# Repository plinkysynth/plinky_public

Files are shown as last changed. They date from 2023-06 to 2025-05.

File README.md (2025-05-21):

# plinky

an 8 voice touch synth - https://plinkysynth.com

Plinky started life as a hobby project that spiralled out of control, was sold for a while on Thonk as a kit, went out of stock during the post-covid chip shortage, and was then rescued by various wonderful people in the Plinky community. Alogn the way, it got open sourced - both hardware and software. You are in the right place for that!

## OPENSOURCE SOFTWARE CREDITS

You can see that the software has largely been stagnant since original release; however in early 2025, a hero by the name of **RJ** stepped up and contributed some incredible improvements, rewriting large parts of the Sequencer and MIDI implementation. Plinky as of version 0.B0 (to be released shortly at the time of writing) is going to be by far the best version of plinky Ever, by far. HUGE thanks to RJ for really pushing plinky closer to its full potential.

Release Notes are available in the [Release Notes](release_notes.md) document for the newer firmware versions.

If you want to get in on the action, join the Plinky Discord (see details at [plinkysynth.com](https://plinkysynth.com) and check out the `#beta-firwmare` channel) or check out the [sw/](/sw/) folder here. Special shout out to **@whocano** in that channel who beta-tested the new fixes from RJ. See, plinky is a team effort? It is truly a special community. Thankyou from the bottom of my heart. 

## OPENSOURCE HARDWARE CREDITS
But plinky is not just software; It's a physical thing!

Many thanks to the people who worked so hard to make opensource plinky a reality, far better than the original version (V1) and (V2) that I stumbled through creating. V3 was a product of the Plinky Discord community, especially:

* **Stijn** from [This Is Not Rocket Science](https://www.thisisnotrocketscience.nl/) routed the original Version 3.
* **Steve / Okyreon** from [denki oto](https://www.okyeron.com/denki_oto/about.php) added the LPZW midi circuit to allow plinky to have on-board midi without the expander.
* **Kay** from [LPZW Modules](https://leipzigwest.org/)  then contributed a circuit to fix the input noise, and then polished everything into a 'Version 3.1', which is the current version linked here. Kay also was one of the original people who helped me with the hardware design of V1 and V2.

If you contributed to the open source hardware and I forgot you, please shout at me @mmalex on the Plinky Discord.
Thanks to all the Plinky Discord members for making Plinky ever better!

Although this repo is all about the OSS Plinky, it is, as ever, available from [Thonk](https://www.thonk.co.uk/shop/plinky-kit-001/) in both prebuilt and kit form, and from other retailers including [Schneidersladen](https://schneidersladen.de/en/plinky/). Thanks to [MakingSoundMachines](https://makingsoundmachines.com/) and [LPZW Modules](https://leipzigwest.org/) for manufacturing those for people who are not looking for the full OSS experience :)

## original release note

For posterity, here is what I wrote at Stijn's coffee table as I released plinky into the public, not knowing what would become of it....

I apologise, its been so long since I looked at this, I am releasing a snapshot of what I had on my harddrive after a couple of years of barely being touched. while I am not actively developing plinky, I hope that by open sourcing it I can stimulate the wonderful community who collaborate on the plinky discord. I also hope to help iterate on some of the more obvious bugs, both hardware and software. 

If you are interested in plinky, please feel free to join our discord community. More information at https://plinkysynth.com

License stuff
--
Please refer to the [license](LICENSE.md) for information including stuff about derived works.

Contributing stuff
--
please see [CONTRIBUTING.md](CONTRIBUTING.md) for information on contributing to this project.

Building and stuff
--
**UPDATE Jan 2025** it is now possible to build and debug plinky using the arm-cortex-debug extension in VSCode. notes continue below:

you need [STM32 cube ide](https://www.st.com/en/development-tools/stm32cubeide.html), its basically the default project so most of the code is in [/sw/Core/Src](/sw/Core/Src), most of the rest of the [/sw](/sw) folder is just the usual auto generated boilerplate mess.

It would be a useful project to update the firmware to build with a more minimal setup; the only significant middleware used relates to USB; while I lean on the STM default project a little, I imagine that the peripheral code could be modified fairly easily.

it should also compile as an emulator for mac and windows, using portaudio and dear imgui. it also compiles for wasm, somehow... I imagine that following the path of the WASM emulator, it would be relatively easy to port plinky to software plugin type platforms.

there is also a [bootloader](/bootloader/) project... I forget exactly how it relates to the final build process. Consider that a TODO to document :)

the hardware is mostly in the [hw/](/hw/) folder, but I was new to kicad so I am not sure if all the library stuff is in the right place.

if there is something missing or something in there that you think shouldn't be in there, let me know and I can sort it out

Thanks again!
--
Many thanks to the plinky community, who have helped plinky evolve and kept the dream alive over a few years. 

* Thanks to Steve from https://thonk.co.uk who encouraged plinky into existence and helped produce the kits; 
* to Kay from https://leipzigwest.org/ for tireless hardware help, encouragment and pre-made plinkys! 
* To Stijn from http://www2.thisisnotrocketscience.nl/ for support, hardware help, and the impetus to opensource this. 
* To MakingSoundMachines from https://makingsoundmachines.com/ for carrying the torch for the new Thonk kits and prebuilt versions, as well as representing Plinky at shows such as Superbooth. 
* to RJ for the incredible bugfixes and rewrites in the firmware that make plinky actually usable as a midi device and touch sequencer. <3
* to Okyeron for V3 hardware work
* to Miunau for the plinky website and continual encouragement, and the original wavetables
* to Meska, LPZW and Grain Blanc for preset packs
* to CrazyEmperor893, SwampFlux, ld, orangetronic, Zifor, tubbutec and many others on the plinky discord for keeping plinky alive and well while I was away.
* to all the people I have missed out, I have a terrible memory, please shout at me if you can see anyone missing from this list who deserves to be here.

Cheers all! 

-- [mmalex](https://twitter.com/mmalex)

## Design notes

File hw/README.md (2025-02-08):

kicad hardware files for plinky
==

## OPENSOURCE HARDWARE CREDITS
Many thanks to the people who worked so hard to make opensource plinky a reality, far better than the original version.

* **Stijn** from [This Is Not Rocket Science](https://www.thisisnotrocketscience.nl/) routed the original Version 3.
* **Steve / Okyreon** from [denki oto](https://www.okyeron.com/denki_oto/about.php) added the LPZW midi circuit to allow plinky to have on-board midi without the expander.
* **Kay** from [LPZW Modules](https://leipzigwest.org/)  then contributed a circuit to fix the input noise, and then polished everything into a 'Version 3.1', which is the current version linked here. Kay also was one of the original people who helped me with the hardware design of V1 and V2.

If you contributed to the open source hardware and I forgot you, please shout at me @mmalex on the Plinky Discord.
Thanks to all the Plinky Discord members for making Plinky ever better!

------
## The Main Folders:

[BOM.md](/hw/BOM.md) contains a list of parts you'll need to recreate the kit, apart from the actual PCBs.

[plinkyblack](/hw/plinkyblack/) contains the files for the main plinky pcb, OSS edition. this was originally called v3.1 LPZW, and represents the latest and greatest OSS hardware release, thanks to LPZWModules for the most recent revision. See the credits paragraph above for more information on all the great people who helped on the hardware side to make OSS plinky a reality (and much better than the original plinky!)

[plinkyblackfront](/hw/plinkyblackfront/) contains files for the front and back panels. The plinky production runs with LEDs premade used front panels mdae by pcbway, while the ones without LEDs were made by jlcpcb. The back panels were made by jlcpcb.

[plinkyblackfront_osh](/hw/plinkyblackfront_osh/) is a variation of the front panel with the OSH logo replacing the plinky logo's dot on the i.

## Additional Folders:

[testjig](/hw/testjig/) contains files for the testjig used to test plinky and flash it, calibrate CVs and so on, used during manufacturing of the kits.

[expander](/hw/expander/) contains a snapshot of the expander, which is also available on [github](https://github.com/plinkysynth/plinky-expander)

## Older stuff:

There is also a big folder of archived old designs. this is now in [archived](/hw/archived/).

[archived/v2](/hw/archived/v2/) is the hardware design used most recently for plinky kits. it was manufactured by both pcbway and jlcpcb. there are BOM and POS files in here for JLCPCB to do the SMT assembly, and this was recently (jan-2023) tested in a small run.

[archived/WIP_inputfix](/hw/archived/WIP_inputfix/) has been updated to kicad 7 and has yet to be manufactured (as of june-2023); we are revising it to reduce input noise and improve the physical dimensions of some ports and the expander port hole.

[archived/plinkyblack_hwmidi](/hw/archived/plinkyblack_hwmidi/) Kicad 7 version modified by @okyeron which adds hardware MIDI in/out on the front of the device. Includes modifications from WIP_inputfix

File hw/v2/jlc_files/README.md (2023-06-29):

these are the most recent BOM and POS files I used to manufacture plinky mainboards at JLC. note however that I cant guaruntee that they match the kicad files exactly, so please check carefully before spending real money!

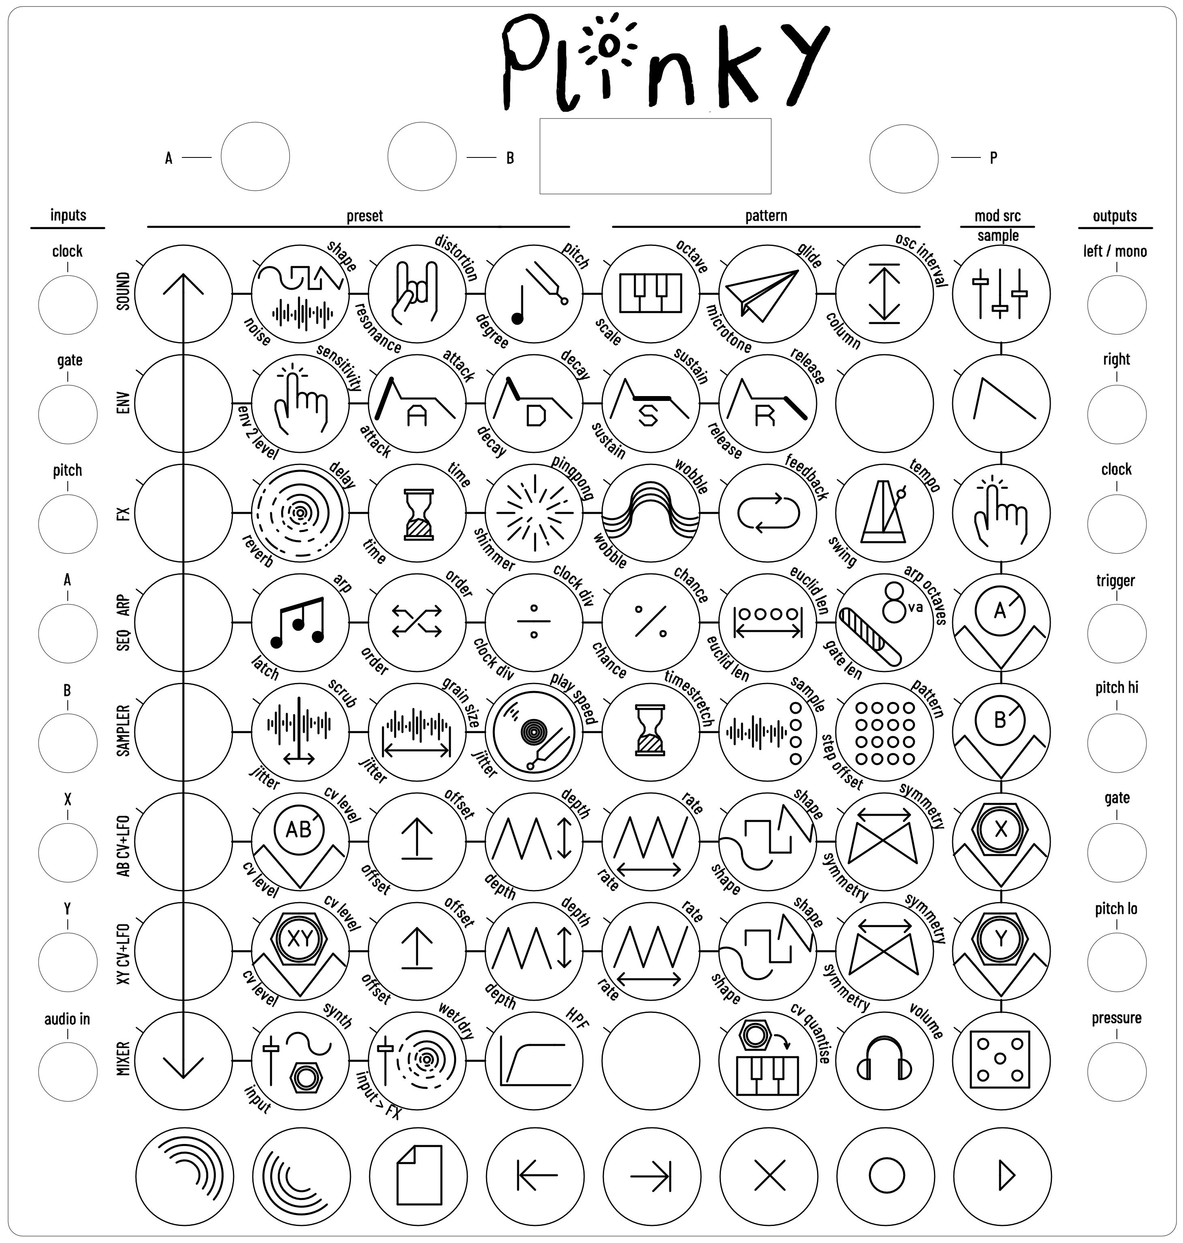
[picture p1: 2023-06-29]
docs/plinky_black.png

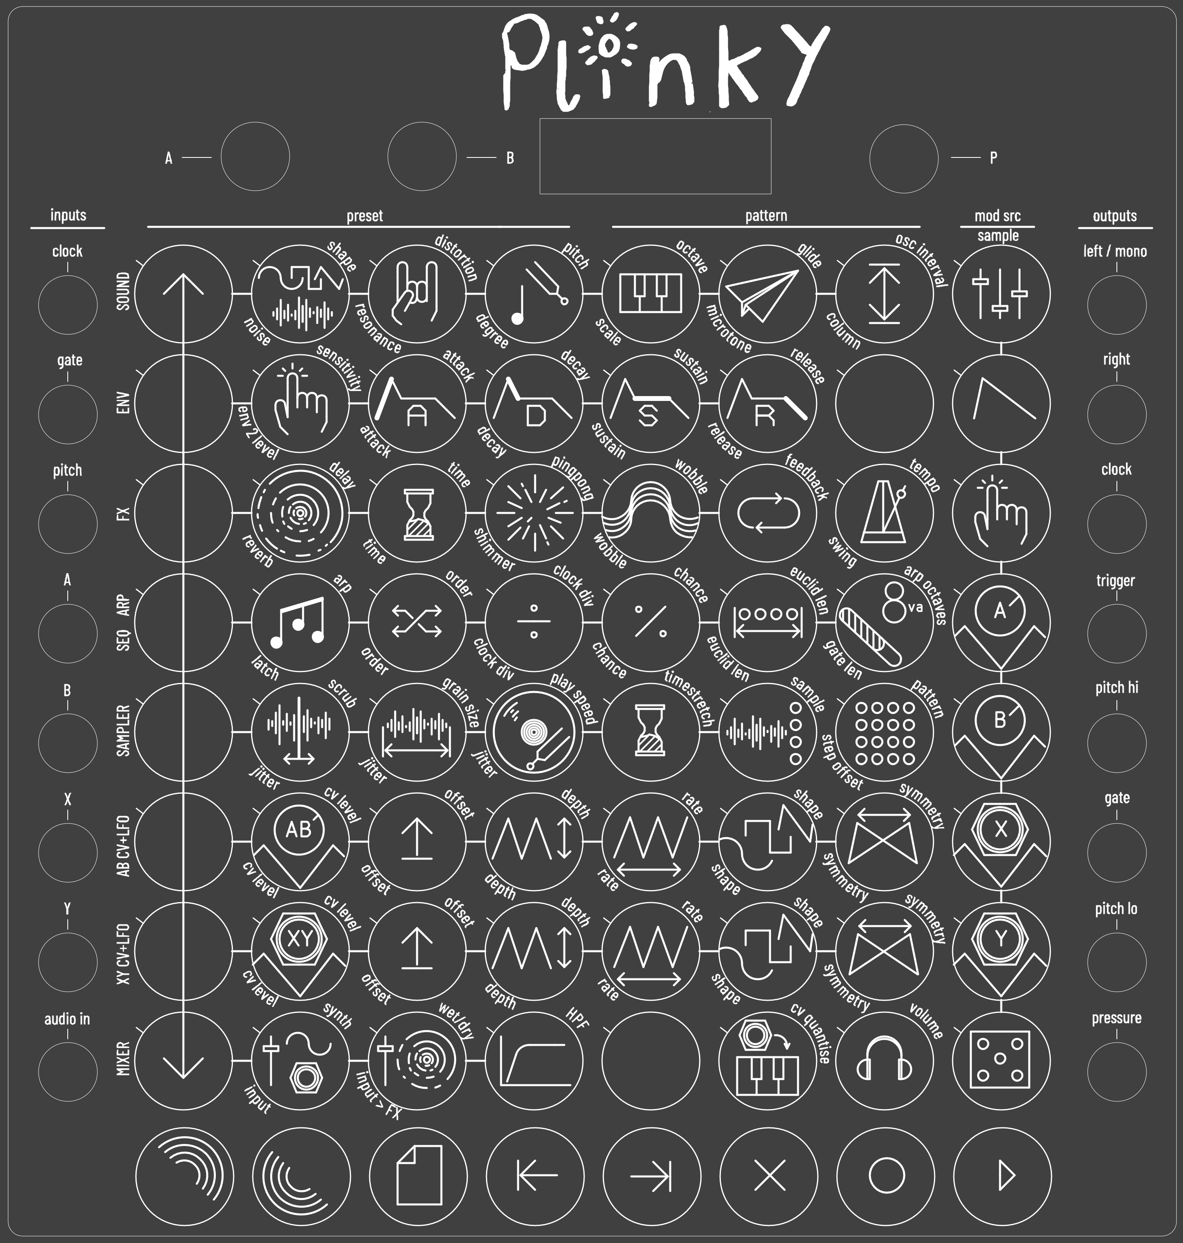
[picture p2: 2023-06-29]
docs/plinky_alpha.png

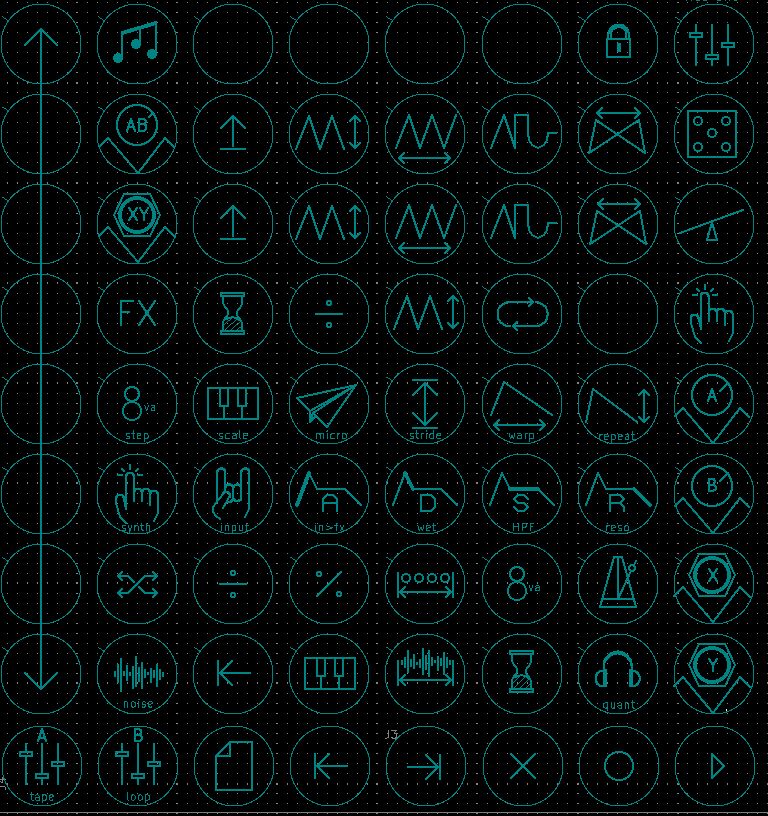
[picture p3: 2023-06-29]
sw/emu/buttons.jpg

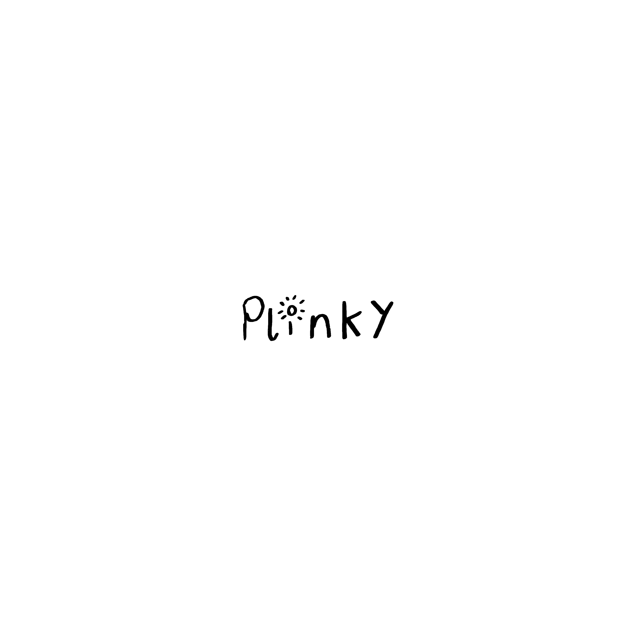
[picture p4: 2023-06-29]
sw/emu/plinkydots4k.png

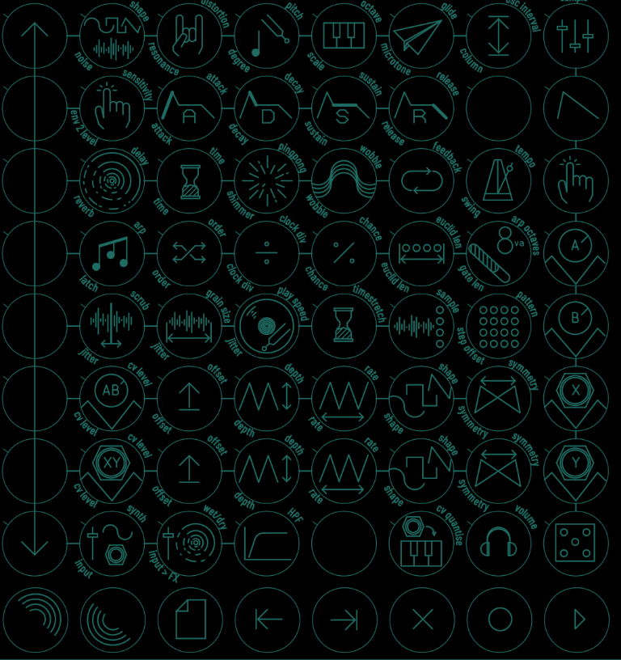
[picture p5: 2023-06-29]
sw/emu/buttons_v2.jpg

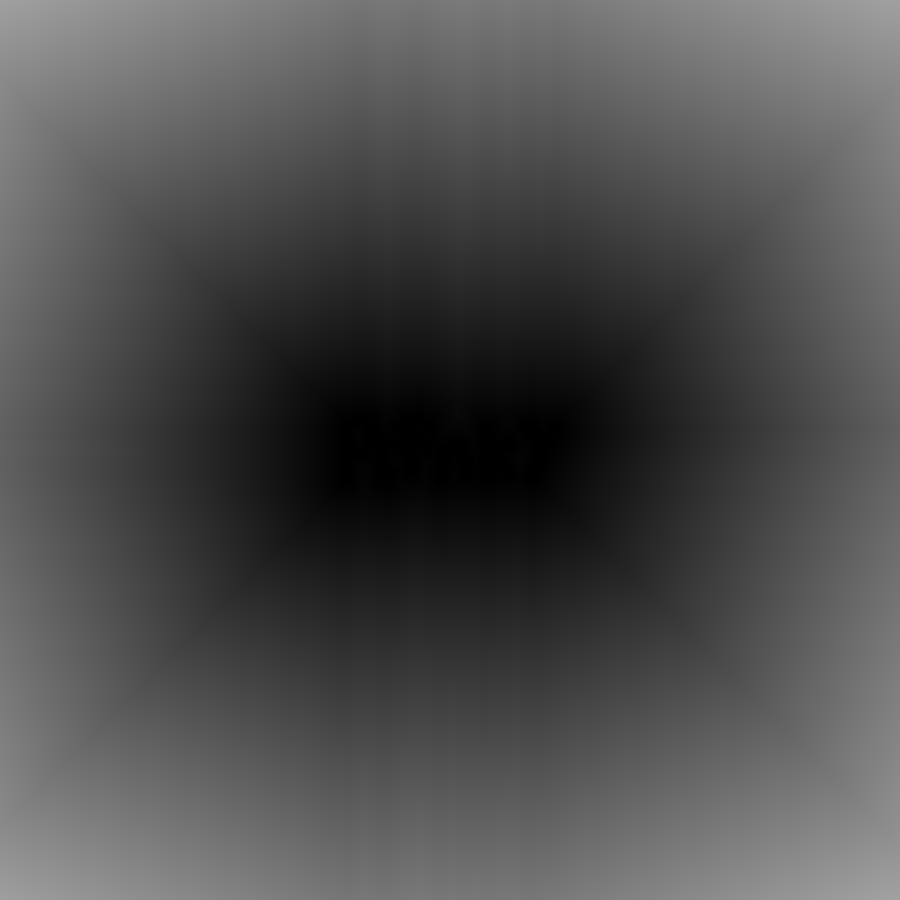
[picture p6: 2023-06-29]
sw/emu/plinkysdf.png

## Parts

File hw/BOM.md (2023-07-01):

|Plinky BOM |qty|part number with example supplier link |
|---|---|---|
|mainboard |1 |[jlcpcb](https://jlcpcb.com) |
|front panel |1 |[pcbway](https://pcbway.com) |
|back panel |1 |[jlcpcb](https://jlcpcb.com) |
|knobs |3 |[aliexpress](https://www.aliexpress.com/snapshot/0.html?productId=32947258241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)|
|encoder |1 |[digikey](https://www.digikey.co.uk/product-detail/en/bourns-inc/PEC11R-4115K-S0018/PEC11R-4115K-S0018-ND/4699207) |
|header pins |2 |[digikey](https://www.digikey.co.uk/product-detail/en/amphenol-icc-fci/95278-101A16LF/609-3486-2-ND/1486797) |
|headphone jack |4 |[digikey](https://www.digikey.co.uk/product-detail/en/cui-devices/SJ1-3523N/CP1-3523N-ND/738689) |
|screen |1 |[aliexpress](https://www.aliexpress.com/item/32961279307.html?spm=a2g0s.9042311.0.0.4b944c4dSUuwQK) |
|16 pin right angle pwr hdr |2 |[rapid](https://www.rapidonline.com/truconnect-16-way-idc-right-angled-boxed-header-2-54mm-pitch-19-0043) |
|15mm M3 black hex spacers |4 |[tme](https://www.tme.eu/gb/details/tff-m3x15_dr185/plastic-standoffs/dremec/185x15/) |
|**THONK STOCK:** | | |
|thonk jacks |13 |[thonk](https://www.thonk.co.uk/shop/3-5mm-jacks/) |
|thonk stereo green jacks |3 |[thonk](https://www.thonk.co.uk/shop/3-5mm-jacks/) |
|25k OR 50k alpha vertical pot linear T18|2 |[thonk](https://www.thonk.co.uk/shop/alpha-9mm-pots-vertical-t18/) |
|hex nuts |16 |[thonk](https://www.thonk.co.uk/shop/3-5mm-jacks/) |
|black m3 6mm screws |8 | |
|euro 16 pin power cable |1 |[thonk](https://www.thonk.co.uk/shop/eurorack-power-cables/) |
|sticky feet |4 |[rapid](https://www.rapidonline.com/affix-2125-pu-round-protective-feet-12-7mm-x-3-5mm-black-sheet-100-31-0668) |

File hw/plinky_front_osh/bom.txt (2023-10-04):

Front panel BOM
White LEDS - 64x - D1-D64 - IN-S124ARUW	 - https://www.digikey.co.uk/product-detail/en/inolux/IN-S124ARUW/1830-1119-1-ND/7604662
Blue LEDS - 8x - D65-D72 - IN-S124ARB - https://www.digikey.co.uk/product-detail/en/inolux/IN-S124ARB/1830-1117-1-ND/7604658
Connectors - 2x - J1, J2 - 89898-308ALF - https://www.digikey.com/en/products/detail/amphenol-icc-fci/89898-308ALF/1537934

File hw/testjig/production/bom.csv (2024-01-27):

Designator | Footprint | Quantity | Value | LCSC Part #
C1 | 603 | 1 | 100n | C14663
D1, D2, D3, D4, D5, D7 | 603 | 6 | LED | C72038
D8 | LED_RGB_1210_reverse | 1 | LED_RABG | C264508
J44 | USB_Micro-B_Molex-105017-0001 | 1 | USB_B_Micro | C136000
J45 | PinHeader_2x07_P1.27mm_Vertical_SMD | 1 | Conn_02x07_Odd_Even | C5160763
J53 | CUI_SJ1-3523N | 1 | SJ1-3523N-cap | C18594
R1, R11, R13, R2 | 603 | 4 | 10k | C25804
R10, R12, R7, R8, R9 | 603 | 5 | 100 | C22775
R14, R5, R6 | 603 | 3 | 1k | C21190
R3, R4 | 603 | 2 | 220 | C22962
U1 | SOIC-24W_7.5x15.4mm_P1.27mm | 1 | CD74HC4067M | C2992617

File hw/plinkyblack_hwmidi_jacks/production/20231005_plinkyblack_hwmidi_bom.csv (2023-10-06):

Designator | Footprint | Quantity | Value | LCSC Part #
C1, C11, C16, C17, C18, C19, C22, C23, C25, C28, C35, C36, C37, C40, C41, C50, C51, C52, C53, C56, C57, C58, C59, C64, C68, C69, C70, C73, C74, C77, C78, C81 | 0402 | 32 | 100n | C14663
C10, C2, C26, C30, C66, C67, C71, C72, C79, C9 | 0805 | 10 | 10u | C15850
C12, C14, C15, C65 | 0603 | 4 | 18p | C1647
C20, C21, C75, C76 | 0603 | 4 | 220p | C1603
C24, C27, C29, C3, C31, C32, C33 | 0603 | 7 | 4.7u | C19666
C34, C4, C54 | 0402 | 3 | 1u | C15849
C38, C39, C44, C45, C46, C47, C48, C49, C5, C6, C60, C61, C62, C63, C7, C8 | 0603 | 16 | 4.7n | C53987
C42, C43 | CP_Elec_6.3x5.9 | 2 | 220u | C250009
C55 | 0603 | 1 | 10n | C57112
D1, D10, D11, D2, D3, D4, D5, D6, D7, D8, D9 | D_SMA | 11 | D_Schottky | C8678
D12 | 0603 | 1 | RED | C2286
D14, D15, D16, D17, D18, D19, D20, D21 | D_SOD-323 | 8 | 1N4148WS | C2128
D23 | 0603 | 1 | BLUE | C72041
FB1 | 0805 | 1 | Ferrite_Bead_Small | C1017
J18, J24 | USB_Micro-B_Molex-105017-0001_with_3d | 2 | USB_B_Micro | C136000
J29, J30 | LUOYANG-DISHANG_PJ-320B | 2 | PJ-320B | C18594
L1 | L_Murata_LQH55DN_5.7x5.0mm | 1 | 10uH | C139506
Q1 | SOT-23 | 1 | MMBT3904 | C20526
R1, R103, R104, R22, R26, R27, R3, R32, R33, R36, R4, R5, R8 | 0402 | 13 | 100k | C25803
R10, R11, R12, R30, R31, R42, R46, R85, R86 | 0402 | 9 | 22k | C31850
R100, R29, R38, R39, R97 | 0603 | 5 | 2k2 | C4190
R101, R102 | 0402 | 2 | 12k | C22790
R106, R13, R23, R28, R37, R43, R44, R45, R47, R48, R49, R56, R6, R66, R67, R83, R84, R87, R88, R89, R90, R98, R99 | 0402 | 23 | 10k | C25744
R107 | 0603 | 1 | 470Ω | C23179
R108, R109 | 0603 | 2 | 220Ω | C22962
R110, R111, R112 | 0603 | 3 | 47Ω | C23182
R113 | 0603 | 1 | 15Ω | C22810
R14, R15, R18, R19, R50, R51, R9 | 0402 | 7 | 33k | C4216
R16, R17 | 0603 | 2 | 5.6k | C23189
R2, R94, R95, R96 | 0603 | 4 | 1M5 | C4172
R20, R21, R52, R53, R54, R55, R91, R92 | 0603 | 8 | 1k | C21190
R24 | 0603 | 1 | 8.2k | C25981
R25, R7 | 0603 | 2 | 200k | C25811
R34, R35, R40, R41, R57, R68, R69, R70, R71, R72, R73, R74, R75, R76, R77, R78, R79, R80, R81, R82, R93 | 0402 | 21 | 100R | C25076
R58, R59, R60, R61, R62, R63, R64, R65 | 0603 | 8 | 47R | C23182
U1, U8, U9 | SOIC-8_3.9x4.9mm_P1.27mm | 3 | MCP6002-xSN | C7377
U10, U11, U16, U18, U5, U7 | SOIC-8_3.9x4.9mm_P1.27mm | 6 | TL072 | C6961
U12, U14 | SOIC-8_5.23x5.23mm_P1.27mm | 2 | W25Q32JVSS | C97521
U13 | SOT-23-5 | 1 | TPS61040DBV | C7722
U15 | SOT-23-6 | 1 | USBLC6-2SC6 | C7519
U17 | LGA-12_2x2mm_P0.5mm | 1 | LIS2DH12 | C110926
U2, U3 | SOT-223-3_TabPin2 | 2 | LM1117-3.3 | C6186
U21 | SSOP-8_3.9x5.05mm_P1.27mm | 1 | HCPL-0631-500E | C43949
U4 | LQFP-100_14x14mm_P0.5mm | 1 | STM32L476VGTx | C165886
U6 | QFN-32-1EP_5x5mm_P0.5mm_EP3.45x3.45mm | 1 | WM8758B | C323840
Y1 | Crystal_SMD_Abracon_ABM8G-4Pin_3.2x2.5mm | 1 | Crystal_GND24 | C13738
J12, J13 | PinSocket_2x08_P2.54mm_Vertical | 2 | Conn_02x08_Odd_Even
J1, J10, J11, J14, J15, J16, J17, J2, J22, J23, J3, J4, J6, J7, J8, J9 | thonk_with_3d | 16 | AudioJack2_SwitchT
H1, H2, H4 | MountingHole_3.2mm_M3 | 3 | MountingHole
J20 | oled091 | 1 | oled0.91
J25 | IDC-Header_2x08_P2.54mm_Horizontal | 1 | Conn_01x16_Female
J19, J21, J26, J27 | CUI_SJ1-3523N_double | 4 | SJ1-3523N
J5 | PinHeader_2x07_P1.27mm_Vertical_SMD | 1 | SWD header
JP1 | IDC-Header_2x08_P2.54mm_Horizontal | 1 | Euro power
JP2, JP3, JP4 | SolderJumper-2_P1.3mm_Open_Pad1.0x1.5mm | 3 | SolderJumper_2_Open
RV1, RV2 | pot3d | 2 | 100k
TPDEBUG1, T_JTCK1, T_JTMS1, T_NRST1, T_VBUS1 | TestPoint_Pad_D1.0mm | 5 | TestPoint

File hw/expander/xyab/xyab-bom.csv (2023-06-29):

Comment | Designator | Footprint | LCSC
10n | C10,C11,C12,C13 | Capacitor_SMD:C_0603_1608Metric
100n | C1,C3,C4,C5,C6,C7,C8,C9 | Capacitor_SMD:C_0603_1608Metric
LED_Dual_2pin | D1,D2,D3,D4 | LED_THT:LED_D5.0mm
Conn_02x08_Odd_Even | J1 | Connector_PinHeader_2.54mm:PinHeader_2x08_P2.54mm_Vertical
AudioJack2_SwitchT | J2,J3 | Connector_Audio:Jack_3.5mm_QingPu_WQP-PJ398SM_Vertical_CircularHoles
Conn_02x05_Odd_Even | J4 | Connector_PinHeader_2.54mm:PinHeader_2x05_P2.54mm_Vertical
AudioJack3 | J5,J6,J7,J8 | Connector_Audio:Jack_3.5mm_QingPu_WQP-PJ398SM_Vertical_CircularHoles
USB_B | J9 | Connector_USB:USB_B_TE_5787834_Vertical
SolderJumper_2_Open | JP1,JP2,JP3 | Jumper:SolderJumper-2_P1.3mm_Open_Pad1.0x1.5mm
10R | R7,R8,R10,R11,R12 | Resistor_SMD:R_0603_1608Metric
10k | R4,R13,R14,R15,R16 | Resistor_SMD:R_0603_1608Metric
56k | R17,R18,R19,R20 | Resistor_SMD:R_0603_1608Metric
220R | R2,R3,R6,R9,R21,R22,R23,R24,R29 | Resistor_SMD:R_0603_1608Metric
3k | R1,R25,R26,R27,R28 | Resistor_SMD:R_0603_1608Metric
7.5k | R5 | Resistor_SMD:R_0603_1608Metric
LM4040DBZ-2.5 | U1 | Package_TO_SOT_SMD:SOT-23
SN74LVC1G17DBV | U2 | Package_TO_SOT_SMD:SOT-23-5
HCPL-0631 | U3 | Package_SO:SOIC-8_3.9x4.9mm_P1.27mm
DAC7554IDGS | U4 | Package_SO:MSOP-10_3x3mm_P0.5mm
TL072 | U5,U6,U7,U8 | Package_SO:SOIC-8_3.9x4.9mm_P1.27mm

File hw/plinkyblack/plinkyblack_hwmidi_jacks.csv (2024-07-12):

Comment | Designator | Footprint | LCSC Part #
100n | C1,C11,C16,C17,C18,C19,C22,C23,C25,C28,C35,C36,C37,C40,C41,C50,C51,C52,C53,C56,C57,C58,C59,C64,C68,C69,C70,C73,C74,C77,C78,C81 | C_0402_1005Metric | C307331
10u Unpolarized capacitor | C2,C9,C10,C26,C30,C66,C67,C71,C72,C79 | C_0805_2012Metric | C15850
4.7u Unpolarized capacitor | C3,C24,C27,C29,C31,C32,C33 | C_0603_1608Metric | C19666
1u Unpolarized capacitor, small symbol | C4,C34,C54 | C_0402_1005Metric | C52923
4.7n Unpolarized capacitor | C5,C6,C7,C8,C38,C39,C44,C45,C46,C47,C48,C49,C60,C61,C62,C63 | C_0603_1608Metric | C53987
18p Unpolarized capacitor | C12,C14,C65 | C_0603_1608Metric | C1647
220p Unpolarized capacitor | C20,C21,C75,C76 | C_0603_1608Metric | C1603
220u | C42,C43 | CP_Elec_6.3x5.9 | C134877
10n Unpolarized capacitor, small symbol | C55 | C_0603_1608Metric | C57112
D_Schottky Schottky diode | D1,D2,D3,D5,D6,D7,D8,D9,D10,D11 | D_SMA | C8678
1N5819WS Schottky diode | D4,D13,D22 | D_SOD-323_HandSoldering | C191023
RED Light emitting diode | D12 | LED_0603_1608Metric | C2286
1N4148WS 75V 0.15A Fast switching Diode, SOD-323 | D14,D15,D16,D17,D18,D19,D20,D21 | D_SOD-323 | C2128
BLUE Light emitting diode | D23 | LED_0603_1608Metric | C72041
Ferrite_Bead_Small | FB1 | L_0805_2012Metric | C1017
SWD header Generic connector, double row, 02x07, odd/even pin numbering scheme (row 1 odd numbers, row 2 even numbers), script generated (kicad-library-utils/schlib/autogen/connector/) | J5 | PinHeader_2x07_P1.27mm_Vertical_SMD | C3975190
PJ313 Audio Jack, 3 Poles (Stereo / TRS) | J28,J29,J30,J31,J32,J33 | AUDIO-TH_PJ-313_5JCJ | C668607
10uH Inductor | L1 | L_Murata_LQH55DN_5.7x5.0mm | C181721
MMBT3904 0.2A Ic, 40V Vce, Small Signal NPN Transistor, SOT-23 | Q1 | SOT-23 | C20526
100k Resistor | R1,R3,R4,R5,R8,R22,R26,R27,R32,R33,R36,R103,R104,R119 | R_0402_1005Metric | C25741
1.5M Resistor | R2,R94,R95,R96 | R_0603_1608Metric | C4172
10k Resistor | R6,R13,R23,R28,R37,R43,R44,R45,R47,R48,R49,R56,R66,R67,R83,R84,R87,R88,R89,R90,R98,R99,R118 | R_0402_1005Metric | C25744
200k Resistor | R7,R25 | R_0603_1608Metric | C25811
33k Resistor | R9,R14,R15,R18,R19,R50,R51 | R_0402_1005Metric | C25779
22k Resistor | R10,R11,R12,R30,R31,R42,R46,R85,R86 | R_0402_1005Metric | C25768
5.6k Resistor | R16,R17 | R_0603_1608Metric | C23189
1k | R20,R21,R52,R53,R54,R55,R91,R92,R110 | R_0603_1608Metric | C21190
8.2k Resistor | R24 | R_0603_1608Metric | C25981
2.2k Resistor | R29,R38,R39,R97,R100 | R_0603_1608Metric | C4190
100R Resistor | R34,R35,R40,R41,R57,R68,R69,R70,R71,R72,R73,R74,R75,R76,R77,R78,R79,R80,R81,R82,R93,R120,R121,R122,R123,R124,R125,R126,R127 | R_0402_1005Metric | C25076
47R | R58,R59,R60,R61,R62,R63,R64,R65,R111,R112 | R_0603_1608Metric | C23182
12k Resistor | R101,R102 | R_0402_1005Metric | C25752
5.1K Resistor | R105,R114,R115,R116,R117 | R_0402_1005Metric | C25905
470R | R107 | R_0603_1608Metric | C23179
220R | R108,R109,R113 | R_0603_1608Metric | C22962
MCP6002-xSN 1MHz, Low-Power Op Amp, SOIC-8 | U1,U8,U9 | SOIC-8_3.9x4.9mm_P1.27mm | C7377
LM1117-3.3 | U2,U3 | SOT-223-3_TabPin2 | C6186
STM32L476VGT6 | U4 | LQFP-100_14x14mm_P0.5mm | C83181
TL072 Dual Low-Noise JFET-Input Operational Amplifiers, DIP-8/SOIC-8 | U5,U7,U10,U11,U16,U18 | SOIC-8_3.9x4.9mm_P1.27mm | C6961
WM8758B | U6 | QFN-32-1EP_5x5mm_P0.5mm_EP3.45x3.45mm | C323840
W25Q32JVSS | U12,U14 | SOIC-8_5.23x5.23mm_P1.27mm | C97521
TPS61040DBV Synchronous Boost Regulator, Adjustable Output up to 28V, 400 mA Switch Current Limit, SOT-23-5 | U13 | SOT-23-5 | C7722
WE-TVS-824001 Low Capacitance TVS Diode Array, 2 Channels, SOT-23-6 | U15,U23 | SOT-23-6 | C111212
LIS2DH12 | U17 | LGA-12_2x2mm_P0.5mm | C110926
TYPE-C-31-M-14 | U19,U20 | HRO_TYPE-C-31-M-12 | C165948
HCPL-0631-500E | U21 | SSOP-8_3.9x5.05mm_P1.27mm | C43949
PI3USB102EZLE | U22 | DIODES_X_QFN10 | C2151020
Crystal_GND24 Four pin crystal, GND on pins 2 and 4 | Y1 | Crystal_SMD_Abracon_ABM8G-4Pin_3.2x2.5mm | C13738

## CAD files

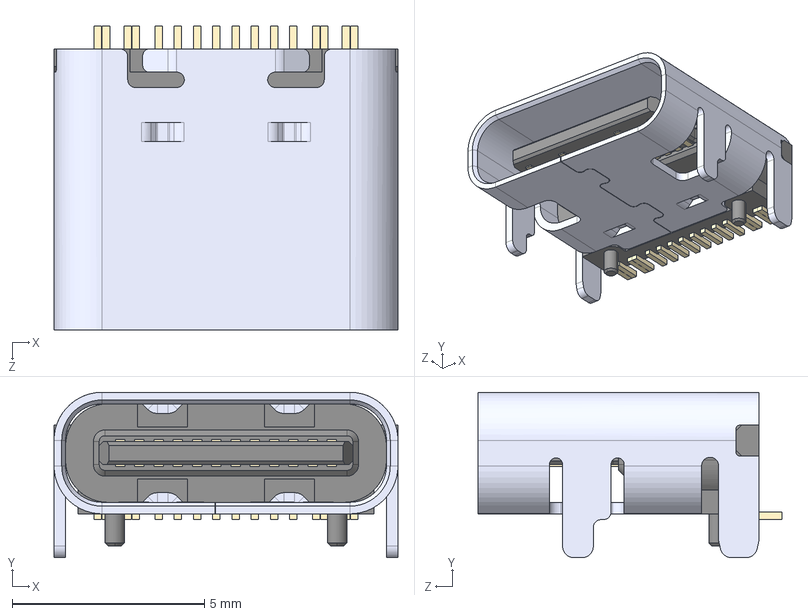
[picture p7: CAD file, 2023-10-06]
hw/plinkyblack/models/TYPE-C-31-M-12--3DModel-STEP-56544.STEP
8.94 x 4.30 x 7.90 mm

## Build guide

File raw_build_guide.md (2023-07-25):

# rough notes on building a plinky from scratch

## hardware

order from JLC :)
TODO more info

## software

### flashing a blank plinky
It's possible to flash a freshly manufactured plinky without building the software. you can get the latest firmware as a .bin file, for example from https://github.com/plinkysynth/plinky_public/raw/main/plink09z.bin
You can also build it from source, more information further down this document.

The bin file is typically named `plink09z.bin` or similar, where the last 3 digits represent the version number. Note that the .uf2 version of this file is just the main firmware, and can be installed via plinky's bootloader (as detailed in the manual). However, that only works once the bootloader is put onto plinky in the first place! a freshly manufactured plinky has no such bootloader, and that's why you need the .bin file. 

The bin file can be placed onto the plinky using STM32CubeProgrammer, which is available for free from [ST here](https://www.st.com/en/development-tools/stm32cubeprog.html). 

At the time of writing, stm32cubeprog seems to have problems running on a mac. The first time you run it, you will see:

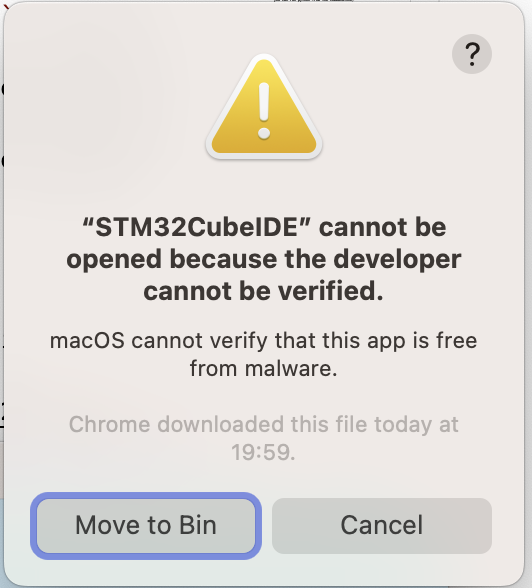
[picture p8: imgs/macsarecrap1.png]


Even after allowing it to run in the Settings & Security part of the OSX control panel by clicking 'open anyway':

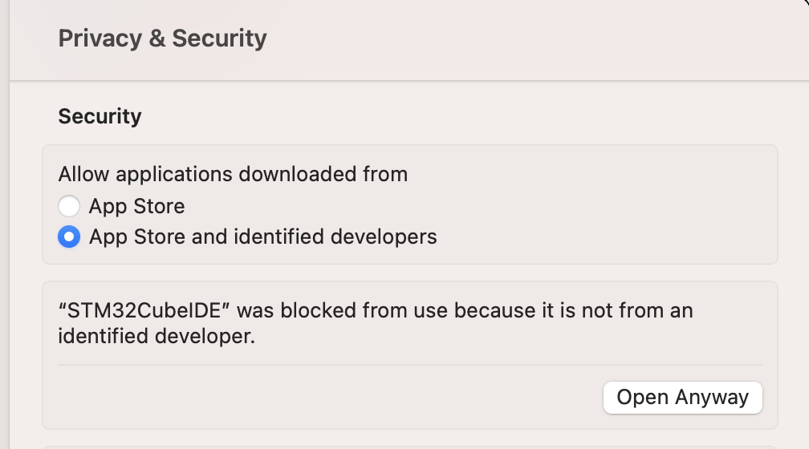
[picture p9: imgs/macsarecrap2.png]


it often hangs or fails to open entirely. I do not know why.. you may need to use a PC, linux, wait for ST to fix it, or fight through various forum posts online, possibly installing outdated JREs and so forth. The page I found most helpful, that got it running for me, was https://community.st.com/t5/stm32cubeprogrammer-mcu/how-to-download-stm32cubeprogrammer-on-macos-monterey-12-6/m-p/143983 - but follow at your own risk!

Assuming you have got it to run... when you run the programmer, you see this screen

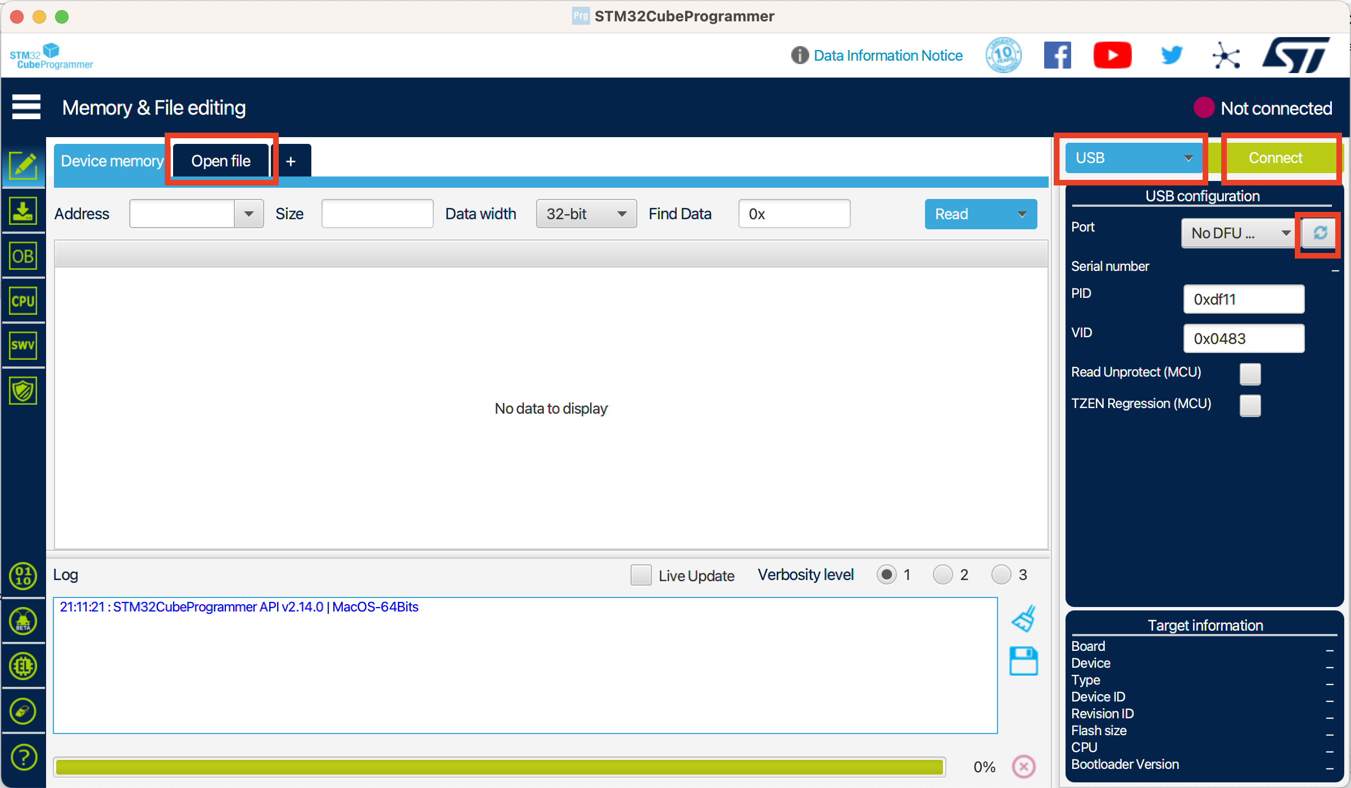
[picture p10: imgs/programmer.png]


Now, connect the plinky - the boot0 way!

What's that you ask?

First, find the 'boot0' and nearby '3v3' pad on the back of plinky. you need to short these together using a piece of metal or pliers or similar, BEFORE and then as you plug plinky in to the computer via USB for the first time. Once power is applied over USB, you can remove your piece of metal. 

Now inside STM32CubeProg, you should be able to load your bin file (click Open file, see red box in screenshot), then on the right side select 'USB' (red box around USB) as the connection type and hit the 'refresh' (small icon button on the far right) button to show the USB device. If it says 'No DFU' like in the screenshot, it means you didn't succesfully short the BOOT0 and 3V3 pins. Unplug plinky, short those pads, and plug it in again. Hit refresh and keep trying until it works. you can then click 'Connect' green button, and then there should be a 'DOWNLOAD' button (not shown in the screenshot) to flash the plinky. It's not a great UI, but hey, complain to ST! :) Anyway, your plinky is now flashed! Unplug it and replug it and it should go into calibration. See the bottom of this document for more information about that process.

### building the firmware from source

* check out the github repo https://github.com/plinkysynth/plinky_public 
* install a fresh install of STM32CubeIDE, available for free from [ST here](https://www.st.com/en/development-tools/stm32cubeide.html) for mac, windows and linux
    * at the time of writing, the latest version is 1.13
    * like STM32CubeProgrammer above, on a mac this will refuse to open the first time. see the discourse above for some tips. the good news is that once you click 'run anyway', it seems more stable than the programmer. 
* you need python 3.x to be installed and working (check if you can run python from the commandline)

On first boot, STM32CubeIDE, after choosing a workspace folder, should present you with a welcome screen that allows you to 'import a project'. Do so, giving this confusing dialog:

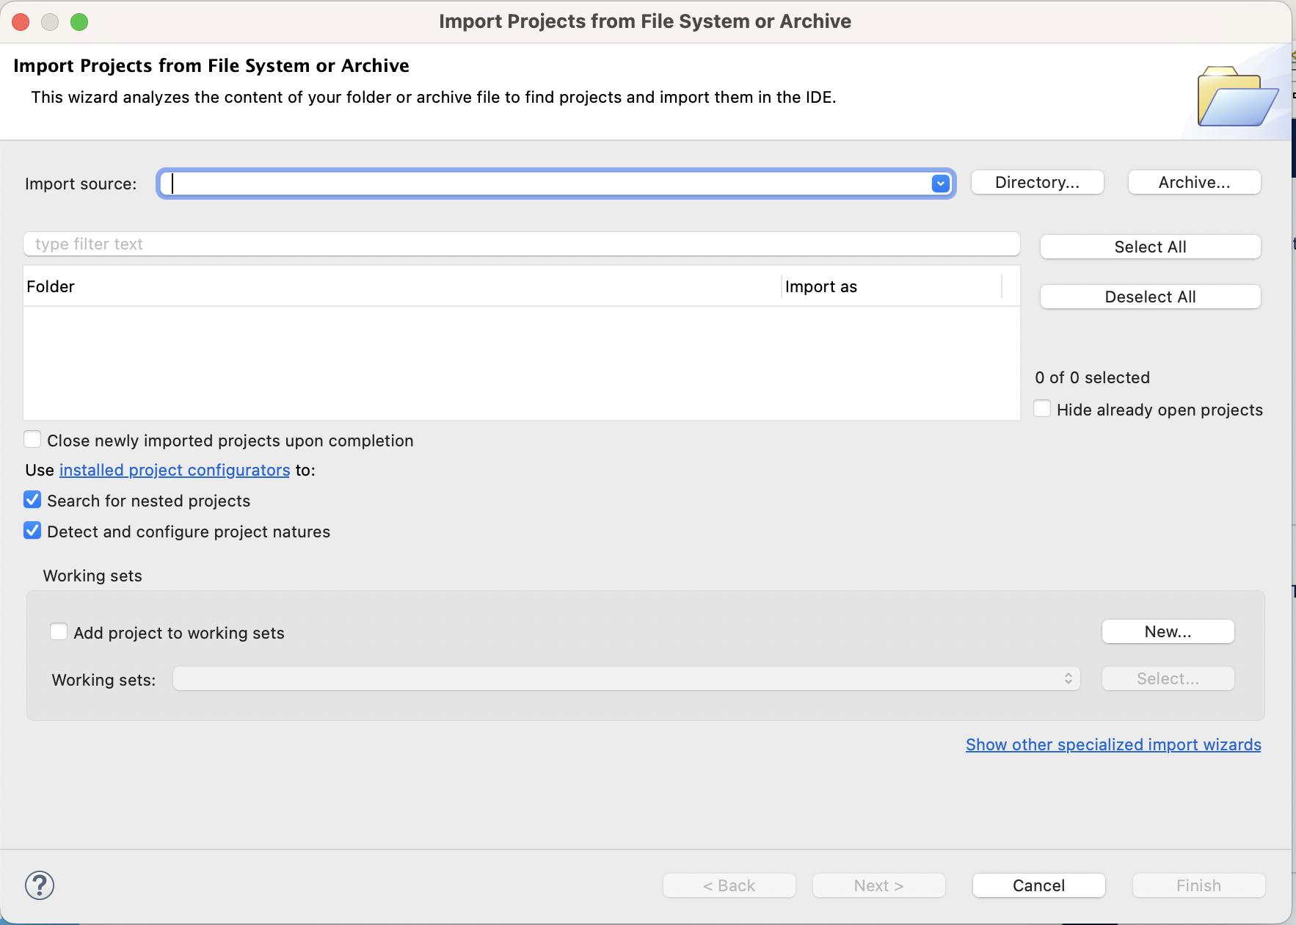
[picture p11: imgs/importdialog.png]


Click 'directory...' and select the directory that is the root of your git checkout. This should then show you 3 projects with checks - the first being the folder as a whole, the second being the 'sw' project (main plinky firmware), and the third being the 'bootloader' project. Make sure the latter two are checked; uncheck the root folder. click ok.

You should see something like this:

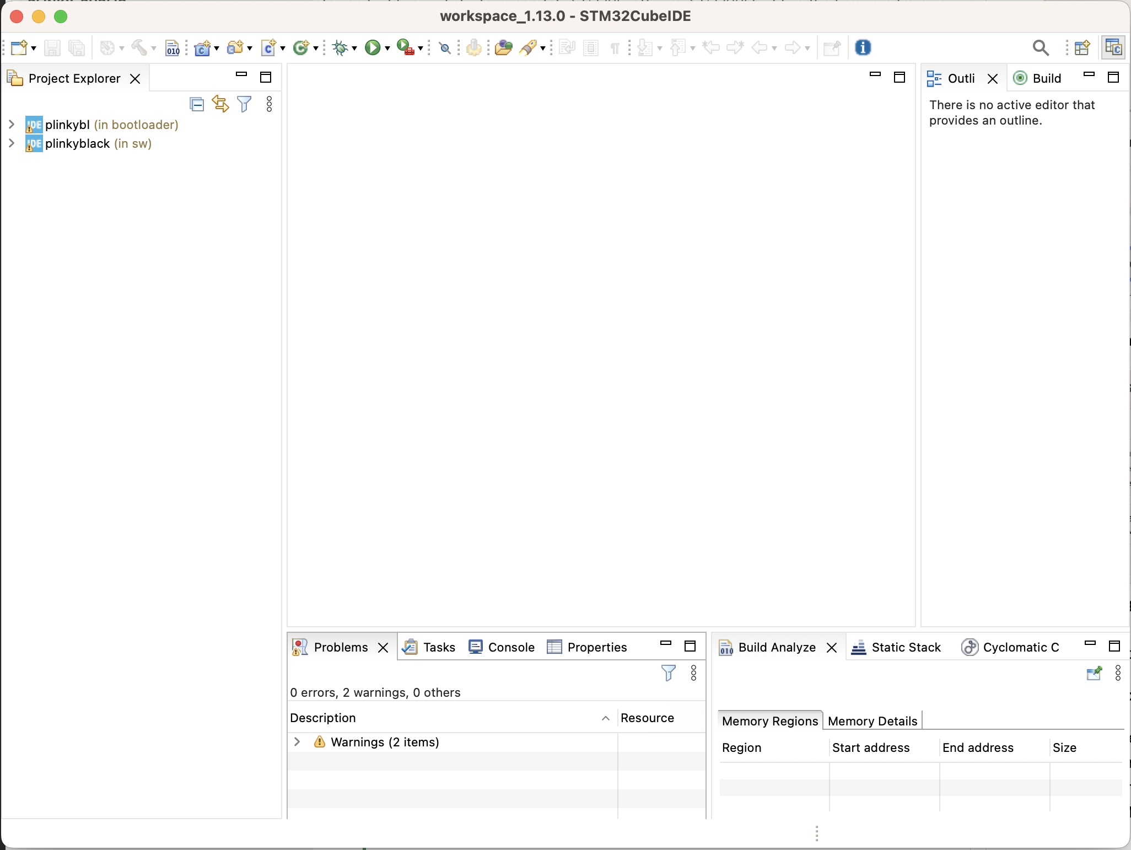
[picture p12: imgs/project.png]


Right click on each of the projects on the left panel, and in the context menu select 'Build Configurations' / 'Set Active' / 'Release'.

Now go to the app's 'Project' menu and select 'Build All'.

If all goes well, that should succeed and write files into the `bootloader/Release` and `sw/Release` folders.

the last step is to run the `binmaker.py` script.
open a terminal window (cmd on windows), in the root of the github repo. run `python binmaker.py` which should output something like:

```
# python binmaker.py
456950 app, 30968 bootloader
bootloader size 65536, app size 456950, version 09z
outputting plink09z.bin...
outputting plink09z.uf2...
Converting to uf2, output size: 873472, start address: 0x8010000
Wrote 873472 bytes to plink09z.uf2
```

CONGRATULATIONS! this generates two files - `plink09z.bin` and `plink09z.uf2` (or whatever version).
the .bin file can be flashed onto a raw plinky using the BOOT0 method outlined at the top of this document.
once a plinky has the bootloader flashed onto it, the uf2 file can be used to update just the app portion, using the method in the public docs.

## troubleshooting

TODO

## booting a raw plinky for the first time

analog voltage calibration process docs todo

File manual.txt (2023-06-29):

this is plinky, an 8 voice polyphonic touch synthesiser that specialises in fragile, melancholic sounds.
it supports 4 external CV modulation sources, called A B X Y, each with its own additional LFO on top.
A & B also have dedicated offset knobs.
think of plinky as 8 vertical monophonic strings, played by touching the 64 main pads.
By default each string quantizes to steps of a C major scale, and the strings are a 5th apart.

Each string has:
- EITHER 4 sawtooth oscillators, detuned by the tiny movements of your finger
- OR 4 sample grains drawn from 1 of 8 samples that you can record into plinky. 
- A white noise oscillator
- an ADSR envelope controlling...
- a resonant 2-pole low-pass gate
- a secondary Attack-Decay envelope with repeat.

Plinky also has global delay, reverb, high pass filter and saturation units along with a simple mixer, arpeggiator and sequencer.

You can play plinky straight away by touching the 64 main pads. The parameters and presets can be accessed using the row of 8 'shift' keys (with blue LEDs) along the bottom, which are then used in conjunction with the main pads to select parameters, presets, sequencer steps, and samples.

Working from the bottom of the panel with the row of shift keys:

Parameters 1/2 (prototype labels this A/B which is confusing. should be 1/2)
The most important buttons!
Tap to enter parameter mode (LED on), then tap one of the main pads to choose a parameter to edit.
You can edit the parameter either with the left most column, which acts as a slider, or by sliding your finger up/down from the icon pad itself. TIP: you can hold the shift key with one hand, and edit the parameter with the other.
Tap 1/2 again to enter slider mode (LED flashing); the left most column remains a single large slider for your chosen parameter, but the rest of the main pads revert to being playable notes. 
Tap 1/2 again to return to play mode (LED off)

Preset Mode (LED on). The left 32 main pads become preset selectors. The middle 24 pads are pattern selectors. The Right most column of 8 pads select/de-select a sample. 
If the sequencer is playing, the change will happen on next loop. 
If you press and hold a preset/pattern pad, the current preset/pattern will be copied over the one you hold.
If you press and hold a sample pad, you go into sample edit/record mode.
Press and hold the X shift button to initialize a preset or clear a pattern.

Previous button - Tap to move back a step (not playing) or reset the sequence (playing). If held down, the current loop is shown on the main pads. Tap a pad inside the current loop to jump to that step, or tap a pad outside the current loop to set a new loop start, that takes effect on next loop.

Next button - Tap to move forward a step. If held down, the current loop is shown on the main pads. Tap a pad to set the end of the current loop.

Clear button - Clears stuff! eg press to cancel a latched chord, to supress notes 'live' from a playing sequence, to wipe a preset or pattern (in preset mode), or to clear note data (in record mode), or enter a rest (in step record mode)

Record button - Toggle record mde on or off. This combines with the play button. When time is running, recording is in realtime. When time is paused, this enables step sequencing.

Play button - toggle time playing.

PARAMETERS
parameters are grouped in rows, from bottom to top. There are two parameters per pad, depending on whether you pressed the Parameter '1' or '2' shift button. Like a primary and secondary function.

SAMPLER ROW
Sample Choice - selects which sample is active, or 0 for none. Allows automation of the current sample
Noise Level - the amount of white noise mixed with the main synth oscillator/sample player.

Scrub - Adds an offset to the position within the sample whence the grains are plucked
Scrub jitter - Randomises the scrub position per grain

Rate - changes the playback rate of the sample, slowing and pitching it like a record. Try negative for reverse
Rate jitter - Randomises the rate per grain

Grain Size - changes the size of each grain, from metallic tiny grains to smooth long grains.
Grain Size Jitter - randomises the grian size per grain

Timestretch - changes the playback rate of the sample, without changing the pitch. Try negative for reverse.
- UNUSED

Headphone Volume - changes the master volume of the headphone jack on the underside of plinky.
Quantise mode - selects how much quantisation is applied to the pitch CV input works, from none, to chromatic, to rotations of the selected scale.

ARP/SEQUENCER ROW
Order - changes the order of notes in the arpeggio
Order - same for Sequencer

Divide - clock divider for the arpeggio
Divide - same for Sequencer

Probability - sets the chance of a note triggering in the arp. Negative values skip, positive values pause. Note that the rhythm is either euclidean or random depending on the next parameter.
Probability - same for Sequencer

Euclid - How many steps in the euclidean rhythm set by the probability. 1 or 0 steps mean 'random'.
Euclid - same for sequencer

Arp Octave - how many octaves to spread the Arp over
Seq Pattern - current pattern. allows CV / LFO control over sequencer pattern choice.

Tempo - tap repeatedly to set a tap tempo, or use as a slider to set BPM. if a 1/16th note clock pulses are received on the clock CV input, this is updated automatically.
Seq Step - current step. allows CV / LFO control over sequencer step playback

VCA/MIXER ROW
Sensitivity - how much pressure is needed to fully open the low pass gate. low values give softer sine sounds.
Input Level - level of the audio input jack, that is sent to output

Drive - output drive level of the synth, before fx. High levels cause extreme guitar-like screams with polyphonic chords, due to intermodulation distortion. 
Synth Level - level of the dry synth audio in the output. can be used to compensate for high drive levels being loud.

Attack - attack time of the envelope that drives the low pass gate.
In->FX level - wet level for the input audio

Decay - decay time of the envelope that drives the low pass gate
Wet - wet/dry level for the fx. bipolar

Sustain - sustain level of the envelope that drives the low pass gate
High Pass Cutoff - cutoff frequency for the global high pass filter, good for taming any boominess

Release - release time of the envelope that drives the low pass gate
Resonance - unruly resonance control for the low pass gates. 

PITCH ROW
Octave - base octave for the synth
Rotate - shifts all notes, but keeping them within the current scale

Pitch - base pitch for the synth. Unquantized.
Scale - selects which scale is used by the pads & rotate feature

Glide - glide time. Each string glides independently
Microtone - amount of quantizing to apply. 0=fully quantized, 100=completely 'analog' pitches
 
Interval - adds a fixed interval between the oscillators on each string. Try +-7 (a fifth) or +-12 (octave)
Stride - sets the interval between successive strings from left to right.

Gate length - turn down from 100% to get more staccato notes from the Arpeggiator and Sequencer.
PWM - at 0%, plinky produces 4 sawtooths per string. Above 0%, it flips & adjusts the phase of 2 of them, giving a pulse/square waveform whose width this controls.

Env2 Rate - controls the speed of the 2nd envelope
Env2 Warp - controls whether the Envelope is a ramp down (-100), a triangle (0), or a ramp up (100)

FX ROW
Delay Send - amount of dry signal to send to delay unit
Reverb Send - same for reverb

Delay Time - length of the delay time. Negative values are beat synced, positive values are free.
Reverb Time - length of the reverb

Second Tap - values less than 100% cause the left and right stereo channels to have different delay lengths, giving a ping-poong effect. Try musical ratios like 50% or 75%.
Shimmer - level of reverb shimmer effect

Delay Wobble - adds a wow/flutter LFO to the delay time, causing pitch shifts.
Reverb Wobble - same for reverb

Feedback - amount of feedback in the delay
Reverb - unused

Env2 Level - amount (depth) of the second envelope
Env2 Repeat - repeat amount. at 100%, the envelope repeats forever; <100%, it decays. 0% - it doesnt repeat.

CV / LFO ROWS - each of the 4 CV modulation inputs is scaled and offset, then added to a dedicated LFO. 
Scale A - attenuverter for the CV input A
Scale B - same for B

Offset A - shift for the CV input A. Dedicated Knob A is always added to this.
Offset B - same for B

Depth A - LFO depth for A. 
Depth B - same for B

Rate A - LFO frequency for A
Rate B - same for B

Shape A - LFO shape for A
Shape B - same for B

Warp A - changes the symmetry of the shape, eg ramp down -> triangle -> ramp up
Warp B - same for B

TOGGLE / PREVIEW ROW
Arp - arp mode on/off

The center 4 pads are always available to preview your patch

Latch - 'latch' previously held notes down

MODULATION SOURCES - Right column
Every parameter for every string has its own sample & hold unit, and can also be modulated from a matrix of 7 sources.
When selecting a parameter to edit (Shift button 1 or 2 held / LED lit), you can also select a modulation source from this rightmost column.
From top to bottom: (NB I should have changed the order to put the 4 modulation sources A B X Y at the top, doh)
Base Value - the value of the parameter before modulation. 
Random - amount of variation to add on each new trigger. Positive values are unipolar, negative values add a bipolar random value 
Pressure - finger pressure -> parameter
Env2 - envelope 2 -> parameter. TIP: try turing this up for the 'Noise' parameter (bottom left pad, Param page 2)
A - input CV A + Knob A + LFO A -> parameter
B - input CV B + Knob B + LFO B -> parameter
X - input CV X + LFO X -> parameter
Y - input CV Y + LFO Y -> parameter

TIP! The modulation source you are editing is remembered. don't forget to 'go back' to the 'base value' (top button) after editing modulations for the other channels.

SAMPLE EDIT / RECORDING MODE
Plinky lets you record and use 8 samples, selected by the 8 sample pads.
if you go into preset mode and long-press one of the 8 sample pads (rightmost column), you enter sample edit mode.
Each sample is split into 8 'slices', corresponding to the 8 columns (strings) of plinky.

To record a sample, press and hold the record  button. Plinky enters a 'set recording level' screen, you can use Knob A to adjust the peak level to neatly fill the screen. There is an additional +6dB headroom beyond this, but very loud inputs may still show 'CLIP!' warning.
Once you are happy, press the Play or Record button to 'arm'. As soon as a sound is heard, or on a second tap of play/record, plinky will start recording. To stop, press play/record again. 
To slice into up to 8 pieces while recording, tap any of the main pad buttons. if you do not tap, plinky will cut the sample into 8 equal length slices, and you can edit the splits later.

Once you have recorded, to audition the slices, press and hold the main pad buttons. if you slide your finger up and down, it adjusts the start point of each slice.

There are two options associated with samples: Tape/Pithc mode and Loop mode. Press the 'Param 1' Button (bottom left) to toggle between Tape and Pitch; Press 'Param 2' Button to cycle loop mode between 'play slice', 'loop slice', 'play all', 'loop all'.
Tape mode lays out the sample slices across all 64 pads, allowing you to quickly play from any point within the sample. The pitch of playback is only affected by the 'sample rate' parameter.

In Pitched mode, each slice is assigned a base pitch, visible like 'C#3' in the display. you can set this reference pitch for each slice, by sliding your finger in the lower half of the main pad area. Now when you perform notes in plinky, it will set up a multisample key-split and choose the closest pitched sample to the desired note. Be careful of octaves to be sure to use all your slices. If multiple slices have the same pitch, they will be round-robined.

CV INPUTS, top to bottom
A B X Y - modulation inputs, each combined with its own LFO. A & B are also combined with the knobs
Pitch - offsets the pitch of the entire synth via 1 V/Oct input. approx -1v to 5v
Gate - modulates the low pass gates of the entire synth. 0-5v
Clock In - 1/16th note clock input, that drives the sequencer and arpeggiator.
Audio In - A signal sent through to the output mixer via FX, also used in sampling mode.

CV OUTPUTS, top to bottom - 
Clock - 1/16th note clock out
Trigger - +6v pulse on every new note
Pitch Hi - 1v/oct pitch of the rightmost string currently playing (respects Arp)
Gate - Analog envelope follower of the loudest string currently playing
Pitch Lo - 1v/oct pitch of the leftmost string held down (ignores Arp)
Pressure - Analog level of heaviest finger press
Right - Right stereo audio out
Left - Left stereo audio out (normalled to mono if no right jack plugged in)

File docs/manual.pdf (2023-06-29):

Plinky is an 8 voice polyphonic touch

synthesiser that specialises in fragile, melancholic sounds.

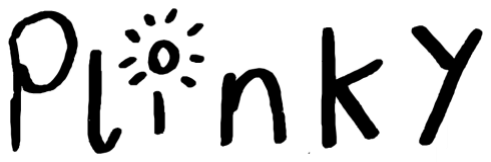
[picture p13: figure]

Think of it as an 8 vertical stringed instrument, played by touching the 64 main pads, which are arranged

in 8 vertical monophonic strips.

You can play Plinky straight away with those 64 main pads. The row of 8 'shift' keys (blue LEDs) along the bottom are used in conjunction with the main pads to select parameters, presets, sequencer patterns, and samples.

Plinky supports 4 external CV modulation sources, called A B X Y, each with its own LFO. A & B also have dedicated physical offset knobs, located either side of the screen.

Each of the 8 strings has:
- 4 sawtooth oscillators or sampler grains, detuned by the tiny movements of your

finger.

- A white noise generator
- an ADSR envelope controlling...
- a resonant 2-pole low-pass gate
- a secondary Attack-Decay envelope with

repeat.

Plinky also has global delay, reverb, high pass filter and saturation units along with a simple mixer, arpeggiator, sequencer and sampler.

I plan to add a compressor in a future update.

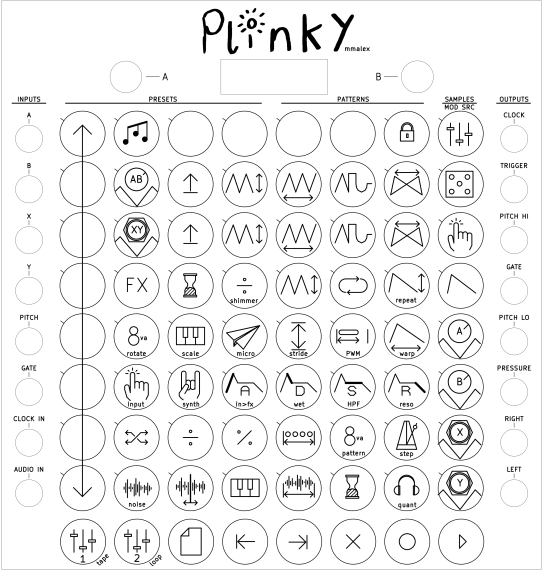
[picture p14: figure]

# Changing the Sound

When you first switch it on, try pressing a few of the main pads. You should hear a supersaw type sound. Enjoy! Now let’s add some delay. The bottom row of buttons, with blue LEDs, work as shift/mode buttons. Tap the bottom left button, the ‘primary’ parameter editing button, referred to as 1w from here

on. Its LED lights, and you are invited to select a parameter – one of the icon pads. Tap the N pad, in

the second column, in the middle. This is the send level to the delay unit. Slide your finger upwards on the leftmost column of pads to increase the amount of delay. To hear this, play notes using the 4 pads at the top which have no icon B. 4 pads note can be a bit restrictive! So tap the bottom left shift key –

1w. Its LED should start flashing. That means you can still use the slider at left to adjust the send level more, but the remaining 56 pads are available to play notes. Play & tweak, then press 1w a last time

when you are ready to return to full ‘play mode’. That’s the basic workflow for creating patches in Plinky!

# Adding Modulation

Let’s use the physical knob at the top of Plinky to adjust overdrive. Tap 1w again, then tap c ⁽leftish

below middle) to select overdrive. Instead of just turning it up with the leftmost slider, this time, first tap a in the right column to select ‘modulation source A’. NOW turn it all the way up with the left slider, then tap top right D to return to ‘base value’, and 1w twice to return to play mode. Now, the physical

knob at the top left of Plinky will control overdrive. That’s as complex as it gets! You now know everything you need to know to play, edit patches and modulate. Enjoy! Details follow.

# Shift Keys

Working from the bottom of the panel with the row of shift keys: NB in the prototype, the first 2 shift keys are printed as ‘A’ and ‘B’ instead of ‘1’ and ‘2’, which is confusing because they have nothing to do with

the A and B modulation sources/knobs. Oops. They should have been labelled 1and 2, and I’ll refer to

them that way in this doc.

Edit Mode The first two shift buttons are the most important: they allow you to modify the sound. Why two? They map to two complete sets of parameters – primary on 1w and secondary on 2x. Tap or hold either, then tap an icon pads to choose a parameter to edit. Once in edit mode, adjust the chosen parameter using the left most column of pads as a slider, or slide the finger on the icon up/down. Tap again (LED flashing) to make most of the main pads playable, leaving the left column as a slider. Tap again to return to play mode (LED off).

Preset Mode Tap or hold, then tap a main pad to select a preset (left 32 pads), pattern (middle 24), or sample (right 8). A long press on a sample pad will edit it; on other pads, it will copy the current preset / pattern to it. Press and hold 1 to clear the last touched preset or pattern.

Previous Button Tap to jump to the previous step (sequencer paused) or first step (sequencer playing). Or, hold it then tap a main pad to jump to a step within the current loop, or to set a new loop start outside the current loop.

Next Button Tap to jump to the next step.
Or, hold it then tap a main pad to set the end of the current loop.

Clear Button Tap or hold to clear stuff. Useful to mute recorded notes, live, while the sequencer is playing. If recording, this will permanently clear steps.
In y mode, hold this after tapping a main pad to clear whole patterns or re-initialize presets.

Play / Record Buttons Tap to toggle playback & recording.
Recording can be step based (when sequencer is paused) or realtime (when sequencer is
playing).

w
x
y
z
0
1
32

# Parameters

Plinky’s parameters are arranged in somewhat logical horizontal rows. Remember to touch/hold 1w or 2x to enter parameter edit mode, then touch a pad with an icon to select that parameter. The left most column then becomes a dedicated slider, or you can slide the finger that’s over the icon up and down. Pressing 1w or 2x again leaves the left slider active, allowing you to continue to tweak a single parameter while playing with the majority of the pads. Pressing 1w or 2x a third time returns to play

mode, with all 64 pads available to play. This is the main workflow when making patches with Plinky.

The leftmost column of pads is a slider. The rightmost column of pads are modulation sources. We’ll cover those later. The middle 6 columns are the parameters themselves. From top to bottom, they are:

Top Row Toggles The top row has a button A to toggle the arpeggiator, and another C to toggle latching of held notes. Press 1 to clear the latch. The 4 buttons B with no icon play notes – they are

available to audition the current sound, even when choosing or editing parameters with the other pads.

A/B Inputs E The next row controls the A & B CV inputs. Shift key 1w gives you parameters for input A and shift key 2x gives you parameters for input B. E is a scale – aka attenuverter, scaling the input voltage. F lets you add on a constant voltage offset. There are also physical knobs at the top of Plinky

that provide an additional offset to inputs A & B. Lastly, each input has a dedicated built in LFO that is added on top – so that these modulation sources can be useful even without any jacks plugged in. G controls the depth of LFO, H the frequency, I its shape, and J its symmetry – for example turning a

triangle wave into a sharp ramp up (symmetry +100) or down (symmetry -100).

X/Y Inputs L These work just like the A/B inputs, except that they do not have dedicated offset knobs at

the top of Plinky.

FX Controls N Shift key 1w controls the delay unit; 2x controls the reverb. O sets the time of the effect; for delay, positive values are not tempo synced, negative values are locked to the clock. P controls a second stereo tap for the delay, giving a ping pong effect. Try musical ratios like 75% and 50%. For reverb, P dials in a shimmer tap. Q controls a tape wobble effect. R sets the delay’s feedback level (unused for reverb). S and the pad below it, Z, are not really FX related. They control a secondary envelope I’ll cover next.

Secondary Envelope As well as the main ADSR envelope, a secondary attack/decay looping envelope is available as a modulation source. For example, try it on pitch or noise level parameters to add a click or glissando at the start of each note. Just two pads, one above the other, control it. S sets the overall level, and for shift key 2x the looping decay (0=no repeat, 100=repeat forever, 50=decay to half each time it loops) Z sets the speed of this envelope, with shift key 2x controlling its symmetry – from sharp

attack / long to decay, thru symmetrical triangle, to long attack and sharp decay.

Pitch Controls For shift key 1w: U sets octave, V sets global pitch (unquantized), W sets glide time between notes. X tunes each voice’s oscillators a fixed interval apart. Try fifths (7 semitones), octaves (+

or -12) and so on.
Y isn’t strictly pitch related – it sets the gate length. Reduce it below 100% to get staccato effects. Z is part of the secondary envelope, above.
For shift key 2x, U allows you to transpose all the notes while staying in-scale (ie quantized transpose). V selects a scale. W controls the amount of microtonality vs quantization when your fingers move

vertically between pads – a small amount is recommended to ensure that the 4 sawtooths are detuned relative to each other. X sets the interval between adjacent strings – typically a fifth. As before, Y isn’t

really pitch – it controls PWM! At 0%, plinky plays 4 sawtooths. Above 0, it flips the phase of two of them, causing interference that gives rise to square/pulse waves, whose duty cycle is controlled by this parameter.

Volume / Envelope / Mix Controls The envelope controls under shift key 1w are fun to fine tune to get the most expression out of Plinky. b sets the sensitivity to pressure; low values mean that the low pass gate won’t open completely, giving softer, sinewave tones instead of sawtooths. You can turn up c drive to compensate for any loss of volume; cranking c further gives strong, guitar-like intermodulation distortion especially when multiple strings are sounding. defg control a classic ADSR envelope,

which opens and closes the low pass gate.

For shift key 2x, you get mixer controls: b sets the input audio level; c sets the dry synth level (can be used to gain stage if, for example, an overdriven preset gets too loud). d controls how much of the input audio is sent to the FX units - +100 is all wet, -100 is all dry, 0 is a mix; e controls an overall wet/dry mix for the effect returns. f is the cutoff of a global highpass filter, which can be useful to ‘thin out’ the sound. g controls resonance of the lowpass gates, which makes Plinky sound more ‘vocal’ or ‘acid’, but can get really unruly and unstable since the cutoff is so tightly connected to variations of pressure in your fingers via the lowpass gate’s ADSR envelope.

Arp / Seq Controls After enabling the arpeggiator A via the top row, this row controls the arpeggiator (shift key 1w⁾ or sequencer (shift key 2x⁾. i controls the order of notes; j is a clock divider. k sets

the probability of a note playing – positive values pause, negative values skip. The rhythm it plays in is Euclidean by default; l sets the length of the Euclidean pattern. If it’s 1 or 0, it switches to random probabilities. m sets the number of octaves for the arpeggiator, or the pattern index for the sequencer (allowing external control of which pattern is loaded into memory). n sets the tempo in BPM – tap

repeatedly to set via tap-tempo; if an external 1/16th note clock is fed to the clock input jack, this will automatically update to reflect it. There is also a clock output jack to control other modules via Plinky’s clock.

Sampler / Granular Controls Select a sample with p ⁽you can also press y to enter preset mode

and then tap one of the rightmost column pads, to change this parameter) scrub through the sample with q, change the playback rate (speed & piotch, including reverse) with r. Grain length is controlled with s, while t creates time stretch effects, including reverse. 1w controls these parameters, while 2x adds jitter to them per grain. u is a system parameter – headphone volume on 1w, pitch input quantization on 2x.

# Modulation

The right-most column of pads can be tapped in edit mode to control a 100+ x 7 modulation matrix. Every parameter can be modulated by any amount of 7 different sources, which are from bottom to top:

The main jack/LFO/knob modulation sources. (I should have put these at the top to line up with the input jacks – I’ll do that on the next prototype). Let’s try connecting mod source B – which includes the right knob at the top of plinky – to pitch. Press shift key 1w to go into parameter edit mode, select V in the 5th row to select unquantized pitch, h in the right column to select mod source B, turn up the amount using the big

slider (left column of pads), then twiddle the physical knob at the top of Plinky as you play on the 4 audition pads in the top row (the ones with no icon). Voila, you have connected modulation source B (which includes that knob) to pitch. Now press the top right pad D to return to ‘base value’ mode (otherwise you’ll forget and go on editing ‘modulation source B amount’ next time you edit a paremeter), and tap 1w twice more (so its LED goes out) if you haven’t already, to return to normal ‘play’ mode.

Secondary envelope, Pressure and Random (sample & hold) respectively. Try routing secondary envelope to the noise amount p in the bottom row (under shift key 2x⁾ to get a ‘snap’ at the start of notes. K is fun because any/every parameter can be individually ‘humanised’ with a small amount of randomness on each trigger. Positive amounts of K modulation give uniform positive offsets; negative amounts give bipolar variations.

Press this top right pad to return to editing the ‘base value’, rather than modulation sources. It’s easy to forget to press this after setting up some fancy modulation; next time you edit a parameter, you’ll wonder why you can’t hear the change. It’s because you’re dialling in some fancy modulation source, instead of setting the parameter directly. D is your friend!

# Jack Inputs and Outputs

The 8 jack inputs, at left, from top to bottom provide:

- modulation (A, B, X, Y) with -5v to 5v range
- a pitch input for transposition via a V/oct input in -2v to 5v range (with quantization controlled by the u secondary parameter)
- an analogue gate that scales the openness of all low pass gates (0-5v)
- a 1/16th note clock input
- an audio input that is mixed with the synth output as well as being sent to the FX units.

The 8 jack outputs, on the right, from top to bottom provide:
- 1/16th note clock out (>5v), (so that plinky can clock other devices)
- Trigger (>5v pulse on every new note)
- pitch hi (1v/oct) of the rightmost note that is playing, respecting the arpeggiator, -1v to 5v
- analogue gate, being the maximum level of all 8 ADSR envelopes
- pitch lo (1v/oct) of the leftmost note that is playing, ignoring the arpeggiator. -1v to 5v - useful as it is usually the bass note
- analogue pressure, being the maximum of all finger pressures detected, ignoring any envelope
- stereo audio out. The lower (left) output can be used as a mono output when nothing is plugged

into the right output.

# Sampling

Plinky lets you record 8 samples, each split into 8 'slices', corresponding to the 8 columns (strings).
Once recorded, the bottom row of parameters control the granular playback of your samples.

To record or edit a sample, press y to go into preset mode, then press and hold one of the 8 rightmost

pads. Now press and hold 2 to record a new sample. Use knob A to adjust the recording level.

Press 2 or 3 to 'arm'. Plinky will start recording when it hears audio, or tap 2/3 again to start

recording silence.

If you want to set the 8 slice points while recording, tap any of the main pad buttons at the start of each slice. If not, Plinky will cut the sample into 8 equal length slices. You can edit the split points later. Press

2/3 any time to stop recording.

When recording is finished, to audition the slices, press and hold the main pad buttons along the top row. If you slide your finger up and down, it adjusts the start point of each slice.

There are two options associated with samples, controlled by the usual 2 parameter shift keys wx:

Tape/Pitch mode and Loop mode.
Press 2x to cycle loop mode between 'play slice', 'loop slice', 'play all', 'loop all'.
Press 1w to toggle between Tape mode and Pitch mode.

Tape mode lays out the sample slices across all 64 pads, top to bottom then left to right, allowing you to

quickly play from any point within the sample by pressing the appropriate pad. The pitch of playback is only affected by the 'sample rate' parameter.

In Pitch mode, each slice is assigned a base pitch, visible like 'C#3' in the OLED display. You can set this

reference pitch for each slice, by sliding your finger in the lower half of the main pad area. Now when you perform notes in plinky, it has set up a multisample key-split and chooses the closest pitched slice to the desired note. Be careful of octaves to be sure to use all your slices. If multiple slices have the same pitch, they will be round-robined.

Press 1 to leave sample edit mode.

# Calibration

When first booted up, Plinky goes into calibration mode. On subsequent boots, to enter calibration

mode, twist either or both of the knobs during power up. Knob A triggers touch calibration, which may be necessary if you move Plinky to a different case, especially one with metal objects near by. Knob B triggers CV 1v/octave pitch calibration, for which you need a multimeter or calibrated oscillator.

Calibration instructions are shown on the screen.

# Thanks

To everyone in the world. Enjoy Plinky!

# voha

# TMK

D

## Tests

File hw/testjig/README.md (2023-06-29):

the plinky testjig is a pcb that I made where I create two, and bolt them together with 5mm hex spacers, then solder pogopins (I forget the size! I got them on amazon lol) that poke thru to a plinky mainboard.
https://www.youtube.com/watch?v=vNIF9_tz35w
in THEORY someone could make one of these 
the advantage is that the jig can be used to flash plinky, and plinky detects that its mounted on a jig, and self calibrates all the AD/DA for cv control, and tests it, and you'll notice in the video a small 3d printed mount that allows you to place an OLED screen and so it tests all that. it also has a jack output and so on...
FANCY!

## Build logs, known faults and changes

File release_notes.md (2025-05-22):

# Plinky Firmware Release Notes

this file serves as a log of changes to the firmware. with many thanks to RJ, who has been providing most of the recent fixes to the firmware, and provided the inaugural B0 notes. 

From newest to oldest:

# v0.B2 - Add Plinky+ detection, general improvements

## Plinky+ detection
- Plinky firmware can now detect whether it's running on a Plinky or a Plinky+

## General fixes/improvements
- There was a bug where if a note was sequenced on the current step and step-recording was active, the sequencer would automatically take a step forward at the release of a midi note, or at the end of previewing the sequenced note. This bug is fixed
- Latched notes are no longer muted when a shift-button is pressed
- Midi notes now also play correctly when they come in almost simultaneously (specifically when sent on the same step by an external sequencer)
- The pressure calculation from CV gate is simplified: 0 - 5V now maps linearly to 0 - 100% pressure
- When Plinky reverts from external clock (euro or midi) to internal because the external clock is no longer present, the sequencer now stops playing
- When Plinky is following its internal clock, the first incoming euro clock will now reset and play the sequencer
- The lfo scope on the right of the display now always shows contiguous lines:
  - When an lfo value is too high/low to fit on the scope, it is clamped to the top/bottom pixel instead
  - Vertical jumps are now also drawn
- Small bugfix for edge cases where the substep timing was not calculated accurately

# v0.B0 - Sequencer, Latch and Midi rewrite
## Deletions
- Latching and sequencing midi notes was never fully implemented, it is now fully removed. This fixes instances where incoming midi notes would clear out the sequencer
- Sequencing movement on the A/B knobs was partly implemented but undocumented. It is now removed but could be added again in a later update
## General improvements
- During the release phase of envelopes, pitches would jump to either the top of the string or the last pressed pitch. This was especially audible with longer release times and on sequenced and midi notes. It sounded like new, unwanted notes were being triggered, but in reality it was the pitch suddenly jumping to a different value. Pitch is now played correctly during the release phase
- In many situations, pressing any of the shift-pads (bottom row) would lead to unexpected results, such as latched or sequenced notes being muted or cut off. This is no longer the case
- The display now shows whether each of the strings is pressed (full bar), ringing out (horizontal line indicates volume level) or silent (horizontal line lies at bottom of screen.)
## Voice allocation
The voice allocation was rewritten and now works as follows:
1. Touches (including latching touches)
2. Sequencer
3. Midi

Touches and sequenced notes are always linked to a string/column. A touched string takes preference over a sequenced note on that string. Midi notes do not have a string by default, they are mapped in the following way:
1. To a quiet string as close as possible to a string that could play the midi pitch
2. When no quiet strings are available, to the most quiet string which is in its release phase
3. When no strings are quiet or in their release phase, all strings are actively being played. The midi note is ignored
## CV Gate
- CV gate is processed after touches, sequencer and midi are handled. Whatever pressure is the result of those gets multiplied by the CV gate voltage
- A low CV gate can no longer un-latch latched notes
## Latching
- Latching now only resets when all fingers are lifted off the pads. This allows for a whole new level of creativity while playing drones or arps, and is by far my favorite new feature
- Latching could complicate step-recording, as both respond to pads being pressed and released. For this reason, you can't start a new latch while in step-recording mode. An existing latch will keep sounding as step-record mode is activated, and can even be modified as long as at least one finger is touching the Plinky. But new latches will not be initiated.
- In live-record mode, latched notes will be recorded as played
- In step-record mode, latches that were started before step-record mode was activated will be recorded into the active step
## Sequencing
- Overdubbing is now fully implemented in both step and live recording modes. If a sequencer step has sequenced notes on some strings, all other strings can be sequenced without clearing existing notes.
- Substeps are now fully implemented in both step and live recording modes. For each step, the sequencer has four substeps for touch position (pitches) and eight substeps for pressure - evenly divided over the step
  - Live recording captures your playing in the described resolution
  - Step recording records your touch for as many substeps as you hold it and leaves the rest of the step empty
  - Pitch-changes will be recorded into substeps in both live and step-record mode
  - In step-record mode, lifting your finger after holding a pad for longer than the step-length will remember the last(!) step-length of touches before you lifted your finger
- Sequencer gate-length no longer affects notes played by hand
## Midi
- Midi was quite unreliable and was rewritten to fully adhere to the midi standard. Responding to incoming midi notes and pressure now works as expected
- Midi notes now try to map to a string its pitch can be played on:
  - When a midi note comes in, the pitch of the midi note is compared to the pitches that the pads can play. The string whose center pitch is closest to the midi pitch becomes the preferred string
  - If the preferred string is not available, the closest available string is selected. Most of the time, at least the two adjacent strings can also play this midi pitch
  - see [voice allocation](#voice-allocation) for full details on voice allocation
- Midi notes light up the Plinky LEDs at the correct location
  - If the midi note can be played on its assigned string, the pad with the same pitch as the midi note lights up
  - If the midi note is an accidental of Plinky's scale, the pad of the closest lower scale pitch lights up
  - If the midi note is fully higher or lower than the pitches on its assigned string, the string's top or bottom pad respectively lights up
  
  # Earlier revisions

  These notes are taken from `config.h`

  | Version | Changes |
  |---------|---------|
  | 0.B2 | Pin detection for Plinky+ - boot the alternate display code for SSD1305 display driver |
  | 0.B1 | More RJ - lfo drawing is nicer; adc is not so smoothed? |
  | 0.B0 | MORE RJ MAGIC - https://github.com/plinkysynth/plinky_public/pull/40 - what a beast he is |
  | 0.A9 | Sequencer fixes, or more of a rewrite, from RJ-Eckie. absolutely incredible work. thankyou |
  | 0.A8 | Midi fixes from RJ-Eckie. Many thanks! |
  | 0.A7 | Bootloader work to make it work on MacOSX |
  | 0.A6 | Set Channels for MIDI in and out (unused pad) |
  | 0.A5 | Encoder fix |
  | 0.A4 | Disabled MERGE_PLAYBACK in touch.h. DISABLE_AUTOSAVE flag enables Demo Mode - changes are not written to flash. Disables ProgramPage() in params.h |
  | 0.A3 | Fixes a USB bug in which some hosts wouldn't recognize Plinky. New startup sequence is plinky_init(), then midiinit() |
  | 0.A2 | Allows for playing notes from the touch surface over a recorded sequence. Still buggy. In touch.h #define MERGE_PLAYBACK 1 |
  | 0.A1 | HW SERIAL MIDI SYNC & More CCs |
  | 0.A | USB MIDI Sync |
  | 0.9z | fix shimmer click? thanks hippo! |
  | 0.9y | fix wavetable off-by-2 - thanks Jan Matthis! |
  | 0.9x | added diminished scale |
  | 0.9w | finally fix the 'last slice gets trashed' bug, and add a saw shape :) |
  | 0.9v | flip the lights for root note, doh. SERIAL MIDI IN IS OFF |
  | 0.9u | fix note sample mode, make latch more reliable |
  | 0.9t | hilite root note |
  | 0.9s | make it so that the stupid notename doesnt overrun memory, doh |
  | 0.9r | make it so encoder click doesnt reset until release, so that long-press doesnt reset. also increase octave by 1 |
  | 0.9q | move the wavetable to the end of flash |
  | 0.9p | rescale cv in and expander cv out to 6v peak |
  | 0.9o | fix gain on expander outputs EXPANDER_GAIN |
  | 0.9n | change expander to output full mod src not just lfo |
  | 0.9m | stereo width, patch names & categories |
  | 0.9l | add accel test |
  | 0.9k | refine midi out a bit |
  | 0.9j | first version of midi out, also expander outputs lfo vals |
  | 0.9i | possible fix for midi24ppqncounter |
  | 0.9h | new wavetable header |
  | 0.9g | ?? |
  | 0.9f | midi refinements |
  | 0.9e | midi note allocation change |
  | 0.9d | bunch of small fixes! encoder click toggles arp & latch; pressure display on right of screen; note display; arp & latch show correct values, not 0.0; encoder clicks toggles between default and 0; long encoder click clears all modulation; negative strides no longer allowed; add accelerometer sensitivity parameter; LATCH IS NOW PER PRESET! not global; audio in now causes cute ripples in the LEDs from the bottom left corner; fixes for LEDs including mod A src not lighting; when choosing a parameter, all mod src's that are active light up; when choosing a mod src, all params affected by that mod src light up |
  | 0.9c | add accel sensitivity, increase ripples |
  | 0.9b | meska a/b overflow fix |
  | 0.9a | accelerometer proto special edition |
  | 0.92 | add a bit of diagnostics to calibration to try to detect shorts/ncs |
  | 0.91 | change drive to distort; add hysteresis to shift key; make touch less errory |
  | 0.9 | click encoder to zero value |
  | 0.8 | fix stereo pan when changing waveshape, and the broken wipe pattern |
  | 0.7 | flashed onto first units |

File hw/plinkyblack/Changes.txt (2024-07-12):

Change List V3.1 LPZW

- J12 & J13 are SMT now, had to unround the board corners for that
- all line audio & TRS MIDI jacks are PJ-313 THT now 
- R110 & R113 values changed 47R -> 1k, 15R -> 220R to remedy led switching noise
- USB-C jacks VBUS is now decoupled viad 1N5819WS schottky diodes 
- USB-C jacks data lines now go to a MUX IC PI3USB102EZLE, lower jack dominates that line
- USB TVS array ommited cos ESD protection build into that MUX
- serial resistors 100R and TVS arrays for clamping added to the expander port for protection 
- D4 is also 1N5819WS now
- removed pulldown & capacitor at U16B (did nothing anyway)
- added Potentiometer and Encoder tap contacts to GND
- removed all traces from In1.Cu layer (only GND there)
- increased the expader window even more
- changed "Thanks to" text
- general schematic cleanup

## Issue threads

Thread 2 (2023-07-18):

spec of the front LEDs?

KeLaiFu, 2023-07-18:
I'm working through getting the boards made and just noticed there's no spec for the LEDs on the front panel. I'm going to try and get PCBway to do the hard work soldering them, so the model number would be very useful!

also, just to confirm, the front panel to use is the one with LPZW in the file name?

Thanks

ijnekenamay, 2023-07-18:
Hi,KeLaiFU.
I don't know if this will help, but I stared at footprint and decided to buy generic 0603 blue and white chip LEDs from Aliexpress.
It probably won't be a problem, but I will let you know here if any discrepancies arise!
https://ja.aliexpress.com/item/1005003836509392.html

KeLaiFu, 2023-07-19:
I just found out these are the ones used in the original module:
https://www.digikey.co.uk/en/products/detail/inolux/IN-S124ARB/7604658

mmalex, 2023-07-19:
people have used all sorts of leds and it pretty much always works! the
leds are the same ones as in the expander which has a bom listing the
parts. its 1105 or 1106 size but you can get about anything to work, ive
seen purples reds oranges… rainbows…

sorry i need to add a bom to this repo too for the thruhole parts

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

Closed 2025-05-05.

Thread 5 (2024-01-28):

FW 09z - Plinky does not switch back to internal clock

makingsoundmachines, 2024-01-28:
When booting plinky with a patch that arpeggiates, it will run on internal clock.

If you patch a clock at 4PPQN (we should correct this in the manual where it says 2PPQN), the patch adapts to the new tempo.

Removing the clock, I think the original idea was that it should time out and switch back to internal clock, but it doesn't - so on subsequent touches to the face plate, Plinky remains silent.

[Test patch](https://plinkysynth.github.io/editor/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)

Loading patches without arp still works, but the arp patch only plays when it sees a new external clock tick until you power cycle plinky.

RJ-Eckie, 2025-02-10:
This was fixed by #27
@mmalex

Closed 2025-02-10.

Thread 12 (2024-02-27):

Mainboard and panels links

Digilogue, 2024-02-27:
I was on the last after the very first 200 you made.
Can you please update the links in the hw/bom readme page for the Mainboard,  Front, and Rear panels?
I've been trying to figure it out, but I couldn't sort it out with pcbway, and Iim not getting anywhere with jlpcb either.
If I could just click a couple times to buy...
Don't I want the v3?
Does that update the Mainboard?
Please help, it's been soo long and I'm already 53, lol.
Thank you.

StijnKuipers, 2024-02-27:
for all the latest status updates & progress (& help!) please join the Plinky discord. Things are a bit in flux at the moment - v3 is under active testing.

Join here -> https://discord.gg/ySHP2paN

Digilogue, 2024-02-27:
How about the front panel at pcbway. They don't have any knowledge of it. I buy from them, but I don't know the steps or even which file or files to upload. If the panel won't be changing, could you setup a page there where price is already known, and I can simply select how many and add to cart?

Sent with [Proton Mail](https://proton.me/) secure email.

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

miunau, 2024-02-28:
Hi @Digilogue, as said v3 is under testing so if you'll wait a little while longer, the kits should be available at Thonk and others. The contributors sadly don't have the time or resources to support individual requests like yours.

Digilogue, 2024-02-28:
I totally understand. But the readme clearly links to pcbway and jlpcb for those last three parts.
Just adding those links for the v2 files will benefit many people.
I personally have the other parts, so I don't want to buy a kit.
Thank you for understanding, and please reconsider.
Meanwhile, I will try to learn how to do it. Does jlpcb to pcbway have access to the processor now? Was it only possible this way when Alex arranged it? I'm confused because of the whole open source thing and the bom in the hw readme has led me here after all?

Sent with [Proton Mail](https://proton.me/) secure email.

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

Digilogue, 2024-03-03:
Now I'm understanding even more.
Can you please consider adding a mainboard- only option for v3 at thonk?
I could really appreciate a link for the front and back panels v2 from pcbway in one purchase, with specs already setup to avoid mistakes.

Sent with [Proton Mail](https://proton.me/) secure email.

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

Digilogue, 2024-03-04:
Me again, one more time.
I see it looks like changes with come to the front panel after all, reverse LEDs etc.
So no all I ask is when, but you might not know.
And will you please suggest to the devs that some folks are going to want just the two panels and Mainboard.
Thank you again, I'll get out of your hair now.

Sent with [Proton Mail](https://proton.me/) secure email.

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

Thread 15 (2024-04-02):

Plinky Expander USB does not power plinky +12/-12 rails

cctvfm, 2024-04-02:
Using the plinky expander without a eurorack case does not work properly. The expander is connected to +5V, however schottky D4 prevents this +5V rail from powering the TPS61040 which in turn generates the +12V and -12V.

This issue only affects the use of the Expander *without* being in a eurorack system, but lots of folks are using the Plinky + Expander in a 3d printed case.

I understand D4 is to prevent USB power from colliding with euro power. Perhaps a jumper to select between VBUS and +5V for the expander power? Or perhaps provide both VBUS and +5V to the expander port (remove one of the GND or 3v3 pins) and have the expander select which one is used.

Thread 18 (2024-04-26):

MIDI in tape-sample mode should not rotate voices

yrn1, 2024-04-26:
With a preset that plays a sample in ‘tape’ mode, MIDI triggers the sample at a different place with each played note. It seems it is rotating through its voices, which does not make sense for ‘tape’ mode, where the same ‘note’ on the different voices is a different place in the sample.

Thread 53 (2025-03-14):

Bottom octave range is too low

RJ-Eckie, 2025-03-14:
When setting the octave offset to the lowest setting (-4) the bottom-left pad is one octave lower than the lowest playable pad. This should be restrained to -3, but that is currently not possible without also changing the upper limit to +3

Closed 2025-03-15.

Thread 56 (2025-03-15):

Midi velocity / midi pressure ratio need a dedicated parameter

RJ-Eckie, 2025-03-15:
Currently, pressure is calculated from midi notes as follows:
- the note velocity (0-127) scales the initial pressure from 0 - 50%
- the highest of the pressure values (mono- or polyphonic, 0-127) adds another 0 - 50% on top of that

This solution is great for synths for synths with capacitive keyboards as they send a pressure value immediately when a note is triggered. Therefor they respond quite similar to the plinky itself

This solution is good for keyboards with aftertouch, as they have a significant of range to control with aftertouch

This solution is bad for sequencers and keyboards without aftertouch, as they can never trigger any note with a pressure value over 50%

### Proposed solution
The weight ratio of velocity and pressure can be set with a single parameter:
- at 100%, note velocity defines 100% of plinky pressure, pressure does nothing
- at 0%, note velocity does nothing, pressure defines 100% of plinky pressure
- at 50%, note velocity and pressure both define 50% of plinky pressure (current behavior)
(same for all values inbetween)

The calculation is always: `(x% * note velocity / 127) + ((100% - x%) * pressure / 127)`
With this parameter defaulted to 50%, the behavior for all patches is identical. And the pressure-sensitivity can be set to user preference

**Needs a global parameter menu**

makingsoundmachines, 2025-05-05:
Why not keep this simple: Velocity and Pressure do the same thing, so Velocity 1-127 maps the full range of pressure. You can determine which one to use with a comparison which of the two is larger.

The argument for this is mainly to avoid this behaviour:
- at 100%, note velocity defines 100% of plinky pressure, pressure does nothing

I think in almost all instances, Plinky should make a sound when you touch the surface.

RJ-Eckie, 2025-05-05:
> I think in almost all instances, Plinky should make a sound when you touch the surface

This is talking exclusively about midi pressure, not physical touch pressure. This parameter would not alter the physical touch behavior at all

> Also, you avoid introducing another parameter

We have to weigh the up/downsides of adding a parameter versus globally changing how midi responds for everyone, including on existing patches. For people who have their current patches set up to work well with their midi controller, changing the global midi velocity and pressure calculation would alter all their patches. That feels like a dealbreaker to me. Creating a new parameter that by default mirrors the current behavior avoids this.

I generally agree that less complexity is better, but there are lots of types of midi controllers out there that fundamentally work differently. I feel adding one parameter to have all kinds of midi controllers respond well is worth it

makingsoundmachines, 2025-05-06:
Oh sorry I misunderstood this was only about MIDI pressure.

In this case, let me try one more suggestion:

Velocity 1-127 sets the voices internal pressure param to the velocity value.

If MIDI pressure is received, this is updated with every MIDI pressure message received for that voice.
If no MIDI pressure is received, the velocity level stays set. The voices' pressure remains constant for the duration of the note.

RJ-Eckie, 2025-05-10:
If I'm understanding correctly what you're saying, that describes both the current situation and my proposed solution!

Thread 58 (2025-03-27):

Device hangs after canceling erasing new sample

RJ-Eckie, 2025-03-27:
Workflow:
- in the load screen, long-press an empty sample slot to edit it (device prompts to hold record to record a new sample)
- long-press record, the device starts erasing the sample
- press any of the following buttons during erasing: preset, prev, next, clear
- device shows sample edit ui with empty sample and hangs

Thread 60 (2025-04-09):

Pressure bar is not drawn correctly in v0.B0

RJ-Eckie, 2025-04-09:
From v0.B0, the pressure bar in the far right of the oled is not aligned correctly. Pressure 0 is raised from the bottom, just above the center value of the lowest LFO. It also displays negative pressures sometimes, drawing the bar from the zero-point downwards

The zero point should be at the bottom of the display, so it can only draw upwards

RJ-Eckie, 2025-04-20:
@makingsoundmachines found that this starts at v0.A9. A9 implements a bunch of pressure handling code that removes the existence of negative pressures. I'm suspecting this may be related

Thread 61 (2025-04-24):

Inconsistent sampler behavior

RJ-Eckie, 2025-04-24:
When in the sampler editor with a sample loaded:
- after long-pressing either **record** or **play** will start erasing the buffer to record a new sample
- while holding **record** the display will largely show "record?" and a filling bar (that's fine)
- while holding **play**, the display does not show the filling bar, which makes the following "erasing" screen a bit of a shock (inconsistent and unintuitive)
- after exiting out of the "erasing" prodedure by pressing **clear**, Plinky moves to the "monitor level" screen and hangs - can only be reset with a reboot

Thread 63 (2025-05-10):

CV Gate sends pressure - not gate

RJ-Eckie, 2025-05-10:
Here is roughly how the current cv gate output is calculated:
1. Take "volume" as a fraction of the pressure of a touch
https://github.com/plinkysynth/plinky_public/blob/a90cf756a18766a20c12d4ee3637dca90d935930/sw/Core/Src/plinky.c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
2. Save the highest of the current touch pressures
https://github.com/plinkysynth/plinky_public/blob/a90cf756a18766a20c12d4ee3637dca90d935930/sw/Core/Src/plinky.c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
3. Send that as CV Gate voltage
https://github.com/plinkysynth/plinky_public/blob/a90cf756a18766a20c12d4ee3637dca90d935930/sw/Core/Src/plinky.c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

Issues:
- By convention, a CV Gate is a high/low voltage, not a scaled value
- Having a scaled value can have merit in certain situations, but the plinky already has a dedicated CV output with *also* outputs the maximum pressure: the CV Pressure out

It seems more logical and useful to have CV Gate output a binary 5V/0V signal

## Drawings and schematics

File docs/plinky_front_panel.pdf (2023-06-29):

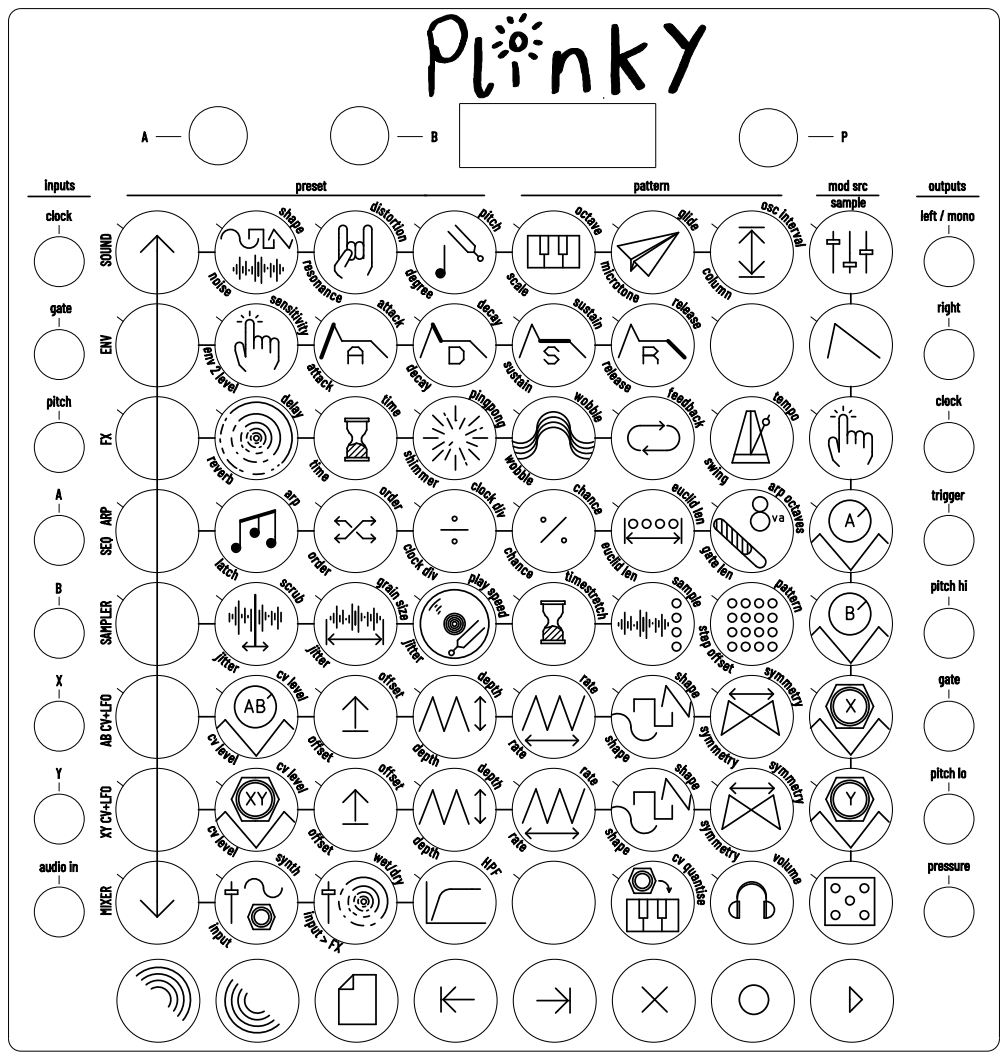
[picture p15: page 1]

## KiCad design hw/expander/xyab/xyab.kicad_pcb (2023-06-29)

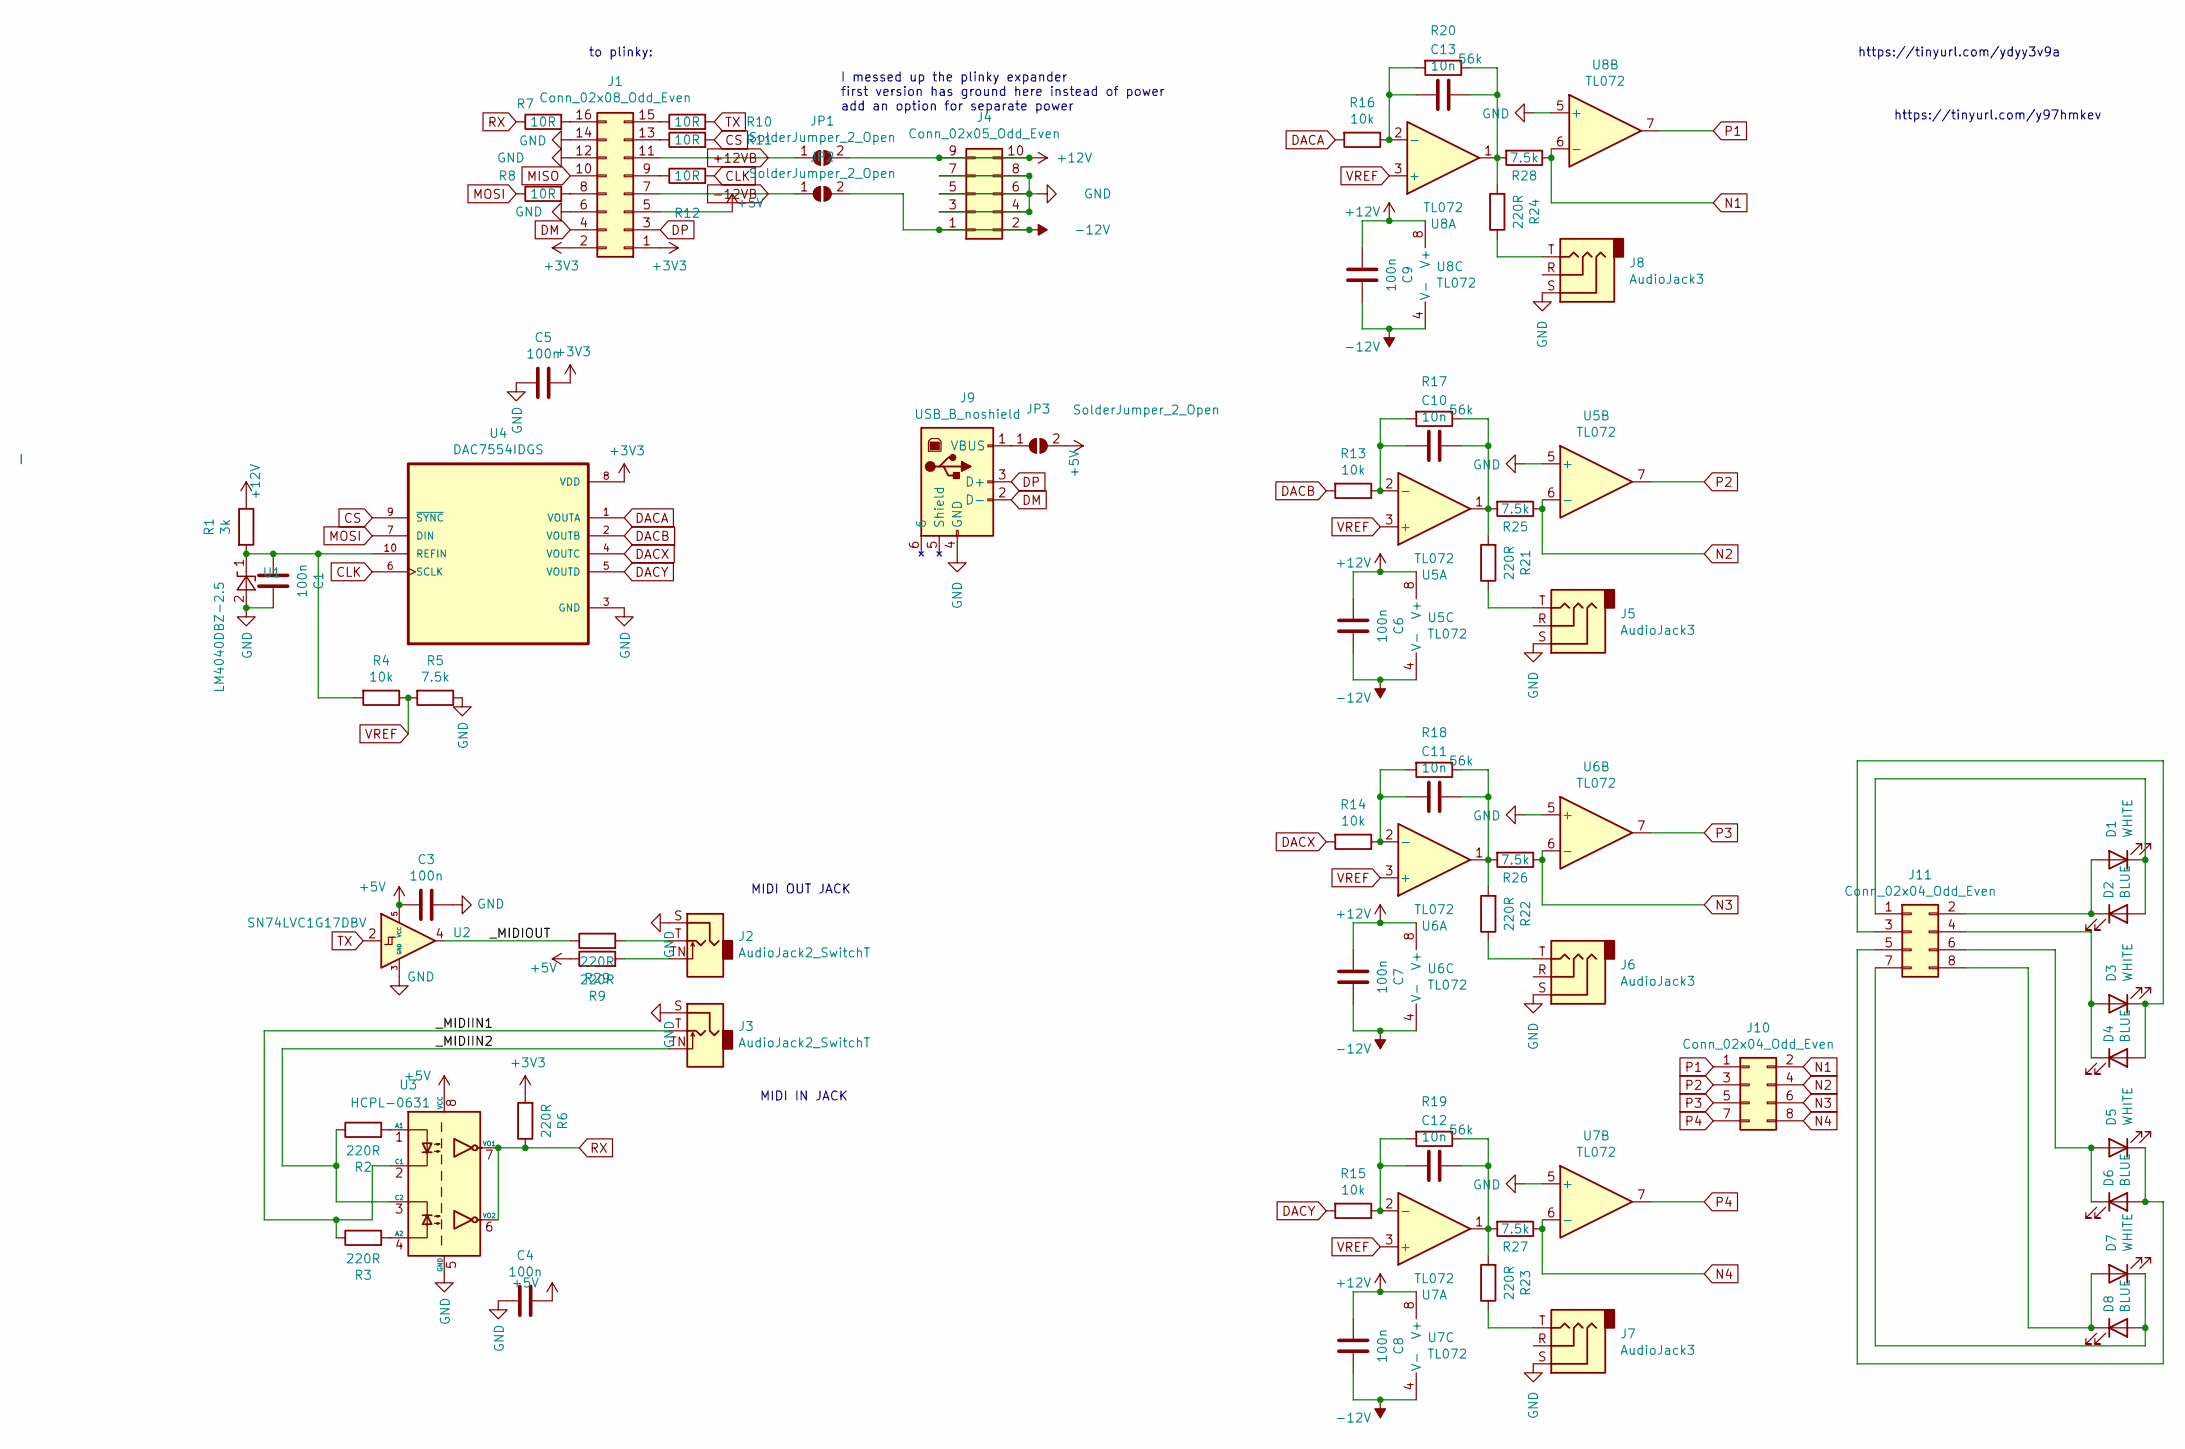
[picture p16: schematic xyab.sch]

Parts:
C1, C3, C4, C5, C6, C7, C8, C9: 100n; C_0603_1608Metric
C10, C11, C12, C13: 10n; C_0603_1608Metric
D1, D3, D5, D7: WHITE; led_reverse_2
D2, D4, D6, D8: BLUE; led_reverse_2
J1: Conn_02x08_Odd_Even; PinHeader_2x08_P2.54mm_Vertical
J2, J3: AudioJack2_SwitchT; Jack_3.5mm_QingPu_WQP-PJ398SM_Vertical_CircularHoles
J4: Conn_02x05_Odd_Even; PinHeader_2x05_P2.54mm_Vertical
J5, J6, J7, J8: AudioJack3; Jack_3.5mm_QingPu_WQP-PJ398SM_Vertical_CircularHoles
J9: USB_B_noshield; USB_B_TE_5787834_Vertical_two_shield
J10: Conn_02x04_Odd_Even; PinHeader_2x04_P2.54mm_Vertical
J11: Conn_02x04_Odd_Even; PinSocket_2x04_P2.54mm_Vertical_SMD
JP1, JP2, JP3: SolderJumper_2_Open; SolderJumper-2_P1.3mm_Open_Pad1.0x1.5mm
R1: 3k; R_0603_1608Metric
R2, R3, R6, R9, R21, R22, R23, R24, R29: 220R; R_0603_1608Metric
R4, R13, R14, R15, R16: 10k; R_0603_1608Metric
R5, R25, R26, R27, R28: 7.5k; R_0603_1608Metric
R7, R8, R10, R11, R12: 10R; R_0603_1608Metric
R17, R18, R19, R20: 56k; R_0603_1608Metric
U1: LM4040DBZ-2.5; SOT-23
U2: SN74LVC1G17DBV; SOT-353_SC-70-5
U3: HCPL-0631; SOIC-8_3.9x4.9mm_P1.27mm
U4: DAC7554IDGS; MSOP-10_3x3mm_P0.5mm
U5, U6, U7, U8: TL072; SOIC-8_3.9x4.9mm_P1.27mm

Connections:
+3V3: C5.1, J1.1, J1.2, R6.2, U4.8 (VDD)
+5V: C3.1, C4.1, J1.5, JP3.2 (B), R9.1, U2.5 (VCC), U3.8 (VCC)
+12V: C6.1, C7.1, C8.1, C9.1, J4.9, J4.10, JP1.2 (B), R1.1, U5.8 (V+), U6.8 (V+), U7.8 (V+), U8.8 (V+)
+12VB: J1.11, JP1.1 (A)
-12V: C6.2, C7.2, C8.2, C9.2, J4.1, J4.2, JP2.2 (B), U5.4 (V-), U6.4 (V-), U7.4 (V-), U8.4 (V-)
-12VB: J1.7, JP2.1 (A)
/_MIDIIN1: J3.T, R3.1, U3.2 (C1)
/_MIDIIN2: J3.TN, R2.1, U3.3 (C2)
/_MIDIOUT: R29.1, U2.4
CLK: R12.2, U4.6 (SCLK)
CS: R11.2, U4.9 (~SYNC)
DACA: R16.2, U4.1 (VOUTA)
DACB: R13.2, U4.2 (VOUTB)
DACX: R14.2, U4.4 (VOUTC)
DACY: R15.2, U4.5 (VOUTD)
DM: J1.4, J9.2 (D-)
DP: J1.3, J9.3 (D+)
GND: C1.1, C3.2, C4.2, C5.2, J1.6, J1.12, J1.14, J2.S, J3.S, J4.3, J4.4, J4.5, J4.6, J4.7, J4.8, J5.S, J6.S, J7.S, J8.S, J9.4 (GND), R5.1, U1.2 (A), U2.3 (GND), U3.5 (GND), U4.3 (GND), U5.5 (+), U6.5 (+), U7.5 (+), U8.5 (+)
MISO: J1.10
MOSI: R8.1, U4.7 (DIN)
N1: J10.2, R28.1, U8.6 (-)
N2: J10.4, R25.1, U5.6 (-)
N3: J10.6, R26.1, U6.6 (-)
N4: J10.8, R27.1, U7.6 (-)
unnamed: C1.2, R1.2, R4.2, U1.1 (K), U4.10 (REFIN)
unnamed: C10.1, R17.1, R21.2, R25.2, U5.1
unnamed: C10.2, R13.1, R17.2, U5.2 (-)
unnamed: C11.1, R18.1, R22.2, R26.2, U6.1
unnamed: C11.2, R14.1, R18.2, U6.2 (-)
unnamed: C12.1, R19.1, R23.2, R27.2, U7.1
unnamed: C12.2, R15.1, R19.2, U7.2 (-)
unnamed: C13.1, R20.1, R24.2, R28.2, U8.1
unnamed: C13.2, R16.1, R20.2, U8.2 (-)
unnamed: D1.1 (K), D2.2 (A), J11.1
unnamed: D1.2 (A), D2.1 (K), J11.2
unnamed: D3.1 (K), D4.2 (A), J11.3
unnamed: D3.2 (A), D4.1 (K), J11.4
unnamed: D5.1 (K), D6.2 (A), J11.5
unnamed: D5.2 (A), D6.1 (K), J11.6
unnamed: D7.1 (K), D8.2 (A), J11.7
unnamed: D7.2 (A), D8.1 (K), J11.8
unnamed: J1.8, R8.2
unnamed: J1.9, R12.1
unnamed: J1.13, R11.1
unnamed: J1.15, R10.1
unnamed: J1.16, R7.2
unnamed: J2.T, R29.2
unnamed: J2.TN, R9.2
unnamed: J5.T, R21.1
unnamed: J6.T, R22.1
unnamed: J7.T, R23.1
unnamed: J8.T, R24.1
unnamed: J9.1 (VBUS), JP3.1 (A)
unnamed: R2.2, U3.1 (A1)
unnamed: R3.2, U3.4 (A2)
P1: J10.1, U8.7
P2: J10.3, U5.7
P3: J10.5, U6.7
P4: J10.7, U7.7
RX: R6.1, R7.1, U3.6 (VO2), U3.7 (VO1)
TX: R10.2, U2.2
VREF: R4.1, R5.2, U5.3 (+), U6.3 (+), U7.3 (+), U8.3 (+)

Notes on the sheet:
MIDI OUT JACK
MIDI IN JACK
to plinky:
https://tinyurl.com/y97hmkev
I messed up the plinky expander first version has ground here instead of power add an option for separate power
https://tinyurl.com/ydyy3v9a

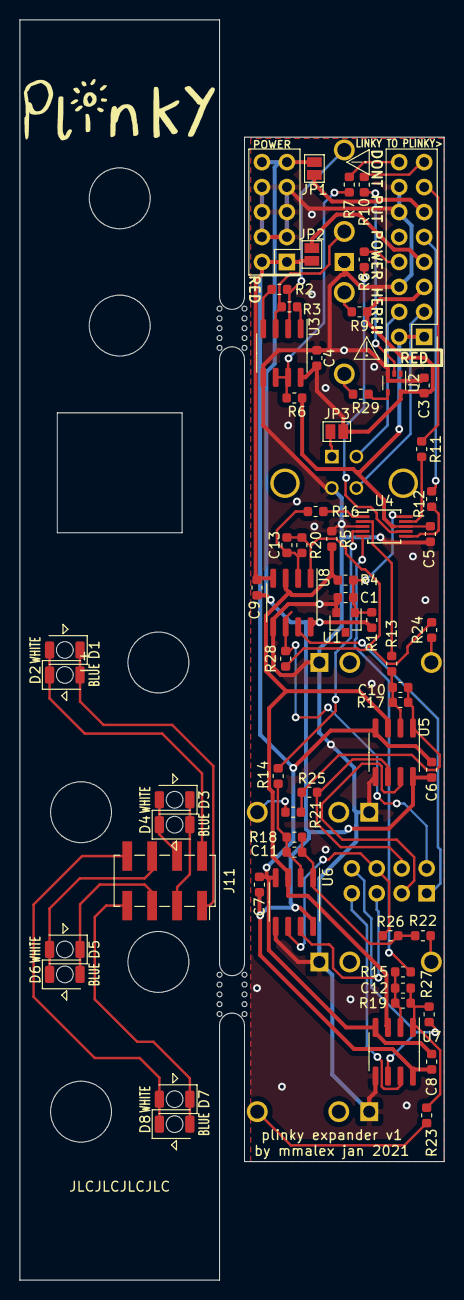
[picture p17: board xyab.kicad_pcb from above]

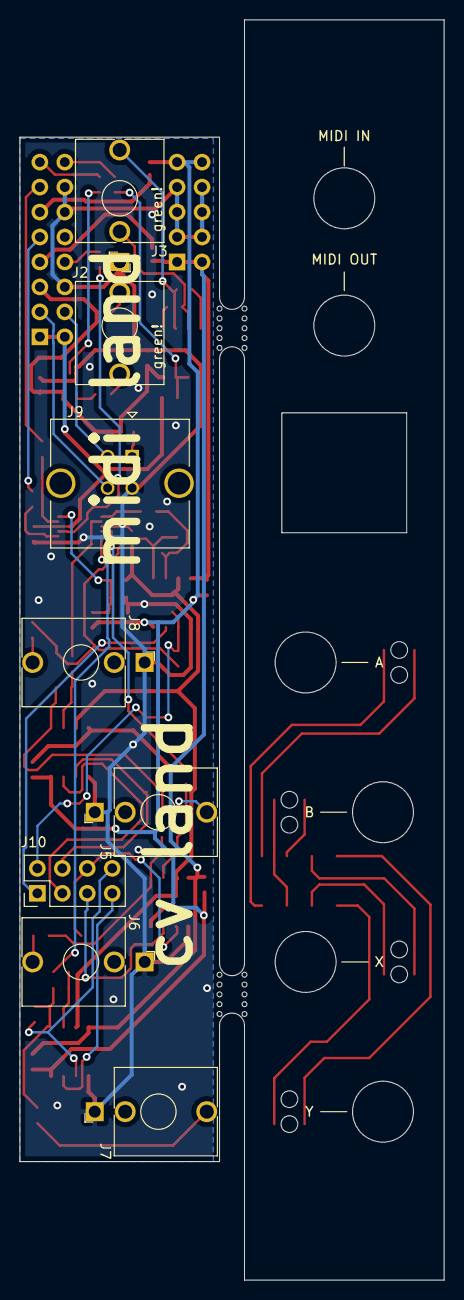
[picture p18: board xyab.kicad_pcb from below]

Board: 2 copper layers, 43.2 x 128.3 mm, 71 parts (8 on the bottom side), 61 nets.

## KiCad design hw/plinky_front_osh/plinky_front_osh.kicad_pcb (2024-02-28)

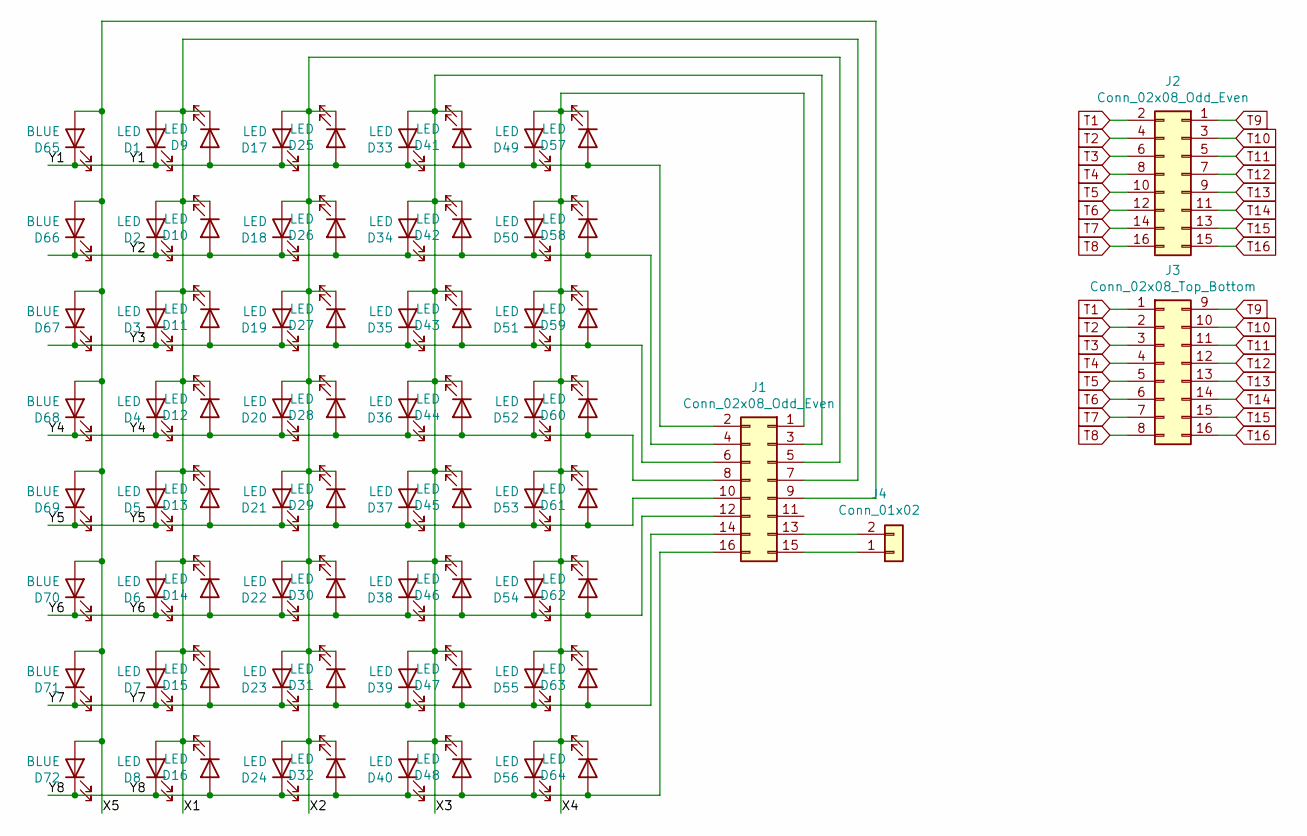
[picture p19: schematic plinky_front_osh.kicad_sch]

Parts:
D1, D2, D3, D4, D5, D6, D7, D8, D9, D10, D11, D12, D13, D14, D15, D16, D17, D18, D19, D20, D21, D22, D23, D24, D25, D26, D27, D28, D29, D30, D31, D32, D33, D34, D35, D36, D37, D38, D39, D40, D41, D42, D43, D44, D45, D46, D47, D48, D49, D50, D51, D52, D53, D54, D55, D56, D57, D58, D59, D60, D61, D62, D63, D64: LED; led_reverse_2mm_hole; LCSC C5201648
D65, D66, D67, D68, D69, D70, D71, D72: BLUE; led_reverse_2mm_hole; LCSC C131225
J1, J2: Conn_02x08_Odd_Even; PinHeader_2x08_P2.54mm_Vertical_SMD
J3: Conn_02x08_Top_Bottom; touchy7
J4: Conn_01x02; touchy7horiz

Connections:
/X1: D1.2 (A), D2.2 (A), D3.2 (A), D4.2 (A), D5.2 (A), D6.2 (A), D7.2 (A), D8.2 (A), D9.1 (K), D10.1 (K), D11.1 (K), D12.1 (K), D13.1 (K), D14.1 (K), D15.1 (K), D16.1 (K), J1.7
/X2: D17.2 (A), D18.2 (A), D19.2 (A), D20.2 (A), D21.2 (A), D22.2 (A), D23.2 (A), D24.2 (A), D25.1 (K), D26.1 (K), D27.1 (K), D28.1 (K), D29.1 (K), D30.1 (K), D31.1 (K), D32.1 (K), J1.5
/X3: D33.2 (A), D34.2 (A), D35.2 (A), D36.2 (A), D37.2 (A), D38.2 (A), D39.2 (A), D40.2 (A), D41.1 (K), D42.1 (K), D43.1 (K), D44.1 (K), D45.1 (K), D46.1 (K), D47.1 (K), D48.1 (K), J1.3
/X4: D49.2 (A), D50.2 (A), D51.2 (A), D52.2 (A), D53.2 (A), D54.2 (A), D55.2 (A), D56.2 (A), D57.1 (K), D58.1 (K), D59.1 (K), D60.1 (K), D61.1 (K), D62.1 (K), D63.1 (K), D64.1 (K), J1.1
/X5: D65.2 (A), D66.2 (A), D67.2 (A), D68.2 (A), D69.2 (A), D70.2 (A), D71.2 (A), D72.2 (A), J1.9
/Y1: D1.1 (K), D9.2 (A), D17.1 (K), D25.2 (A), D33.1 (K), D41.2 (A), D49.1 (K), D57.2 (A), D65.1 (K), J1.2
/Y2: D2.1 (K), D10.2 (A), D18.1 (K), D26.2 (A), D34.1 (K), D42.2 (A), D50.1 (K), D58.2 (A), D66.1 (K), J1.4
/Y3: D3.1 (K), D11.2 (A), D19.1 (K), D27.2 (A), D35.1 (K), D43.2 (A), D51.1 (K), D59.2 (A), D67.1 (K), J1.6
/Y4: D4.1 (K), D12.2 (A), D20.1 (K), D28.2 (A), D36.1 (K), D44.2 (A), D52.1 (K), D60.2 (A), D68.1 (K), J1.8
/Y5: D5.1 (K), D13.2 (A), D21.1 (K), D29.2 (A), D37.1 (K), D45.2 (A), D53.1 (K), D61.2 (A), D69.1 (K), J1.10
/Y6: D6.1 (K), D14.2 (A), D22.1 (K), D30.2 (A), D38.1 (K), D46.2 (A), D54.1 (K), D62.2 (A), D70.1 (K), J1.12
/Y7: D7.1 (K), D15.2 (A), D23.1 (K), D31.2 (A), D39.1 (K), D47.2 (A), D55.1 (K), D63.2 (A), D71.1 (K), J1.14
/Y8: D8.1 (K), D16.2 (A), D24.1 (K), D32.2 (A), D40.1 (K), D48.2 (A), D56.1 (K), D64.2 (A), D72.1 (K), J1.16
unnamed: J1.13, J4.2
unnamed: J1.15, J4.1
T1: J2.2, J3.1
T2: J2.4, J3.2
T3: J2.6, J3.3
T4: J2.8, J3.4
T5: J2.10, J3.5
T6: J2.12, J3.6
T7: J2.14, J3.7
T8: J2.16, J3.8
T9: J2.1, J3.9
T10: J2.3, J3.10
T11: J2.5, J3.11
T12: J2.7, J3.12
T13: J2.9, J3.13
T14: J2.11, J3.14
T15: J2.13, J3.15
T16: J2.15, J3.16

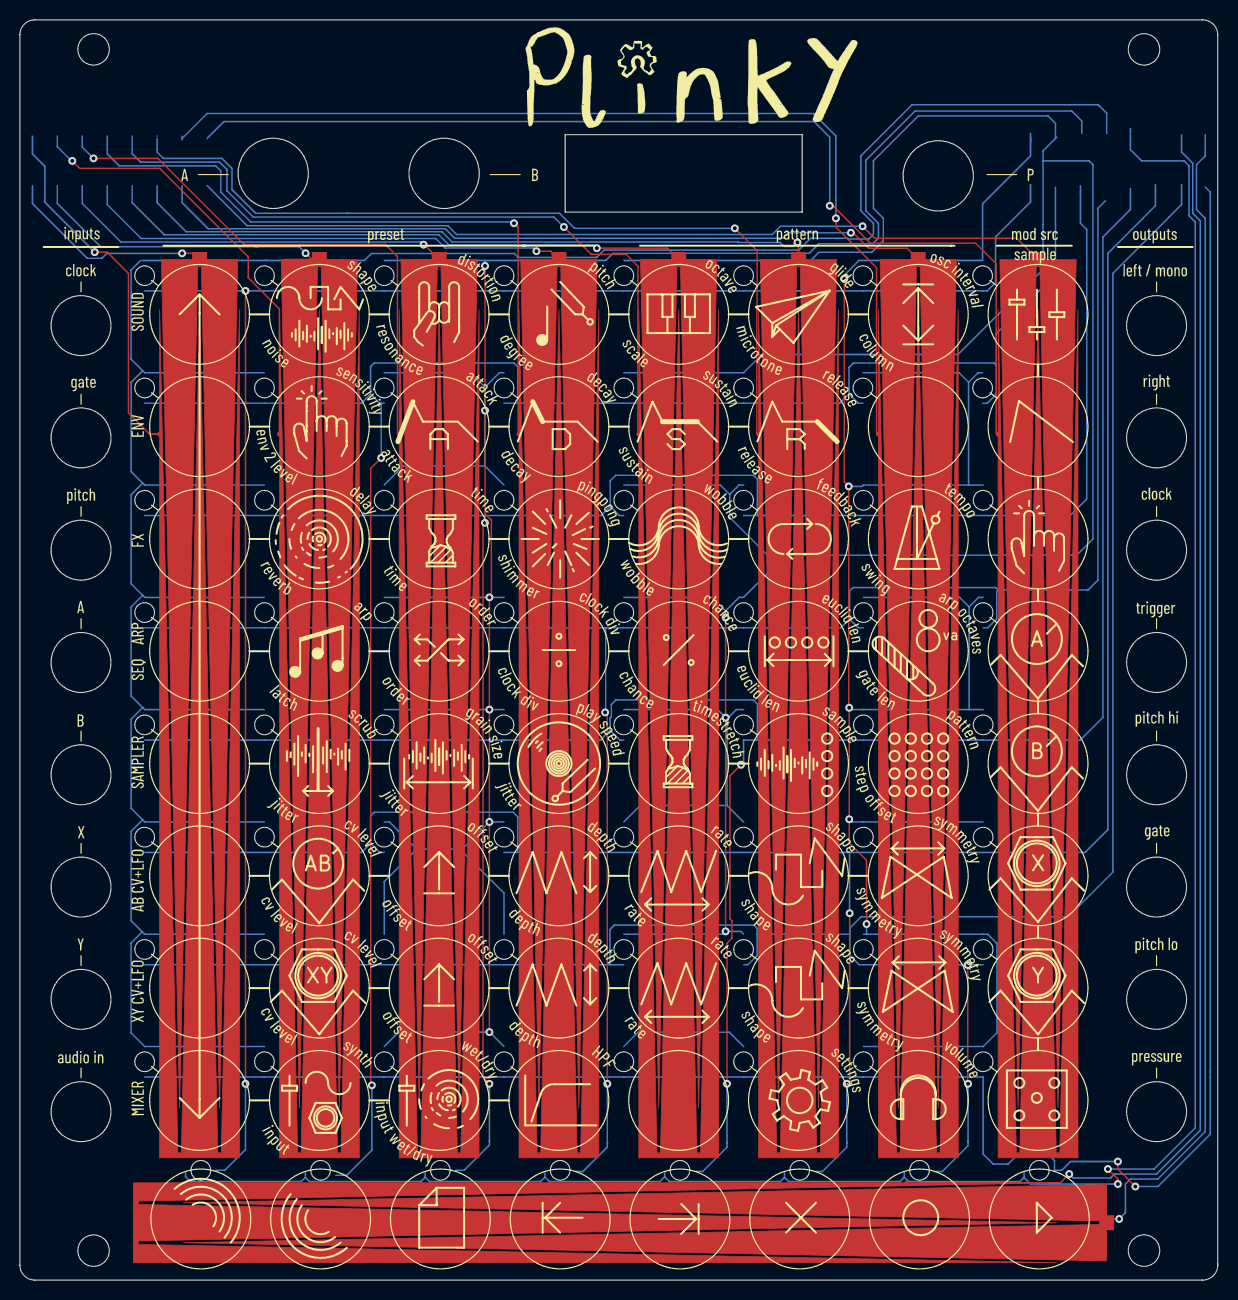
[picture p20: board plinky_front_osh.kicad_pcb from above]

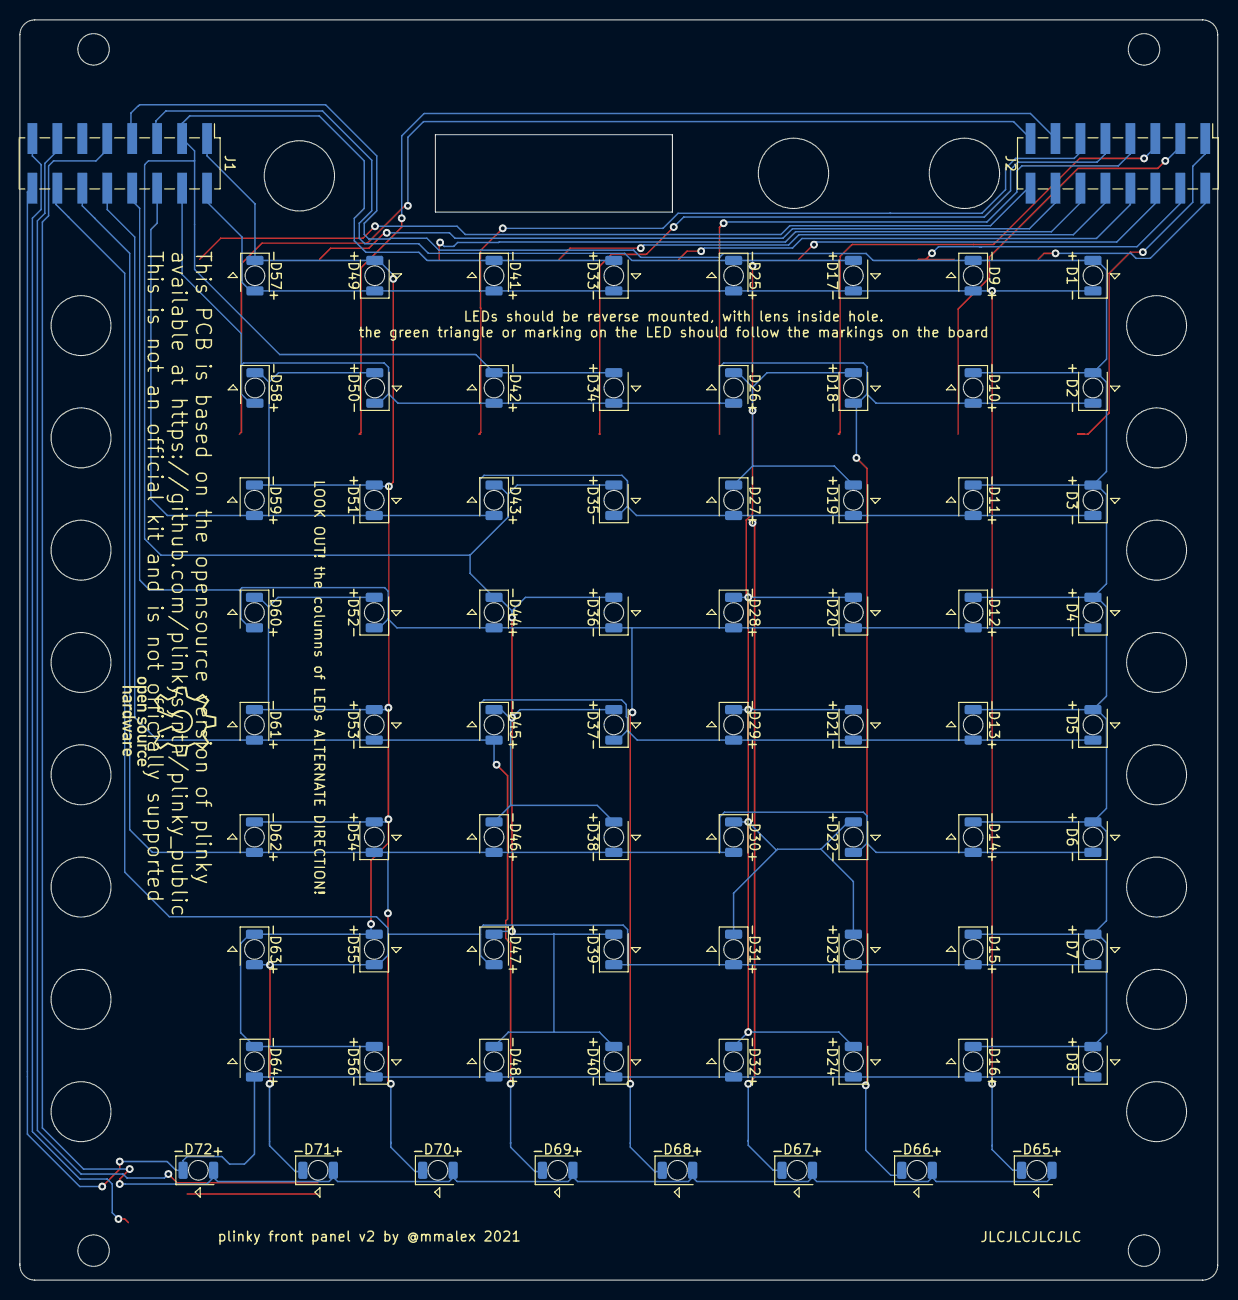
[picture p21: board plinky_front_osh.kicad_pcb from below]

Board: 2 copper layers, 121.9 x 128.3 mm, 81 parts (74 on the bottom side), 31 nets.

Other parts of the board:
LOGO: LOGO; plinky_osh_gear_rough
M1, M2, M3, M4: MountingHole_3.2mm_M3

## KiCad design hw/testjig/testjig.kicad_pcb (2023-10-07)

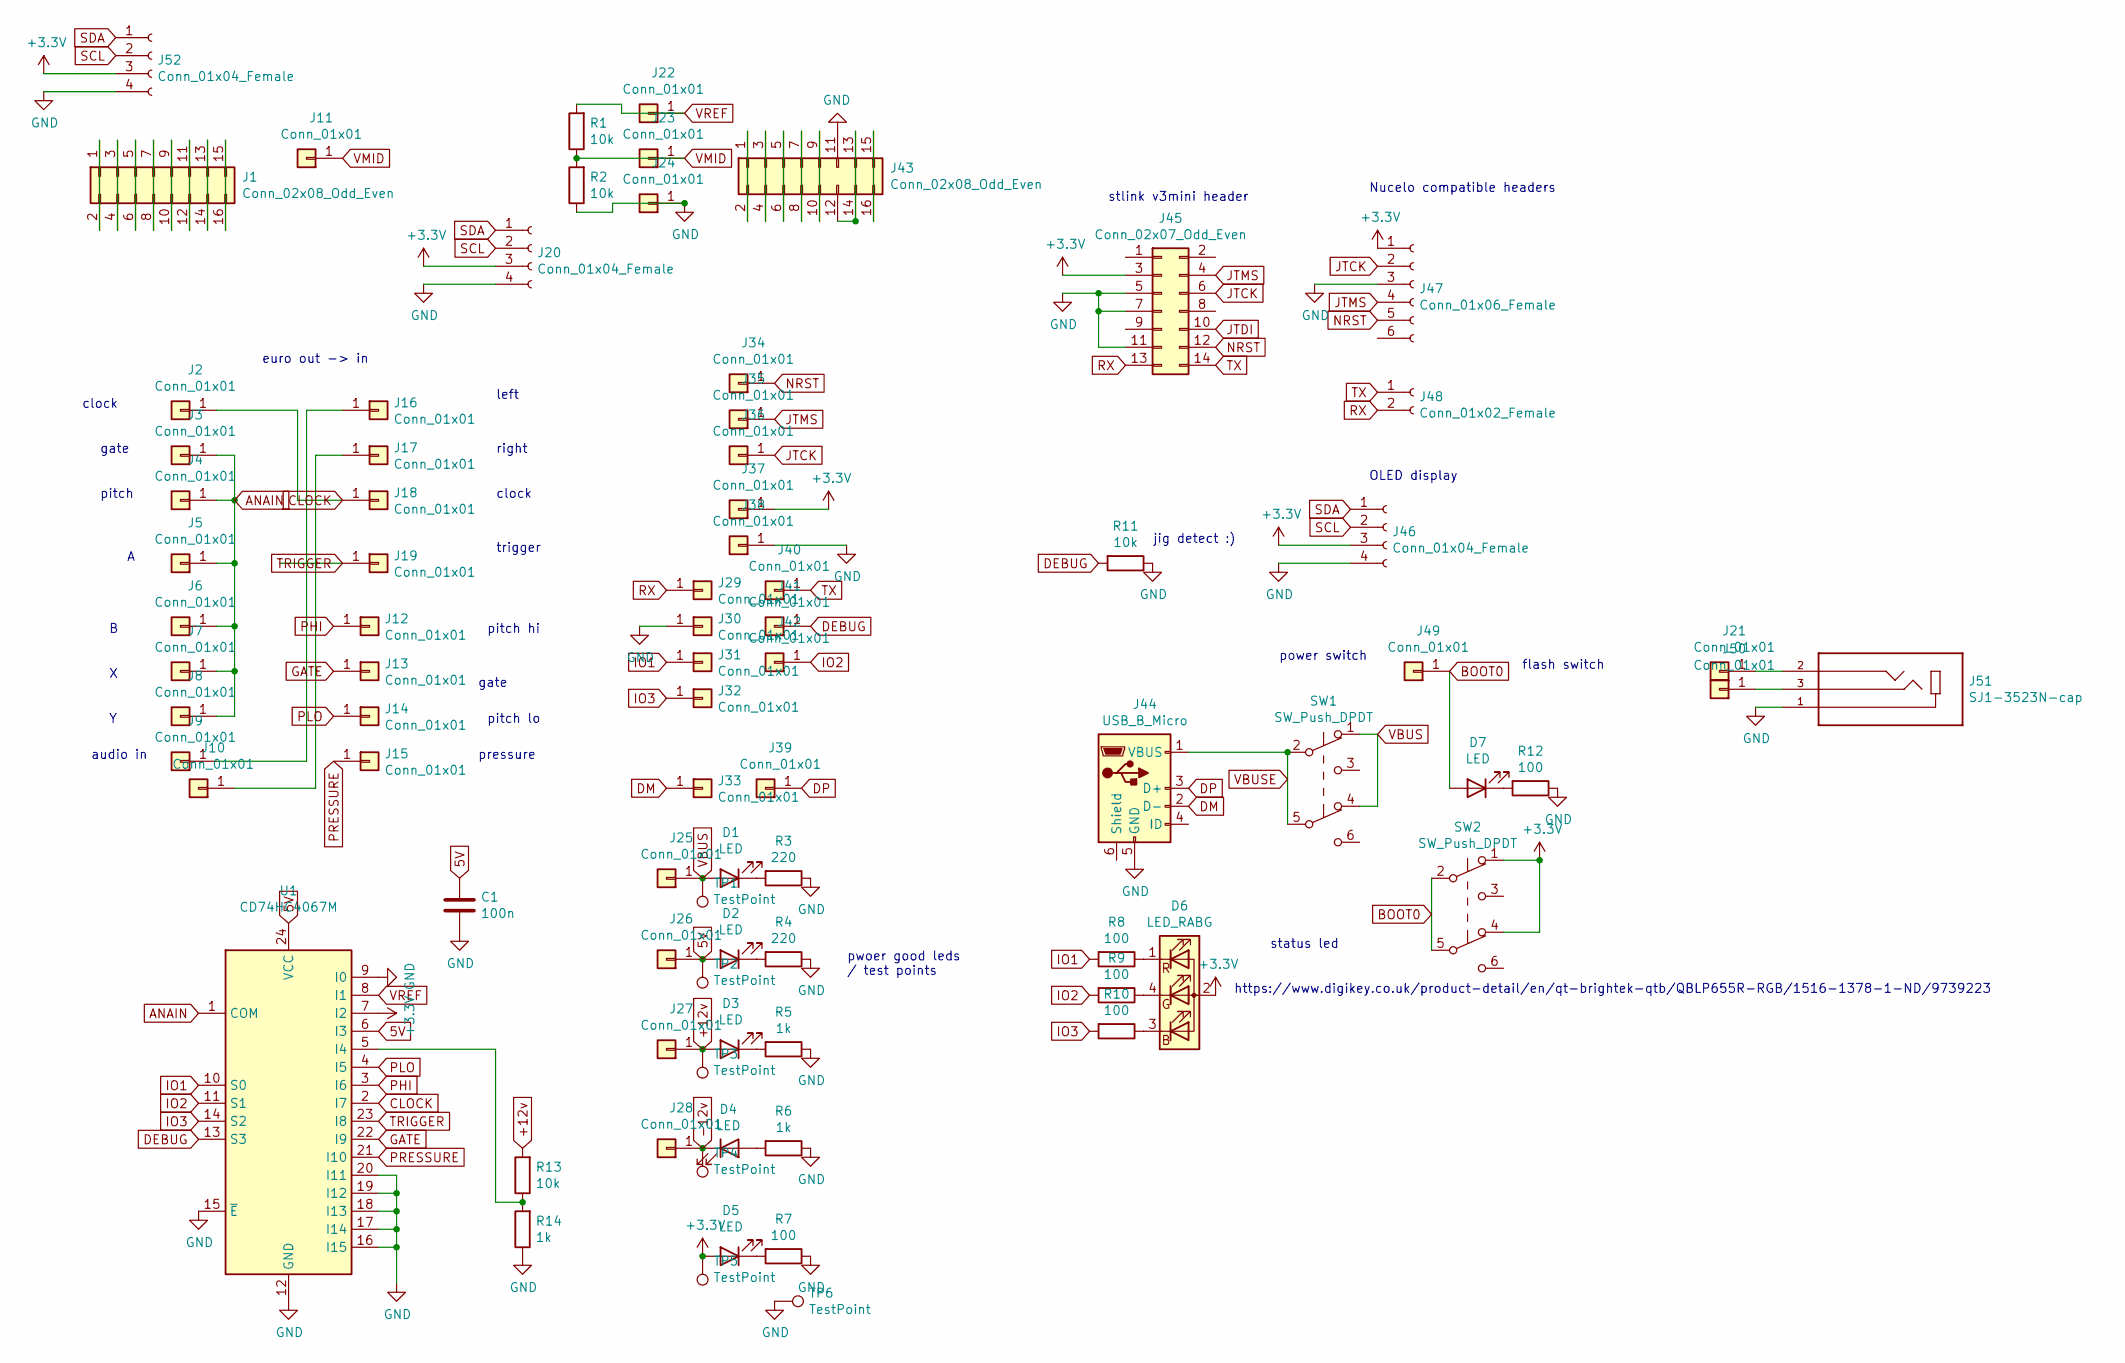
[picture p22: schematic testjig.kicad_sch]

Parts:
C1: 100n; C_0603_1608Metric_Pad1.05x0.95mm_HandSolder
D1, D2, D3, D4, D5, D7: LED; LED_0603_1608Metric
D6: LED_RABG; LED_RGB_1210_reverse
J1, J43: Conn_02x08_Odd_Even; PinSocket_2x08_P2.54mm_Vertical
J2, J3, J4, J5, J6, J7, J8, J9, J10, J11, J12, J13, J14, J15, J16, J17, J18, J19, J21, J22, J23, J24, J25, J26, J27, J28, J29, J30, J31, J32, J33, J34, J35, J36, J37, J38, J39, J40, J41, J42, J49, J50: Conn_01x01; PinHeader_1x01_P2.54mm_Vertical
J20, J46, J52: Conn_01x04_Female; PinSocket_1x04_P2.54mm_Vertical
J44: USB_B_Micro; USB_Micro-B_Molex-105017-0001
J45: Conn_02x07_Odd_Even; PinHeader_2x07_P1.27mm_Vertical_SMD
J47: Conn_01x06_Female; PinSocket_1x06_P2.54mm_Vertical
J48: Conn_01x02_Female; PinSocket_1x02_P2.54mm_Vertical
J51: SJ1-3523N-cap; CUI_SJ1-3523N
R1, R2, R11, R13: 10k; R_0603_1608Metric_Pad1.05x0.95mm_HandSolder
R3, R4: 220; R_0603_1608Metric_Pad1.05x0.95mm_HandSolder
R5, R6, R14: 1k; R_0603_1608Metric_Pad1.05x0.95mm_HandSolder
R7, R8, R9, R10, R12: 100; R_0603_1608Metric_Pad1.05x0.95mm_HandSolder
SW1, SW2: SW_Push_DPDT; dpdt 7mm
TP1, TP2, TP3, TP4, TP5, TP6: TestPoint; TestPoint_Pad_2.5x2.5mm
U1: CD74HC4067M; SOIC-24W_7.5x15.4mm_P1.27mm

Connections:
5V: C1.1, D2.2 (A), J26.1, TP2.1, U1.6 (I3), U1.24 (VCC)
+3V3: D5.2 (A), D6.2 (A), J20.3, J37.1, J45.3, J46.3, J47.1, J52.3, SW2.1 (A), SW2.4 (A), TP5.1, U1.7 (I2)
+12v: D3.2 (A), J27.1, R13.2, TP3.1
-12v: D4.1 (K), J28.1, TP4.1
ANAIN: J3.1, J4.1, J5.1, J6.1, J7.1, J8.1, U1.1 (COM)
BOOT0: D7.2 (A), J49.1, SW2.2 (B), SW2.5 (B)
CLOCK: J2.1, J18.1, U1.2 (I7)
DEBUG: J41.1, R11.2, U1.13 (S3)
DM: J33.1, J44.2 (D-)
DP: J39.1, J44.3 (D+)
GATE: J13.1, U1.22 (I9)
GND: C1.2, J20.4, J24.1, J30.1, J38.1, J43.11, J44.5 (GND), J45.5, J45.7, J45.11, J46.4, J47.3, J51.1, J52.4, R2.1, R3.1, R4.1, R5.1, R6.1, R7.1, R11.1, R12.1, R14.1, TP6.1, U1.9 (I0), U1.12 (GND), U1.15 (~E), U1.16 (I15), U1.17 (I14), U1.18 (I13), U1.19 (I12), U1.20 (I11)
IO1: J31.1, R8.2, U1.10 (S0)
IO2: J42.1, R9.2, U1.11 (S1)
IO3: J32.1, R10.2, U1.14 (S2)
JTCK: J36.1, J45.6, J47.2
JTDI: J45.10
JTMS: J35.1, J45.4, J47.4
NRST: J34.1, J45.12, J47.5
unnamed: D1.1 (K), R3.2
unnamed: D2.1 (K), R4.2
unnamed: D3.1 (K), R5.2
unnamed: D4.2 (A), R6.2
unnamed: D5.1 (K), R7.2
unnamed: D6.3 (BK), R10.1
unnamed: D6.4 (GK), R9.1
unnamed: D6.1 (RK), R8.1
unnamed: D7.1 (K), R12.2
unnamed: J1.1, J1.2
unnamed: J1.3, J1.4
unnamed: J1.5, J1.6
unnamed: J1.7, J1.8
unnamed: J1.9, J1.10
unnamed: J1.11, J1.12
unnamed: J1.13, J1.14
unnamed: J1.15, J1.16
unnamed: J10.1, J17.1
unnamed: J9.1, J16.1
unnamed: J21.1, J51.2
unnamed: J43.1, J43.2
unnamed: J43.3, J43.4
unnamed: J43.5, J43.6
unnamed: J43.7, J43.8
unnamed: J43.9, J43.10
unnamed: J43.12, J43.13, J43.14
unnamed: J43.15, J43.16
unnamed: J50.1, J51.3
unnamed: R13.1, R14.2, U1.5 (I4)
PHI: J12.1, U1.3 (I6)
PLO: J14.1, U1.4 (I5)
PRESSURE: J15.1, U1.21 (I10)
RX: J29.1, J45.13, J48.2
SCL: J20.2, J46.2, J52.2
SDA: J20.1, J46.1, J52.1
TRIGGER: J19.1, U1.23 (I8)
TX: J40.1, J45.14, J48.1
VBUS: D1.2 (A), J25.1, SW1.1 (A), SW1.4 (A), TP1.1
VBUSE: J44.1 (VBUS), SW1.2 (B), SW1.5 (B)
VMID: J11.1, J23.1, R1.1, R2.2
VREF: J22.1, R1.2, U1.8 (I1)

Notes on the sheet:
status led
clock
euro out -> in
pressure
left
gate
jig detect :)
right
https://www.digikey.co.uk/product-detail/en/qt-brightek-qtb/QBLP655R-RGB/1516-1378-1-ND/9739223
power switch
pitch lo
pitch hi
audio in
trigger
Nucelo compatible headers
OLED display
flash switch
stlink v3mini header
pitch
pwoer good leds / test points

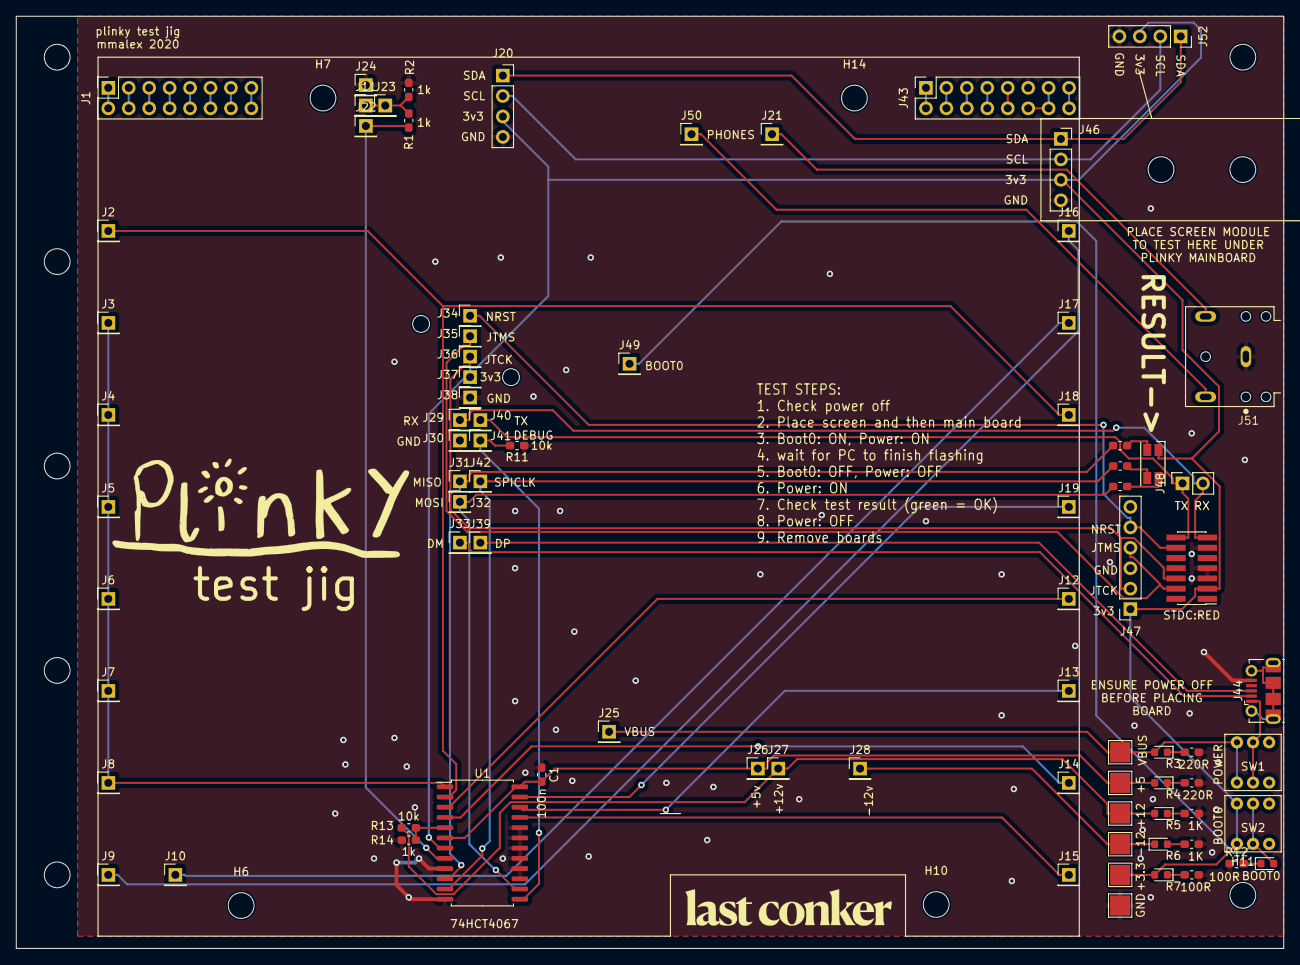
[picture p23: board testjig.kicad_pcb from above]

Board: 2 copper layers, 157.5 x 115.8 mm, 99 parts (0 on the bottom side), 59 nets.

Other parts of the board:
H1, H2, H3, H4, H5, H6, H7, H10, H11, H12, H12#2, H13, H14: MountingHole; MountingHole_3.2mm_M3
H8, H9: MountingHole_2.1mm
LOGO: LOGO; plinkylogo

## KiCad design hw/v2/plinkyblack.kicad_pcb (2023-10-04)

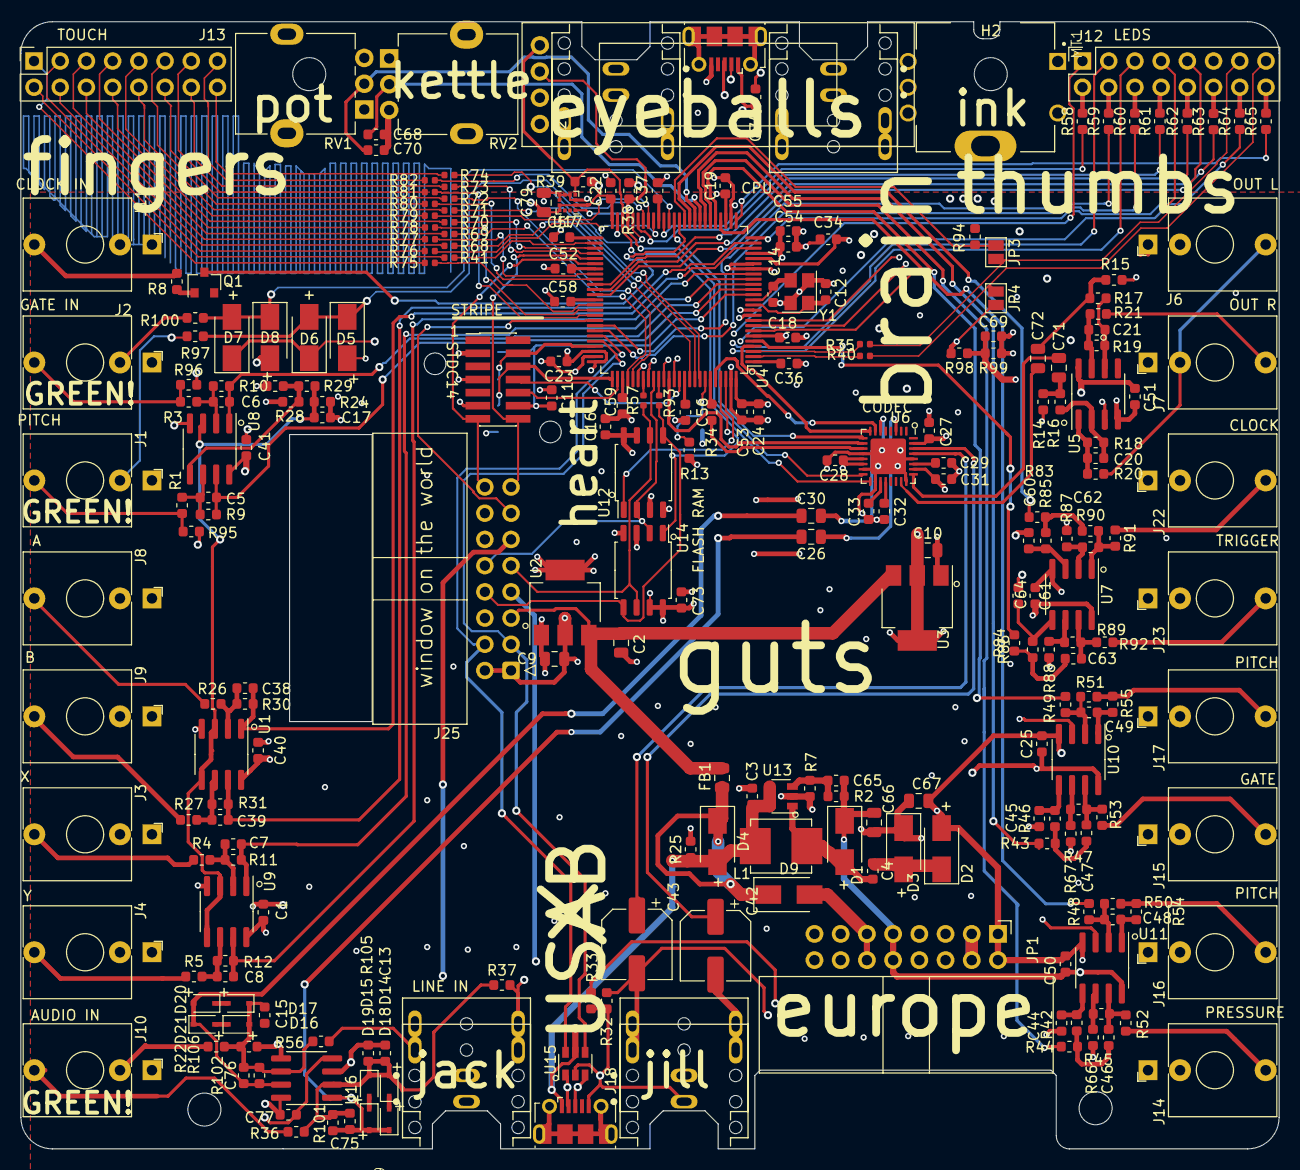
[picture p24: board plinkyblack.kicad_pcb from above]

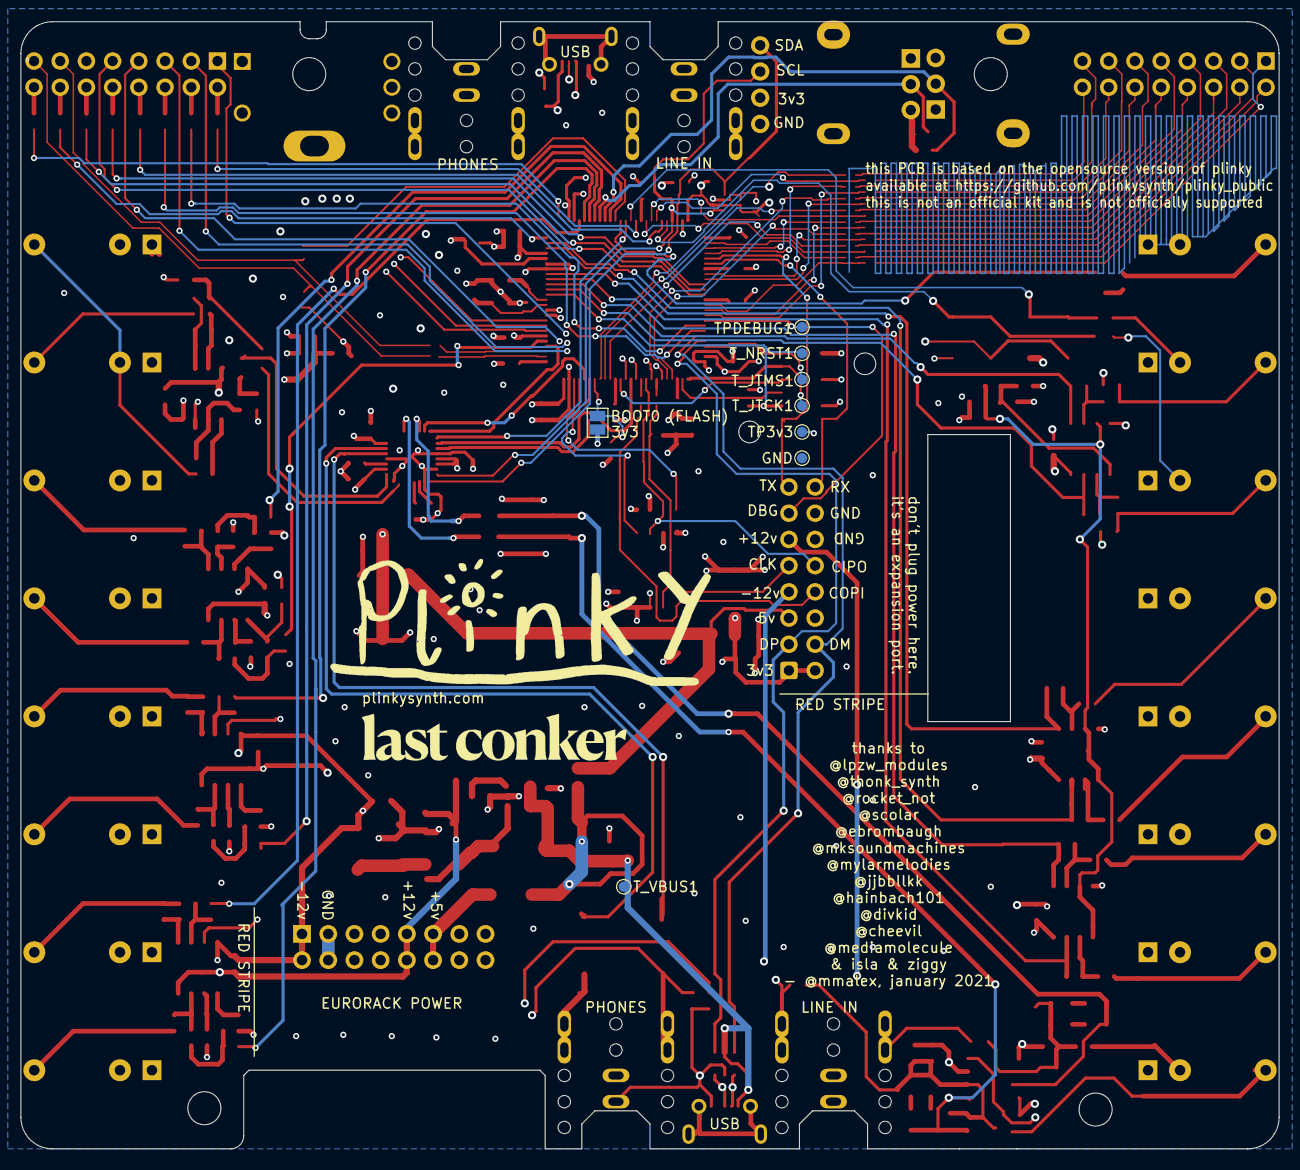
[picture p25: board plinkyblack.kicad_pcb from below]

Board: 4 copper layers, 121.9 x 109.2 mm, 266 parts (9 on the bottom side), 204 nets.

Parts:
C1, C11, C16, C17, C18, C19, C22, C23, C25, C28, C35, C36, C37, C40, C41, C50, C51, C52, C53, C56, C57, C58, C59, C64, C68, C69, C70, C73, C74, C77: 100n; C_0603_1608Metric
C2, C9, C10, C26, C30, C66, C67, C71, C72, C79: 10u; C_0805_2012Metric
C3, C24, C27, C29, C31, C32, C33: 4.7u; C_0603_1608Metric
C4, C34, C54: 1u; C_0603_1608Metric
C5, C6, C7, C8, C38, C39, C44, C45, C46, C47, C48, C49, C60, C61, C62, C63: 4.7n; C_0603_1608Metric
C12, C14, C65: 18p; C_0603_1608Metric
C13, C15, C20, C21, C75, C76: 220p; C_0603_1608Metric
C42, C43: 220u; CP_Elec_6.3x5.9
C55: 10n; C_0603_1608Metric
D1, D2, D3, D4, D5, D6, D7, D8, D9: D_Schottky; D_SMA
D14, D15, D16, D17, D18, D19, D20, D21: 1N4148WS; D_SOD-323
FB1: Ferrite_Bead_Small; L_0805_2012Metric
H1, H2, H3, H4: MountingHole; MountingHole_3.2mm_M3
J1, J2, J3, J4, J6, J7, J8, J9, J10, J11, J14, J15, J16, J17, J22, J23: AudioJack2_SwitchT; thonk_with_3d
J5: SWD header; PinHeader_2x07_P1.27mm_Vertical_SMD
J12, J13: Conn_02x08_Odd_Even; PinSocket_2x08_P2.54mm_Vertical
J18, J24: USB_B_Micro; USB_Micro-B_Molex-105017-0001_with_3d
J19, J21, J26, J27: SJ1-3523N; CUI_SJ1-3523N_double
J20: oled0.91; oled091
J25: Conn_01x16_Female; IDC-Header_2x08_P2.54mm_Horizontal
JP1: Euro power; IDC-Header_2x08_P2.54mm_Horizontal
JP2, JP3, JP4: SolderJumper_2_Open; SolderJumper-2_P1.3mm_Open_Pad1.0x1.5mm
L1: 10uH; L_Murata_LQH55DN_5.7x5.0mm
LOGO: LOGO; plinky
MT1: PEC11R-4215F-S0024; pec11r_encoder
Q1: MMBT3904; SOT-23
R1, R3, R4, R5, R8, R22, R26, R27, R32, R33, R36: 100k; R_0603_1608Metric
R2, R94, R95, R96: 1M5; R_0603_1608Metric
R7, R25: 200k; R_0603_1608Metric
R9, R14, R15, R18, R19, R50, R51: 33k; R_0603_1608Metric
R10, R11, R12, R30, R31, R42, R46, R85, R86: 22k; R_0603_1608Metric
R13, R28, R37, R43, R44, R45, R47, R48, R49, R56, R66, R67, R83, R84, R87, R88, R89, R90, R98, R99, R105, R106: 10k; R_0603_1608Metric
R16, R17: 5.6k; R_0603_1608Metric
R20, R21, R52, R53, R54, R55, R91, R92: 1k; R_0603_1608Metric
R24: 8.2k; R_0603_1608Metric
R29, R38, R39, R97, R100: 2k2; R_0603_1608Metric
R34: 100R; R_0603_1608Metric
R35, R40, R41, R57, R68, R69, R70, R71, R72, R73, R74, R75, R76, R77, R78, R79, R80, R81, R82, R93: 100R; R_0402_1005Metric
R58, R59, R60, R61, R62, R63, R64, R65: 47R; R_0603_1608Metric
R101, R102: 12k; R_0603_1608Metric
REFHOLE11, REFHOLE99: MountingHole_2.1mm
RV1, RV2: 100k; pot3d
TP3v3: TestPoint; TestPoint_Pad_D1.0mm
TPDEBUG1: TestPoint; TestPoint_Pad_D1.0mm
TPGND2: TestPoint; TestPoint_Pad_D1.0mm
T_JTCK1: TestPoint; TestPoint_Pad_D1.0mm
T_JTMS1: TestPoint; TestPoint_Pad_D1.0mm
T_NRST1: TestPoint; TestPoint_Pad_D1.0mm
T_VBUS1: TestPoint; TestPoint_Pad_D1.0mm
U1, U8, U9: MCP6002-xSN; SOIC-8_3.9x4.9mm_P1.27mm
U2, U3: LM1117-3.3; SOT-223-3_TabPin2
U4: STM32L476VGTx; LQFP-100_14x14mm_P0.5mm
U5, U7, U10, U11, U16: TL072; SOIC-8_3.9x4.9mm_P1.27mm
U6: WM8758B; QFN-32-1EP_5x5mm_P0.5mm_EP3.45x3.45mm
U12, U14: W25Q32JVSS; SOIC-8_5.23x5.23mm_P1.27mm
U13: TPS61040DBV; SOT-23-5
U15: USBLC6-2SC6; SOT-23-6
U17: LIS2DH12; LGA-12_2x2mm_P0.5mm
Y1: Crystal_GND24; Crystal_SMD_Abracon_ABM8G-4Pin_3.2x2.5mm

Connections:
+3V3: C9.1, C16.1, C18.1, C19.1, C22.1, C23.1, C24.1, C28.2, C53.1, C73.1, C79.1, D5.1, D7.1, J5.3, J20.3, J25.1, J25.2, JP2.1, R38.1, R39.1, TP3v3.1, U2.2, U4.6, U4.11, U4.28, U4.50, U4.73, U4.75, U4.100, U6.13, U6.14, U12.3, U12.7, U12.8, U14.3, U14.7, U14.8, U17.2, U17.9, U17.10
+5V: C2.1, FB1.1, J25.5, U2.3, U3.3
+12V: C25.2, C50.2, C51.2, C64.2, C65.2, C66.1, C77.2, D1.1, J25.11, JP1.9, JP1.10, R2.1, U5.8, U7.8, U10.8, U11.8, U16.8
-12V: C25.1, C50.1, C51.1, C64.1, C67.1, C77.1, D3.2, J25.7, JP1.1, JP1.2, U5.4, U7.4, U10.4, U11.4, U16.4
ADCDAT: U4.38, U6.9
AIN1: C5.1, R9.1, U4.15, U8.7
AIN2: C6.1, R10.1, U4.16, U8.1
AIN3: C7.1, R11.1, U4.17, U9.1
AIN4: C8.1, R12.1, U4.18, U9.7
AIN5: C38.1, R30.1, U1.1, U4.23
AIN6: C39.1, R31.1, U1.7, U4.24
AOUT1: R48.2, U4.29
AOUT2: R49.2, U4.30
AOUT3: R44.2, U4.31
AOUT4: R43.2, U4.32
AOUT5: R83.2, U4.35
AOUT6: R84.2, U4.5
CLKIN: Q1.3, U4.37
DACDAT: U4.87, U6.10
DEBUG: J25.13, TPDEBUG1.1, U4.67
DM: J25.4, U4.70, U15.6
DM_C: J18.2, J24.2, U15.1
DP: J25.3, U4.71, U15.4
DP_C: J18.3, J24.3, U15.3
FSCLK: U4.96, U6.7
GND: C1.1, C2.2, C3.2, C9.2, C10.2, C11.2, C12.2, C13.1, C14.2, C15.1, C16.2, C17.1, C18.2, C19.2, C22.2, C23.2, C24.2, C27.2, C28.1, C29.2, C31.1, C32.2, C33.2, C34.1, C35.1, C36.1, C37.1, C40.1, C41.1, C44.1, C45.1, C52.1, C53.2, C54.2, C55.2, C56.1, C57.1, C58.1, C59.1, C60.1, C61.1, C66.2, C67.2, C68.2, C69.1, C70.2, C73.2, C74.1, C79.2, D2.1, D6.2, D8.2, J1.S, J2.S, J3.S, J3.TN, J4.S, J4.TN, J5.5, J5.7, J5.11, J6.S, J7.S, J8.S, J8.TN, J9.S, J9.TN, J10.S, J11.S, J11.TN, J12.11, J14.S, J15.S, J16.S, J17.S, J18.5, J19.1, J20.4, J21.1, J22.S, J23.S, J24.5, J25.6, J25.12, J25.14, J26.1, J27.1, JP1.3, JP1.4, MT1.1, MT1.COM, Q1.2, R7.2, R13.2, R14.2, R15.2, R24.1, R25.2, R32.2, R33.2, R66.1, R67.1, R87.1, R88.1, R94.1, R95.2, R96.2, R99.1, R105.1, R106.1, RV1.3, RV2.3, TPGND2.1, U1.4, U2.1, U3.1, U4.10, U4.19, U4.20, U4.27, U4.49, U4.74, U4.99, U5.3, U5.5, U6.12, U6.15, U6.18, U6.24, U6.28, U6.33, U8.4, U9.4, U12.4, U13.2, U14.4, U15.2, U16.3, U16.5, U17.3, U17.5, U17.6, U17.7, U17.8, Y1.2, Y1.4
HPL: C42.1, U6.30
HPR: C43.1, U6.29
IO1: MT1.2, U4.7
IO2: MT1.A, U4.8
IO3: MT1.B, U4.9
JTCK: J5.6, T_JTCK1.1, U4.76
JTDI: J5.10, U4.77
JTDO: J5.8, U4.89
JTMS: J5.4, T_JTMS1.1, U4.72
LINEINL: C26.1, U6.3
LINEINR: C30.1, U6.6
LINEOUTL: C71.2, U6.25
LINEOUTR: C72.2, U6.23
MCLK: R34.2, U6.11
MISO: J25.10, U4.84, U12.2, U14.2
MOSI: J25.8, R93.1, U12.5, U14.5
N1: J12.1, U4.83
N2: J12.3, U4.86
N3: J12.5, U4.88
N4: J12.7, U4.81
N5: J12.9, U4.62
NRST: C11.1, J5.12, T_NRST1.1, U4.14
unnamed: C4.1, D2.2, D3.1
unnamed: C4.2, D1.2, L1.2, U13.1
unnamed: C5.2, R1.1, R9.2, U8.6
unnamed: C6.2, R3.1, R10.2, U8.2
unnamed: C7.2, R4.1, R11.2, U9.2
unnamed: C8.2, R5.1, R12.2, U9.6
unnamed: C12.1, U4.12, Y1.1
unnamed: C13.2, C75.1, D14.2, D15.1, R36.1, R37.1, R101.2, R105.2, U16.2
unnamed: C14.1, U4.13, Y1.3
unnamed: C15.2, C76.1, D16.2, D17.1, R22.1, R56.1, R102.2, R106.2, U16.6
unnamed: C20.1, R18.1, R20.2, U5.1
unnamed: C20.2, R16.1, R18.2, U5.2
unnamed: C21.1, R19.1, R21.2, U5.7
unnamed: C21.2, R17.1, R19.2, U5.6
unnamed: C26.2, C75.2, D18.1, D19.2, R101.1, U16.1
unnamed: C29.1, U6.27
unnamed: C30.2, C76.2, D20.1, D21.2, R102.1, U16.7
unnamed: C32.1, U6.20
unnamed: C33.1, U6.19
unnamed: C36.2, U4.1
unnamed: C37.2, U4.41
unnamed: C38.2, R26.1, R30.2, U1.2
unnamed: C39.2, R27.1, R31.2, U1.6
unnamed: C42.2, J21.2, J27.2, R33.1
unnamed: C43.2, J21.3, J27.3, R32.1
unnamed: C44.2, R42.1, U11.5
unnamed: C45.2, R46.1, U10.5
unnamed: C46.1, R42.2, R44.1
unnamed: C46.2, R45.2, R52.2, U11.7
unnamed: C47.1, R43.1, R46.2
unnamed: C47.2, R47.2, R53.2, U10.7
unnamed: C48.1, R54.2, U11.1
unnamed: C48.2, R48.1, R50.2, U11.2
unnamed: C49.1, R55.2, U10.1
unnamed: C49.2, R49.1, R51.2, U10.2
unnamed: C52.2, U4.57
unnamed: C56.2, U4.90
unnamed: C57.2, U4.51
unnamed: C58.2, U4.63
unnamed: C59.2, U4.78
unnamed: C60.2, R85.1, U7.3
unnamed: C61.2, R86.1, U7.5
unnamed: C62.1, R83.1, R85.2
unnamed: C62.2, R90.2, R91.2, U7.1
unnamed: C63.1, R84.1, R86.2
unnamed: C63.2, R89.2, R92.2, U7.7
unnamed: C65.1, R2.2, R7.1, U13.3
unnamed: C71.1, R14.1, R16.2
unnamed: C72.1, R15.1, R17.2
unnamed: D4.1, D9.1, FB1.2
unnamed: D9.2, JP1.11, JP1.12
unnamed: D14.1, D18.2
unnamed: D15.2, D19.1
unnamed: D16.1, D20.2
unnamed: D17.2, D21.1
unnamed: J1.T, R1.2, R95.1
unnamed: J1.TN, R97.2
unnamed: J2.T, R3.2, R96.1
unnamed: J2.TN, R100.2
unnamed: J3.T, R4.2
unnamed: J4.T, R5.2
unnamed: J6.T, J7.TN, R20.1
unnamed: J7.T, R21.1
unnamed: J8.T, R26.2
unnamed: J9.T, R27.2
unnamed: J10.T, R36.2
unnamed: J10.TN, R22.2
unnamed: J11.T, R8.2
unnamed: J12.2, R58.2
unnamed: J12.4, R59.2
unnamed: J12.6, R60.2
unnamed: J12.8, R61.2
unnamed: J12.10, R62.2
unnamed: J12.12, R63.2
unnamed: J12.14, R64.2
unnamed: J12.16, R65.2
unnamed: J13.1, R75.1
unnamed: J13.2, R41.2
unnamed: J13.3, R76.1
unnamed: J13.4, R68.2
unnamed: J13.5, R77.1
unnamed: J13.6, R69.2
unnamed: J13.7, R78.1
unnamed: J13.8, R70.2
unnamed: J13.9, R79.1
unnamed: J13.10, R71.2
unnamed: J13.11, R80.1
unnamed: J13.12, R72.2
unnamed: J13.13, R81.1
unnamed: J13.14, R73.2
unnamed: J13.15, R82.1
unnamed: J13.16, R74.2
unnamed: J14.T, R52.1
unnamed: J15.T, R53.1
unnamed: J16.T, R50.1, R54.1
unnamed: J17.T, R51.1, R55.1
unnamed: J19.2, J26.2, R37.2
unnamed: J19.3, J26.3, R56.2
unnamed: J22.T, R91.1
unnamed: J23.T, R92.1
unnamed: JP2.2, R13.1, U4.94
unnamed: JP3.1, R94.2, U4.36
unnamed: Q1.1, R8.1
unnamed: R34.1, U4.95
unnamed: R45.1, R66.2, U11.6
unnamed: R47.1, R67.2, U10.6
unnamed: R57.2, U4.82
unnamed: R87.2, R90.1, U7.2
unnamed: R88.2, R89.1, U7.6
unnamed: R93.2, U4.85
P1: R58.1, U4.40
P2: R59.1, U4.68
P3: R60.1, U4.69
P4: R61.1, U4.45
P5: R62.1, U4.60
P6: R63.1, U4.61
P7: R64.1, U4.25
P8: R65.1, U4.26
POT1: C68.1, RV2.2, U4.33
POT2: C70.1, RV1.2, U4.34
RX: J5.13, J25.16, U4.56
SCL: J20.2, R38.2, U4.47, U6.16, U17.1
SCLK: U4.4, U6.8
SDA: J20.1, R39.2, U4.48, U6.17, U17.4
SENSE: D7.2, D8.1, R100.1, U4.39
SENSE2: D5.2, D6.1, R97.1, U4.46
SPICLK: J25.9, R57.1, U12.6, U14.6
SPICS: U4.98, U12.1
SPICS2: U4.97, U14.1
T1: R41.1, U4.52
T2: R68.1, U4.91
T3: R69.1, U4.79
T4: R70.1, U4.53
T5: R71.1, U4.92
T6: R72.1, U4.80
T7: R73.1, U4.54
T8: R74.1, U4.93
T9: R75.2, U4.64
T10: R76.2, U4.42
T11: R77.2, U4.58
T12: R78.2, U4.65
T13: R79.2, U4.43
T14: R80.2, U4.59
T15: R81.2, U4.66
T16: R82.2, U4.44
TS1: R40.2, U4.2
TS1_: J12.15, JP4.1, R40.1
TS2: R35.2, U4.3
TS2_: J12.13, JP3.2, R35.1
TX: J5.14, J25.15, U4.55
VBUS: C3.1, C74.2, D4.2, J18.1, J24.1, L1.1, R25.1, T_VBUS1.1, U13.4, U13.5, U15.5
VDDA: C1.2, C10.1, C27.1, C31.2, C40.2, C41.2, C54.1, C55.1, U1.8, U3.2, U4.22, U6.26, U6.31, U8.8, U9.8
VREF: C34.2, JP4.2, R28.2, R98.2, RV1.1, RV2.1, U4.21
VREF1: C17.2, R24.2, R29.1, U1.3, U1.5, U8.3, U9.3, U9.5
VREF125: C35.2, R28.1, R29.2, U8.5
VREF_125_OUT: C69.2, R98.1, R99.2, U10.3, U11.3

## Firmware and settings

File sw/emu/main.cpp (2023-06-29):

#include <math.h>
#include <stdio.h>
#include <stdlib.h>
#include <imgui.h>
#include "imgui_impl_glfw.h"
#include "imgui_impl_opengl3.h"
#include <GL/gl3w.h>    // This example is using gl3w to access OpenGL functions (because it is small). You may use glew/glad/glLoadGen/etc. whatever already works for you.
#include <GLFW/glfw3.h>
#ifdef _WIN32
#include <shellscalingapi.h>
#else
#include <sys/stat.h>
#endif
#include <thread>
#include "pffft.h"
#include <portaudio.h>
#include "../Core/Src/config.h"

#ifdef _WIN32

#pragma comment(lib,"winmm.lib") // midi
#pragma comment(lib,"shcore.lib") // dpi
#pragma comment(lib,"opengl32.lib") // for wglGetProcAddress
#ifdef _WIN64
#pragma comment(lib,"portaudio/lib/portaudio_x64.lib") 
#pragma comment(lib,"imgui/glfw/lib-vc2010-64/glfw3.lib") // for imgui rendering
#else
#pragma comment(lib,"portaudio/lib/portaudio_x86.lib") 
#pragma comment(lib,"imgui/glfw/lib-vc2010-32/glfw3.lib") // for imgui rendering
#endif

#endif  // _WIN32

//#define STRETCH_PROTO


bool enable_emu_audio = true;


#define USER_DEFAULT_SCREEN_DPI 96

#define STB_IMAGE_IMPLEMENTATION
#define STB_IMAGE_WRITE_IMPLEMENTATION
#include "stb_image.h"
#include "stb_image_write.h"

#define FS 32000
#ifdef STRETCH_PROTO
#define BLOCK_SAMPLES 512
#else
#define BLOCK_SAMPLES 64
#endif

typedef unsigned char u8;
typedef unsigned int u32;
typedef short s16;
typedef signed char s8;

extern "C" {
	extern unsigned short expander_out[4];
	uint32_t emupixels[128 * 32];
	int16_t accel_raw[3];
	float accel_lpf[2];
	float accel_smooth[2];
	void resetspistate(void);
	void spi_update_dac(int chan) {
		resetspistate();
	}

	void emu_setadc(float araw, float braw, float pitchcv, float gatecv, float xcv, float ycv, float acv, float bcv, int gateforce, int pitchsense, int gatesense);

	void plinky_frame();
	void plinky_init();
	void uitick(u32* dst, const u32* src, int half);
	extern float gainhistoryrms[512];
	extern int ghi;
	extern float knobhistory[512];
	extern int khi;
	typedef unsigned short u16;
	extern volatile int encval;
	extern volatile u8 encbtn;

	extern float arpdebug[1024];
	extern int arpdebugi;

	extern int emucvouthist;
	extern float emucvout[6][256];
	extern float emupitchloopback;
	extern int emupitchsense, emugatesense;

	void ApplyUF2File(const char* fname);

	extern int samplelen;
	typedef struct FingerRecord {
		u8 pos[4];
		u8 pressure[8];
	} FingerRecord;
	typedef struct Preset {
		s16 params[96][8];
		u8 arpon;
		s8 loopstart_step;
		s8 looplen_step;
		u8 paddy[16 - 3];
	} Preset;
	typedef struct PatternQuarter {
		FingerRecord steps[16][8];
		s8 autoknob[16 * 8][2];
	} PatternQuarter;
	extern Preset rampreset;
	extern PatternQuarter rampattern[4];
	extern s8 cur_step;
#include "../Core/Src/adc.h"
#include "../Core/Src/wtenum.h"
	extern const short wavetable[WT_LAST][WAVETABLE_SIZE ];
}

static GLFWwindow* window;

static PaStream *stream;
static PaError err;
void paerror(const char *e) {
	printf(  "PortAudio error: %s-> %s\n", e, Pa_GetErrorText( err ) );
	exit(1);
}  


FILE* WriteWAVHeader(const char* fname) {
	FILE* f = fopen(fname, "wb");
	if (!f) {
		printf("Failed to open file %s %d (%s)\n", fname, errno, strerror(errno));
		return f;
	}
	fseek(f, 44, SEEK_SET);
	return f;
}

void UpdateWAVHeader(FILE* f, u32 fs, u32 chans) {
	fflush(f); // make sure we've written all the data
	u32 filelen = ftell(f);
	fseek(f, 0, SEEK_SET);
	u32 wavhdr[11] = { 0x46464952,filelen - 8,0x45564157,0x20746d66, 0x00000010,0x00000001 + (chans << 16), (u32)fs, (u32)fs * 4, 0x00100000 + (chans * 2),0x61746164,filelen - 44 };
	fwrite(wavhdr, 1, 44, f);
	fseek(f, filelen, SEEK_SET);
}

void FinishWAVHeader(FILE* f, u32 fs, u32 chans) {
	UpdateWAVHeader(f, fs, chans);
	fclose(f);
}
FILE* wavfile;
extern "C" int getheadphonevol(void);

#ifdef STRETCH_PROTO
#define WINDOWSIZE 16384
float inputtape[512 * 1024];
int inputpos = 0;
int inputjitter = 4096;
float pitches[4] = {0.f,0.f,12.f,-12.f};
float unison = 0.1f;
float attack = 0.6f, decay = 0.6f;
int inputdelay = 0;
PFFFT_Setup* fftsetup32768;
float outputtape[2][WINDOWSIZE];
#define PI 3.1415926535897932384626433832795f
float fftwindow(int i) {
	return 1.f - cosf(i * PI * 2.f / WINDOWSIZE);
}
void SplatFFT(float* dst, int dstpos) {
	static __declspec(align(32)) float tmp[WINDOWSIZE];
	static __declspec(align(32 )) float fft[WINDOWSIZE];
	static __declspec(align(32)) float mag[WINDOWSIZE/2];
	memset(tmp, 0, sizeof(tmp));
	float kattack = 1.f-attack;
	float kdecay = 1.f-decay;
	kattack *= kattack; kdecay *= kdecay;
	kattack *= kattack; kdecay *= kdecay;
	for (int chan = 0; chan < 4; ++chan) {
		float ptch = (chan - 1.5f) * unison + pitches[chan];
		ptch = exp2f(ptch * 1.f / 12.f);
		int basepos = int(inputpos - ptch * WINDOWSIZE - inputdelay - 1 - (rand() % inputjitter)) & (512 * 1024 - 1);
		for (int i = 0; i < WINDOWSIZE; ++i) {

			float fpos = (i*ptch);
			int pos = int(floor(fpos) + basepos)& (512 * 1024 - 1);
			fpos -= floor(fpos);
			float a = inputtape[pos];
			pos = (pos + 1) & (512 * 1024 - 1);
			float b = inputtape[pos];
			a += (b - a) * fpos;
			tmp[i] += fftwindow(i) * a * (1.f/(1.f+chan));
		}
	}
	pffft_transform_ordered(fftsetup32768, tmp, fft, nullptr, PFFFT_FORWARD);
	for (int i = 2; i < WINDOWSIZE; i+=2) {
		float phase = rand() * (PI * 2.f / RAND_MAX);
		float ss = sinf(phase) / float(WINDOWSIZE), cc=cosf(phase) / float(WINDOWSIZE);
		float re = fft[i], im = fft[i + 1];
		float mg = sqrtf(re * re + im * im);
		float& mgsmooth = mag[i / 2];
		mgsmooth += (mg - mgsmooth) * ((mg > mgsmooth) ? kattack : kdecay);
		fft[i] = mgsmooth * cc; //  re* cc - im * ss;
		fft[i + 1] = mgsmooth * ss; //  im* cc + re * ss;
	}
	fft[0] *= 0.f / WINDOWSIZE;
	fft[1] *= 0.f / WINDOWSIZE;
	pffft_transform_ordered(fftsetup32768, fft, tmp, nullptr, PFFFT_BACKWARD);
	for (int i = 0; i < WINDOWSIZE; ++i)
		dst[(i+dstpos)&(WINDOWSIZE-1)] += fftwindow(i) * tmp[i] * (float(BLOCK_SAMPLES)/WINDOWSIZE);
}

bool recording = false;
#endif

int pacb( const void *input,
	void *output,
	unsigned long frameCount,
	const PaStreamCallbackTimeInfo* timeInfo,
	PaStreamCallbackFlags statusFlags,
	void *userData )  {

#ifdef STRETCH_PROTO
	if (recording) {
		for (int i = 0; i < BLOCK_SAMPLES; ++i) {
			inputtape[inputpos] = ((const float*)input)[i*2];
			inputpos = (inputpos + 1) & (1024 * 512 - 1);
		}
	}
	static int side = 0;
	static int dstpos = 0;
	SplatFFT(outputtape[side], dstpos);
	for (int i = 0; i < BLOCK_SAMPLES; ++i) {
		((float*)output)[i * 2 + 0] = outputtape[0][(dstpos + i) & (WINDOWSIZE-1)]; outputtape[0][(dstpos + i) & (WINDOWSIZE - 1)] = 0.f;
		((float*)output)[i * 2 + 1] = outputtape[1][(dstpos + i) & (WINDOWSIZE - 1)]; outputtape[1][(dstpos + i) & (WINDOWSIZE - 1)] = 0.f;
	}
	dstpos += BLOCK_SAMPLES;
	side = 1 - side;

#else
	static u32 audioin[BLOCK_SAMPLES];
	u32 temp[BLOCK_SAMPLES];
	static int half;
	half = 1 - half;
	float hpvol = getheadphonevol() * (1.f/32768.f/63.f);
#define PI 3.1415926535897932384626433832795f
	{
		float* src = (float*)input;
		short* dst = (short*)audioin;
		static float theta = 0.f;
		for (int i = 0; i < BLOCK_SAMPLES; ++i) {
			float l = src ? *src++:0;
			float r = src ? *src++:0;
			if (0) {
				r = l = sinf(theta) * sinf(theta * 0.001f) * 0.125f;
				theta += 440.f * PI * 2.f / 32000.f;
				if (theta >= PI * 2.f * 1000.f)
					theta -= PI * 2.f * 1000.f;
			}
			*dst++ = (short)(l * (32767.f));
			*dst++ = (short)(r * (32767.f));
		}
	}
	uitick(temp, audioin, half);
	float *dst=(float*)output;
	short* src = (short*)temp;
	for (int i=0;i<BLOCK_SAMPLES;++i) {
		short l = *src++;
		short r = *src++;
		*dst++ = l*hpvol;
		*dst++ = r*hpvol;
	}
	if (wavfile) {
		fwrite(temp, 4, BLOCK_SAMPLES, wavfile);
		static int counter;
		if (counter++ > 100) {
			counter = 0;
			UpdateWAVHeader(wavfile, FS, 2);

		}

	}
#endif
	return 0;
}

static void glfw_error_callback(int error, const char* description){    fprintf(stderr, "Error %d: %s\n", error, description);}
#undef min
#undef max

int clampi(int x, int mn, int mx) { return (x<mn)?mn:(x>mx)?mx:x; }

extern "C" u8 emuleds[9][8];
u8 emuleds[9][8];

int buttonsw, buttonsh, buttonscomp;
GLuint oledtex,buttonstex;
//#define ROTATE_OLED
#ifdef ROTATE_OLED
const static int oledw = 32, oledh = 128;
#else
const static int oledw=128,oledh=32;
#endif
int Knob(const char *label, float &curval, float *randamount, float minval, float maxval, unsigned int encodercol, float size);

extern "C" void EmuStartSound(void) {
	if (enable_emu_audio) {
		err = Pa_StartStream(stream);
		if (err != paNoError)
			paerror("start");
	}
}

float GRandom() {
	return rand()/float(RAND_MAX);
}
extern "C" short _flashram[8 * 2 * 1024 * 1024];
extern "C" int emutouch[9][2];
int emutouch[9][2];


typedef struct Sample {
	// fmt
	u16 formattag, nchannels;
	u32 samplerate, bytespersec;
	u16 blockalign, bitspersample;
	int datastart;
	int dataend;
	int numsamples;
	int firstsample;
	short *samples;
} Sample;
Sample s;


static inline short read_sample(Sample* s, int pos, int chan) { // resample to 32khz crudely
	if (chan >= s->nchannels) chan = 0;
	int64_t p64 = (int64_t(pos) * s->samplerate * 65536) / 32000;
	int si = int(p64 >> 16);
	if (si<0 || si >= s->numsamples - 1)
		return 0;
	int f = (int)(p64 & 65535);
	return (s->samples[si*s->nchannels] * (65536 - f) + s->samples[si * s->nchannels + s->nchannels] * f) >> 16;
}

const char* ParseWAV(Sample* s, const char* fname) {
	memset(s, 0, sizeof(*s));
	FILE* f = fopen(fname, "rb");
	if (!f)
		return "cant open";
	u32 wavhdr[3] = { 0 };
	fread(wavhdr, 4 , 3, f);
	if (wavhdr[0] != 0x46464952) return "bad header 1";
	if (wavhdr[2] != 0x45564157) return "bad header 2";
	while (!feof(f)) {
		if (fread(wavhdr, 1, 8,f)<8) break;
		int nextchunk = ftell(f) + wavhdr[1] + (wavhdr[1] & 1);
		if (wavhdr[0] == 0x61746164) { // 'data'
			s->datastart = ftell(f);
			s->dataend = s->datastart + wavhdr[1];
			int bytespersample = s->bitspersample / 8 * s->nchannels;
			s->numsamples = wavhdr[1] / (bytespersample);
			s->firstsample = s->datastart / bytespersample;
			printf("%d channels, %d samplerate, %d bits, %d samples\r\n", s->nchannels, s->samplerate, s->bitspersample, s->numsamples);
			s->samples = new short[(s->numsamples * s->nchannels * s->bitspersample / 8+3)/2];
			s->numsamples =(int) fread(s->samples, s->nchannels * s->bitspersample/8, s->numsamples, f);
			if (s->bitspersample == 24) {
				for (int i = 0; i < s->numsamples * s->nchannels; ++i) {
					short sh = *(short*) (((char*)(s->samples)) + (i * 3+1));
					s->samples[i] = sh;
				}
				s->bitspersample = 16;
			}
			fclose(f);
			return 0;
		}
		else if (wavhdr[0] == 0x20746d66) { // 'fmt '
			fread(s, 1,16, f);
			if (s->formattag != 1)
				return fclose(f), "bad formattag";
			if (s->nchannels < 1 || s->nchannels>2)
				return fclose(f), "bad channel count";
			if (s->bitspersample < 16)
				return fclose(f),"bad bits per sample";
		//	if (s->samplerate < 8000 || s->samplerate>48000)
		//		return fclose(f),"bad samplerate";
		}
		fseek(f, nextchunk, SEEK_SET);
	}
	fclose(f);
	return "error";
}

void EmuFrame();
extern "C" float life_damping;
extern "C" float life_force;
extern "C" float p_grainpos ;
extern "C" float p_grainsize ;
extern "C" float p_timestretch;
extern "C" float p_pitchy;
extern "C" int64_t p_playhead;
extern "C" float m_compressor, m_dry, m_audioin, m_dry2wet, m_delaysend, m_delayreturn, m_reverbin, m_reverbout, m_fxout, m_output;

extern "C" float lfo_eval(u32 ti, float warp, unsigned int shape);


float dflux[4096];
static float keys[64][128];
int slicepos[64];
u8 slicenote[64];
float slicepeak[64];
float sliceflux[64];
bool snappos=true;
int maxstep;
float maxdflux;
inline float maxf(float a, float b) {
	return (a > b) ? a : b;
}
inline int maxi(int a, int b) {
	return (a > b) ? a : b;
}
inline int mini(int a, int b) {
	return (a < b) ? a : b;
}
inline float clampf(float a, float mn, float mx) {
	return (a < mn) ? mn : (a > mx) ? mx : a;
}

#ifdef _WIN32
HMIDIIN hmidiin;
HMIDIOUT hmidiout;
u32 midiq[256];
u32 midiqw, midiqr;
void CALLBACK midicb(
	HMIDIIN   hMidiIn,
	UINT      wMsg,
	DWORD_PTR dwInstance,
	DWORD_PTR dwParam1,
	DWORD_PTR dwParam2
) {
	// midi in looks like dwParam1 is what we want - 00643090 00403080
//	printf("%08x %08x %08x midi\n", wMsg, dwParam1, dwParam2);
	if (midiqw-midiqr<256) 
		midiq[(midiqw++) & 255] = dwParam1;
}
extern "C" bool midi_receive(unsigned char packet[4]) {
	if (midiqr == midiqw) return false;
	u32 mm = midiq[(midiqr++) & 255];
	packet[0] = (mm >> 4)&15;
	packet[1] = mm >> 0;
	packet[2] = mm >> 8;
	packet[3] = mm >> 16;
	return true;
}
extern "C" bool send_midimsg(u8 status, u8 data1, u8 data2) {
	//if (status == 0x90) printf("------------- DOWN %d (%d)\n", data1, data2);
	//else if (status == 0x80) printf("------------- UP %d\n", data1);
	//else printf("%02x %02x %02x\n", status, data1, data2);
	if (hmidiout)
		if (MIDIERR_NOTREADY == midiOutShortMsg(hmidiout, status + (data1 << 8) + (data2 << 16)))
			return false;
	return true;
}
#else  // _WIN32
// TODO: Add MIDI support on non-Windows platforms.
extern "C" bool midi_receive(unsigned char packet[4]) {
	return false;
}
extern "C" bool send_midimsg(u8 status, u8 data1, u8 data2) {
	return false;
}
#endif

typedef struct CalibResult {
	u16 pressure[8];
	s16 pos[8];
} CalibResult;
extern "C" CalibResult calibresults[18];
extern "C" int flash_readcalib(void);

bool plinky_inited = false;

static float fwavetable[WT_LAST][WAVETABLE_SIZE];
float softtri(float x) {
	x *= PI*0.5f;
	float y=sinf(x)
		- sinf(x * 3.f) / 9.f
		+ sinf(x * 5.f) / 25.f
		- sinf(x * 7.f) / 49.f
		+ sinf(x * 9.f) / 81.f
		- sinf(x * 11.f) / 121.f
		+ sinf(x * 13.f) / 169.f
		- sinf(x * 15.f) / 225.f;
	return y * (8.f / PI / PI);
}
uint32_t wang_hash(uint32_t seed)
{
	seed = (seed ^ 61) ^ (seed >> 16);
	seed *= 9;
	seed = seed ^ (seed >> 4);
	seed *= 0x27d4eb2d;
	seed = seed ^ (seed >> 15);
	return seed;
}
float noisey(int i) {
	return (wang_hash(i) & 65535) / 32768.f - 1.f;
}
Sample cycles[16];
const char* cyclenames[16] = {
//	0,0,0,0,0,0,0,0,0,0,0,0,0,0,0,"c:/temp/ss.wav"
	0,0,
"c:/temp/waves/saw_1024.wav",
"c:/temp/waves/saw_2048.wav",
"c:/temp/waves/saw2_1024.wav",
"c:/temp/waves/saw2_2048.wav",
"c:/temp/waves/wave1_1024.wav",
"c:/temp/waves/wave1_2048.wav",
"c:/temp/waves/wave2_1024.wav",
"c:/temp/waves/wave2_2048.wav",
"c:/temp/waves/wave3_1024.wav",
"c:/temp/waves/wave3_2048.wav",
"c:/temp/waves/wave4_1024.wav",
"c:/temp/waves/wave4_2048.wav",
"c:/temp/waves/wave5_1024.wav",
"c:/temp/waves/wave5_2048.wav",
};
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
int main(int argc, char** argv) {
	const char* midiin_name_to_match = "";
	const char* midiout_name_to_match = "";

	for (int i = 1; i < argc; ++i) if (strcmp(argv[i], "-q") == 0)
		enable_emu_audio = false;
	else if (strcmp(argv[i], "-i") == 0 && i + 1 < argc)
		midiin_name_to_match = argv[++i];
	else if (strcmp(argv[i], "-o") == 0 && i + 1 < argc)
		midiout_name_to_match = argv[++i];


	if (0)
	{
		float kernel[256];
		float totk = 0.f;
		for (int i = 0; i < 256; ++i) {
			float x = i * PI / 28.f; // 32 is good. 24 may be a bit more open
			kernel[i] = i ? (0.5f + 0.5f * cosf(i * PI / 256.f)) * sinf(x) / x : 1.f;
			totk += kernel[i] * (i ? 2.f : 1.f);
		}
		for (int i = 0; i < 256; ++i) {
			kernel[i] /= totk;
		}
		// memoize the shapes :)
		static float wshape[WT_LAST][65536];
		for (int shape = 0; shape < WT_LAST; ++shape)
			for (int i = 0; i < 65536; ++i)
				wshape[shape][i] = eval_wave(shape, i);
		FILE* fh = fopen("../Core/Src/wavetable.h", "w");
		if (fh) {
			fprintf(fh, "// generated for WT_LAST %d WAVETABLE_SIZE %d \nconst short wavetable[%d][%d]={\n", WT_LAST,WAVETABLE_SIZE, WT_LAST, WAVETABLE_SIZE);
		}
		for (int shape = 0; shape < WT_LAST; ++shape) {
			//s16* dst = wavetable + shape * WAVETABLE_SIZE;
			float* fdst = fwavetable[shape];
			if (fh) fprintf(fh, "\t// %s\n\t{", wavetablenames[shape]);
			for (int octave = 0; octave < 9; ++octave) {
				int n = (512 >> octave);
				for (int i = 0; i <= n; ++i) {
					float x = 0.f;
					for (int j = -255; j < 256; ++j) {
						x += kernel[abs(j)] * wshape[shape][65535 & ( (i << (octave + 7)) + (j << (octave+2)))];
					}
					*fdst++ = x;	
					short s = /**dst++ = */ x * (16384.f);
					if (fh) fprintf(fh, "%d,", s);
				}
				if (fh) fprintf(fh, "\n\t");
			}
			if (fh) fprintf(fh, "},");

		}
		if (fh) {
			fprintf(fh, "\n};\n");
			fclose(fh);
		}

	}

	// lpzw text converter
	if (0)
	{
		int w, h, comp;
		u8* bmp = stbi_load("c:/temp/lpzwtext_bw.png", &w, &h, &comp, 1);
		int xpos[128] = { 0 };
		int x = 0, y = 0;
		int ox = 0;
		uint8_t obmp[24][1024] = {};
		printf("static const uint16_t font24_xpos[] PROGMEM ={\n");
		for (int c = 33; c<0x60; ++c) {
			while (1) { for (y = 0; y < h; ++y) if (bmp[x + y * w] < 128) break; if (y < h) break; ++x;  } // skip white
			int x1 = x;
			while (1) { for (y = 0; y < h; ++y) if (bmp[x + y * w] < 128) break; if (y == h) break;++x;  } // skip black
			int x2 = x;
			if (c == '"') {
				while (1) { for (y = 0; y < h; ++y) if (bmp[x + y * w] < 128) break; if (y < h) break; ++x; } // skip white
				while (1) { for (y = 0; y < h; ++y) if (bmp[x + y * w] < 128) break; if (y == h) break; ++x; } // skip black
				x2 = x;
			}
			printf("%d,", ox);
			for (int xx = x1; xx < x2; ++xx) for (int yy = 0; yy < 24; ++yy)
				obmp[yy][ox + (x2-x1-1) - (xx - x1)] = bmp[xx + yy * w] ^ 255; // flipped in x
			ox += (x2 - x1);
		}
		printf("%d};\n", ox);
		ox += 7; ox &= ~7;
		int nb = ox / 8;
		printf("static const uint8_t font24[24][%d] PROGMEM = {\n", nb);
		for (int y = 0; y < 24; ++y) {
			for (int x = 0; x < nb; ++x) {
				u8 b = 0;
				for (int xx = 0; xx < 8; ++xx) {
					if (obmp[y][xx + x * 8] > 128) 
						b |= 1 << xx;
				}
				printf("0x%02x,", b);
			}
			printf("\n");
		}
		printf("};\n");
	}




	/* dart throwing logo generator :) *
	int w, h, comp;
	u8* bmp = stbi_load("plinkydots4k.png", &w, &h, &comp, 1);

	float* sdf = new float[w * h];
	for (int y = 0; y < h; ++y) for (int x = 0; x < w; ++x) sdf[y * w + x] = (bmp[y * w + x] < 128) ? 0.f : w*2;
	int iters = 0;
	while (iters<8) {
		printf("%d\n", iters++);
		bool more = false;
		int x1 = (iters & 1) ? 0 : w-1;
		int x2 = (iters & 1) ? w : -1;
		int y1 = (iters & 2) ? 0 : h-1;
		int y2 = (iters & 2) ? h : -1;
		for (int y = y1; y != y2; y+=(y1<y2)?1:-1) for (int x = x1; x !=x2 ; x+=(x1<x2)?1:-1) {
			float d = sdf[y * w + x];
			float od = w * 2;
			if (y > 0 && x > 0 && (od = sdf[(y - 1) * w + (x - 1)] + 1.414f) < d) sdf[y * w + x] = d = od;
			if (y > 0 && (od = sdf[(y - 1) * w + (x)] + 1.000f) < d) sdf[y * w + x] = d = od;
			if (y > 0 && x < w - 1 && (od = sdf[(y - 1) * w + (x + 1)] + 1.414f) < d) sdf[y * w + x] = d = od;

			if (x > 0 && (od = sdf[(y + 0) * w + (x - 1)] + 1.f) < d) sdf[y * w + x] = d = od;
			if (x < w - 1 && (od = sdf[(y + 0) * w + (x + 1)] + 1.f) < d) sdf[y * w + x] = d = od;

			if (y < h - 1 && x > 0 && (od = sdf[(y + 1) * w + (x - 1)] + 1.414f) < d) sdf[y * w + x] = d = od;
			if (y < h - 1 && (od = sdf[(y + 1) * w + (x)] + 1.000f) < d) sdf[y * w + x] = d = od;
			if (y < h - 1 && x < w - 1 && (od = sdf[(y + 1) * w + (x + 1)] + 1.414f) < d) sdf[y * w + x] = d = od;
			if (od < w * 2)
				more = true;
		}
		if (!more)
			break;
	}
	//for (int y = 0; y < h; ++y) for (int x = 0; x < w; ++x) bmp[y * w + x] = sdf[y * w + x]*(255.f/w);
	//stbi_write_png("plinkysdf.png", w, h, 1, bmp, w);
	memset(bmp, 255, w * h);
	for (int j = 0;j < 2000000; ++j) {
		if ((j%100000)==0)
			printf("%d\n", j);
		int x = rand() % w;
		int y = rand() % h;
		float rmax = sdf[y * w + x] ;
		rmax *= 0.125f * 0.75f;
		rmax += 5.f;
		if (rmax <= 5.5f) continue;
		int i = int(rmax + 1.f);
		bool ohno = false;
		for (int y2 = -i; y2 <= i; ++y2) {
			int xr = 1.f + sqrtf(rmax * rmax - y2 * y2);
			int yy = y + y2;
			if (yy < 0 || yy >= h) continue;
			for (int x2 = maxi(0, x - xr); x2 <= x + xr && x2 < w; ++x2) if (bmp[yy * w + x2]<128 && (x2 - x) * (x2 - x) + y2 * y2 < rmax * rmax) {
				ohno = true;
				break;
			}
			if (ohno)
				break;
		}
		if (ohno)
			continue;
		float rr = 4.f + rmax * 0.05f;
		if (rr > 6.f) rr = 6.f;
		for (int x2 = -6; x2 <= 6; ++x2) for (int y2 = -6; y2 <= 6; ++y2) {
			int xx = x + x2;
			int yy = y + y2;
			int dd = x2 * x2 + y2 * y2;
			if (dd<rr*rr && xx>=0 && yy>=0 && xx<w && yy<h)
				bmp[yy * w + xx] = mini(bmp[yy * w + xx],255-255*clampf(rr-sqrtf(dd),0.f,1.f));
		}
		
	}
	stbi_write_png("plinkydots.png", w, h, 1, bmp, w);

	*/

	if (0) {
		// alpha channel fiddler
		int w, h, comp;
		u8* bmp = stbi_load("../../docs/web/plinky_black_small.png", &w, &h, &comp, 4);
		u8* pix = bmp;
		for (int i = 0; i < w * h; ++i) {
			pix[3] = mini(pix[3], 255 - pix[0]);
			pix[0] = pix[1] = pix[2] = 255;
			pix += 4;
		}
		stbi_write_png("../../docs/web/plinky_alpha_small.png", w, h, 4, bmp, w * 4);
		pix = bmp;
		for (int i = 0; i < w * h; ++i) {
			pix[0] = pix[1] = pix[2] = 0;
			pix += 4;
		}
		stbi_write_png("../../docs/web/plinky_alpha_small_black.png", w, h, 4, bmp, w * 4);
		free(bmp);
	}
	//SetProcessDpiAwareness(PROCESS_PER_MONITOR_DPI_AWARE);

	/*
	// print out lfo shapes for excel sheet
	for (int i = 0; i < 256; ++i) {
		float warp = (i >= 128) ? (i >= 192) ? 0.875f : 0.125f : 0.5f;
		for (int j=0;j<10;++j) 
			printf("%0.2f ", lfo_eval(i * 65536 / 64, warp, j));
		printf("\n");
	}*/

//	PFFFT_Setup* fftsetup256 = pffft_new_setup(256, PFFFT_REAL);
//	PFFFT_Setup* fftsetup2048 = pffft_new_setup(2048, PFFFT_REAL);
#ifdef STRETCH_PROTO
	fftsetup32768 = pffft_new_setup(WINDOWSIZE, PFFFT_REAL);
#endif

	const char* fname =
	//	"C:\\Users\\mmalex\\Dropbox\\think.wav";
	//"C:\\Users\\mmalex\\Dropbox\\pv\\samples\\amen.wav";
	//	"C:\\Users\\mmalex\\Dropbox\\pianohome.wav";
	//			"C:\\Users\\mmalex\\Dropbox\\pianohome2.wav";
	"C:\\Users\\mmalex\\Dropbox\\pv\\samples\\164718__bradovic__piano.wav";
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

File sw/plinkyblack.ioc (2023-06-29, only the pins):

PC12.Signal=TSC_G3_IO4
PB13.Signal=TSC_G1_IO2
PE6.GPIO_Label=CVOUT_TRIG
PD4.Signal=SPI2_MOSI
PB6.Signal=TSC_G2_IO3
PC7.Signal=TSC_G4_IO2
PC3.Signal=ADCx_IN4
PD0.Signal=GPIO_Output
PD8.Signal=USART3_TX
PE5.Signal=SAI1_SCK_A
PE1.Signal=GPIO_Output
PB2.Signal=GPXTI2
PE9.Signal=S_TIM1_CH1
PE2.Signal=TSC_G7_IO1
PA8.Signal=GPIO_Input
PE10.Signal=TSC_G5_IO1
PA0.Signal=ADCx_IN5
PB9.Signal=SAI1_FS_A
PD12.Signal=TSC_G6_IO3
PA10.Signal=S_TIM1_CH3
PD15.Signal=GPIO_Output
PC13.Signal=GPIO_Input
PD3.Signal=SPI2_MISO
PC6.Signal=TSC_G4_IO1
PC2.Signal=ADCx_IN3
PD7.Signal=GPIO_Output
PD1.Signal=SPI2_SCK
PC0.Signal=ADCx_IN1
PD10.Signal=TSC_G6_IO1
PA8.GPIO_Label=DEBUG
PE8.GPIO_Label=SENSE1
PA9.Signal=S_TIM1_CH2
PB10.Signal=I2C2_SCL
PB14.Signal=TSC_G1_IO3
PA5.Signal=COMP_DAC12_group
PE1.GPIO_Label=CS1
PE14.Signal=S_TIM1_CH4
PE15.Signal=GPIO_Input
PE8.Signal=GPIO_Input
PA4.Signal=COMP_DAC11_group
PB5.Signal=TSC_G2_IO2
PD11.Signal=TSC_G6_IO2
PA11.Signal=USB_OTG_FS_DM
PE3.Signal=TSC_G7_IO2
PD2.Signal=GPIO_Output
PB0.Signal=S_TIM3_CH3
PC1.Signal=ADCx_IN2
PD2.GPIO_Label=N1
Mcu.UserName=STM32L476VGTx
PC10.Signal=TSC_G3_IO2
PD0.GPIO_Label=N4
PB0.GPIO_Label=CVOUT_CLK
PC13.GPIO_Label=IO1
PB11.Signal=I2C2_SDA
PB15.Signal=TSC_G1_IO4
PD13.Signal=S_TIM4_CH2
PA12.Signal=USB_OTG_FS_DP
PE13.Signal=TSC_G5_IO4
PB7.Signal=TSC_G2_IO4
PE4.Signal=TSC_G7_IO3
PD7.GPIO_Label=N3
PA6.Signal=S_TIM3_CH1
PD5.GPIO_Label=N2
PE0.GPIO_Label=CS2
PC5.Signal=ADCx_IN14
PE7.Signal=SAI1_SD_B
PD6.Signal=SAI1_SD_A
PA3.Signal=S_TIM2_CH4
PD15.GPIO_Label=N5
PC11.Signal=TSC_G3_IO3
PC8.Signal=TSC_G4_IO3
PC4.Signal=ADCx_IN13
PD9.Signal=USART3_RX
PD5.Signal=GPIO_Output
PE15.GPIO_Label=SENSE2
PE11.Signal=TSC_G5_IO2
PA1.Signal=ADCx_IN6
PE6.Signal=S_TIM3_CH4
PE0.Signal=GPIO_Output
PE12.Signal=TSC_G5_IO3
PA2.Signal=S_TIM2_CH3
PD14.Signal=S_TIM4_CH3
PB2.GPIO_Label=CLKIN
PB8.Signal=SAI1_MCLK_A
PC9.Signal=TSC_G4_IO4
PB12.Signal=TSC_G1_IO1
PA7.Signal=S_TIM3_CH2

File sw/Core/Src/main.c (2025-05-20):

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

/* Includes ------------------------------------------------------------------*/
#include "main.h"

/* USER CODE BEGIN Includes */
#define FLASH_LATENCY_5 FLASH_LATENCY_4 // WOOHAHAHAHAH
#include "core.h"
#include <stdlib.h>
#include <string.h>
/* USER CODE END Includes */

ADC_HandleTypeDef hadc1;
DMA_HandleTypeDef hdma_adc1;

DAC_HandleTypeDef hdac1;

I2C_HandleTypeDef hi2c2;

SAI_HandleTypeDef hsai_BlockA1;
SAI_HandleTypeDef hsai_BlockB1;
DMA_HandleTypeDef hdma_sai1_a;
DMA_HandleTypeDef hdma_sai1_b;

SPI_HandleTypeDef hspi2;
DMA_HandleTypeDef hdma_spi2_tx;
DMA_HandleTypeDef hdma_spi2_rx;

TIM_HandleTypeDef htim1;
TIM_HandleTypeDef htim2;
TIM_HandleTypeDef htim3;
TIM_HandleTypeDef htim4;
TIM_HandleTypeDef htim5;
TIM_HandleTypeDef htim6;

TSC_HandleTypeDef htsc;

UART_HandleTypeDef huart3;
DMA_HandleTypeDef hdma_usart3_tx;
DMA_HandleTypeDef hdma_usart3_rx;

PCD_HandleTypeDef hpcd_USB_OTG_FS;

/* USER CODE BEGIN PV */
// https://github.com/STMicroelectronics/STMems_Standard_C_drivers/blob/master/lis2dh12_STdC/example/lis2dh12_read_data_polling.c
#include "lis2dh12_reg.h"
#define SENSOR_BUS hi2c2

static int32_t platform_write(void *handle, uint8_t reg,
                              uint8_t *bufp,
                              uint16_t len)
{
  /* Write multiple command */
  reg |= 0x80;
  HAL_I2C_Mem_Write(handle, LIS2DH12_I2C_ADD_L, reg,
                    I2C_MEMADD_SIZE_8BIT, bufp, len, I2C_TIMEOUT);
  return 0;
}


static int32_t platform_read(void *handle, uint8_t reg, uint8_t *bufp,
                             uint16_t len)
{
  /* Read multiple command */
  reg |= 0x80;
  HAL_I2C_Mem_Read(handle, LIS2DH12_I2C_ADD_L, reg,
                   I2C_MEMADD_SIZE_8BIT, bufp, len, I2C_TIMEOUT);
  return 0;
}

stmdev_ctx_t accelerometer = {
		  .write_reg = platform_write,
		  .read_reg = platform_read,
		  .handle = &SENSOR_BUS
};

/* USER CODE END PV */

void SystemClock_Config(void);
static void MX_GPIO_Init(void);
static void MX_DMA_Init(void);
static void MX_USART3_UART_Init(void);
static void MX_TIM1_Init(void);
static void MX_TIM2_Init(void);
static void MX_TIM4_Init(void);
static void MX_TSC_Init(void);
static void MX_I2C2_Init(void);
static void MX_ADC1_Init(void);
static void MX_DAC1_Init(void);
static void MX_SAI1_Init(void);
static void MX_SPI2_Init(void);
static void MX_TIM3_Init(void);
static void MX_TIM6_Init(void);
static void MX_TIM5_Init(void);
static void MX_USB_OTG_FS_PCD_Init(void);
/* USER CODE BEGIN 0 */
extern volatile u8 gotclkin;

//void HAL_GPIO_EXTI_Callback(uint16_t GPIO_Pin) {
//	gotclkin++;
//}
u8 lastencstate=0;
extern volatile int encval;
extern volatile u8 encbtn;
const static s8 encdeltas[16]={
		 0, 1,-1, 0,
		-1, 0, 0, 1,
		 1, 0, 0,-1,
		 0,-1, 1, 0
};
static inline u8 ReadEncState(void) {
	return (GPIOC->IDR >> 14)&3;
}
extern float encaccel;
void EncoderTick(void) {
    encbtn = !((GPIOC->IDR >> 13) & 1) ;
	u8 newstate=ReadEncState();
	int st=lastencstate + (newstate<<2);
    int oldencval = encval;
	if (newstate==3) //if (st==15)
		encval=((encval>>2)<<2)+2; // snap to the middle of a sector when the switch is idle for 2ms
	else
		encval-=encdeltas[st];
    encaccel *= 0.998f;
    encaccel += abs(oldencval - encval) * 0.125f;
	lastencstate=newstate;
}

extern volatile bool clkin_is_euro;

void ClockIRQ(void){
	gotclkin++;
  clkin_is_euro = true;
}

int16_t accel_raw[3];
float accel_lpf[2];
float accel_smooth[2];
bool update_accelerometer_raw(void) {
	if (!accelerometer.handle) return false;
	    lis2dh12_reg_t reg;
	    lis2dh12_xl_data_ready_get(&accelerometer, &reg.byte);
	    if (!reg.byte)
	    	return false;
	  /* Read accelerometer data */
	  int16_t tmp[3]={0,0,0 };
	  lis2dh12_acceleration_raw_get(&accelerometer, tmp);
	  accel_raw[0]=tmp[0];
	  accel_raw[1]=tmp[1];
	  accel_raw[2]=tmp[2];
	  return true;
}

int miditest(void);
void midiinit(void);

/* USER CODE END 0 */

/**
  * @brief  The application entry point.
  * @retval int
  */
int main(void)
{
  /* MCU Configuration--------------------------------------------------------*/

  /* Reset of all peripherals, Initializes the Flash interface and the Systick. */
  HAL_Init();

  /* Configure the system clock */
  SystemClock_Config();

  /* Initialize all configured peripherals */
  MX_GPIO_Init();
  MX_DMA_Init();
  MX_USART3_UART_Init();
  MX_TIM1_Init();
  MX_TIM2_Init();
  MX_TIM4_Init();
  MX_TSC_Init();
  MX_I2C2_Init();
  MX_ADC1_Init();
  MX_DAC1_Init();
  MX_SAI1_Init();
  MX_SPI2_Init();
  MX_TIM3_Init();
  MX_TIM6_Init();
  MX_TIM5_Init();
  MX_USB_OTG_FS_PCD_Init();
  /* USER CODE BEGIN 2 */
  // check if the bootloader wants us to flash

  HAL_Delay(8);
  uint8_t whoamI=0;
  lis2dh12_device_id_get(&accelerometer, &whoamI);
  if (whoamI != LIS2DH12_ID) {
      accelerometer.handle=0;
    } else {
	  lis2dh12_block_data_update_set(&accelerometer, PROPERTY_ENABLE);
	  lis2dh12_data_rate_set(&accelerometer, LIS2DH12_ODR_100Hz);
	  lis2dh12_full_scale_set(&accelerometer, LIS2DH12_2g);
	  lis2dh12_temperature_meas_set(&accelerometer, LIS2DH12_TEMP_DISABLE);
	  lis2dh12_operating_mode_set(&accelerometer, LIS2DH12_HR_12bit);
/* accel debug
	  while (1) {
		  update_accelerometer_raw();
		  DebugLog("accel %5d %5d %5d\r\n",accel_raw[0], accel_raw[1], accel_raw[2]);
		  HAL_Delay(100);
	  }
	  */
    }


  //check_bootloader_flash(); // used to be here, but now we do it in plinky_init

  //  miditest();


#ifdef NEW_PINOUT
// for the new pinout, we use the stm's internal voltage reference
  HAL_SYSCFG_VREFBUF_VoltageScalingConfig(SYSCFG_VREFBUF_VOLTAGE_SCALE1);
  HAL_SYSCFG_EnableVREFBUF();
  HAL_SYSCFG_VREFBUF_HighImpedanceConfig(SYSCFG_VREFBUF_HIGH_IMPEDANCE_DISABLE);
  #else
// for the old pinout, pd0 is the cs line, needs to be fast!
  GPIO_InitTypeDef GPIO_InitStruct = { 0 };
  GPIO_InitStruct.Pin = GPIO_PIN_0;
  GPIO_InitStruct.Mode = GPIO_MODE_OUTPUT_PP;
  GPIO_InitStruct.Pull = GPIO_NOPULL;
  GPIO_InitStruct.Speed = GPIO_SPEED_FREQ_VERY_HIGH;
  HAL_GPIO_Init(GPIOD, &GPIO_InitStruct);
  // pd14 is not a timer, its gpiout for N4. hopefully this undoes the timer config of tim4 ch3 in TIM4_Init
  GPIO_InitStruct.Pin = GPIO_PIN_14;
  GPIO_InitStruct.Mode = GPIO_MODE_OUTPUT_PP;
  GPIO_InitStruct.Pull = GPIO_NOPULL;
  GPIO_InitStruct.Speed = GPIO_SPEED_LOW;
  HAL_GPIO_Init(GPIOD, &GPIO_InitStruct);
#endif

//	DebugLog("plinky black 0.1\r\n");
  void plinky_init(void);
  plinky_init();
  gotclkin=0;
  lastencstate=ReadEncState();
  encval=2;
  /* USER CODE END 2 */

  /* Infinite loop */
  /* USER CODE BEGIN WHILE */

  midiinit();

	while (1) {
    /* USER CODE END WHILE */

    /* USER CODE BEGIN 3 */
		void plinky_frame(void);
		plinky_frame();


	}
  /* USER CODE END 3 */
}

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


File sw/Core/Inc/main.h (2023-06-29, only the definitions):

#define CVOUT_TRIG_Pin GPIO_PIN_6
#define CVOUT_TRIG_GPIO_Port GPIOE
#define IO1_Pin GPIO_PIN_13
#define IO1_GPIO_Port GPIOC
#define IO2_Pin GPIO_PIN_14
#define IO2_GPIO_Port GPIOC
#define IO3_Pin GPIO_PIN_15
#define IO3_GPIO_Port GPIOC
#define CVOUT_CLK_Pin GPIO_PIN_0
#define CVOUT_CLK_GPIO_Port GPIOB
#define CLKIN_Pin GPIO_PIN_2
#define CLKIN_GPIO_Port GPIOB
#define CLKIN_EXTI_IRQn EXTI2_IRQn
#define SENSE1_Pin GPIO_PIN_8
#define SENSE1_GPIO_Port GPIOE
#define SENSE2_Pin GPIO_PIN_15
#define SENSE2_GPIO_Port GPIOE
#define N5_Pin GPIO_PIN_15
#define N5_GPIO_Port GPIOD
#define DEBUG_Pin GPIO_PIN_8
#define DEBUG_GPIO_Port GPIOA
#define N4_Pin GPIO_PIN_0
#define N4_GPIO_Port GPIOD
#define N1_Pin GPIO_PIN_2
#define N1_GPIO_Port GPIOD
#define N2_Pin GPIO_PIN_5
#define N2_GPIO_Port GPIOD
#define N3_Pin GPIO_PIN_7
#define N3_GPIO_Port GPIOD
#define CS2_Pin GPIO_PIN_0
#define CS2_GPIO_Port GPIOE
#define CS1_Pin GPIO_PIN_1
#define CS1_GPIO_Port GPIOE

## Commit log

2023-06-29 Initial Filedump
    Tadaaa!!
    [lfoshapes.xlsx, params.txt, plinkyblack Debug.cfg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]
2023-06-29 add jlc bom and pos files
    [bom.csv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]
2023-06-29 add testjig
    [testjig.dsn, testjig.kicad_pcb, testjig.sch]
2023-06-30 fix from lpzw modules for MIDI Sync
    [plinky.c]
2023-06-30 WIP Input Noise Fix
    [plinkyblack.kicad_sch]
2023-06-30 Initial Clean Up Run
    - change many passives to 0402
    - change TL072's to the same SOIC package
    - finish up routing for topside input buffer
    - add diodes for +- 12 from eurorack input (untested)
    - change some board limits to represent current manufacturing reality
    - hunt down a lot of DRC errors (lots of warnings remaining!)
    - made hole for expander bigger
    - fixedsys fonts + text label moving about
    - todo: reset labels for 0402 parts since my standard library has the labels taken off.
    [plinkyblack.kicad_sch]
2023-07-01 move old files into v2, and add an overall BOM
    [bom.csv, plinkyblack.kicad_pcb, plinkyblack.sch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]
2023-07-25 add python script for bundling bootloader and main app; also fix compile errors in new ide version
    [plinky.c]
2023-07-25 fix case typo in include path
2023-08-02 add hardware midi variation
    [plinkyblack_hwmidi.kicad_sch]
2023-08-02 update STM chip LCSC part number
    [plinkyblack_hwmidi.kicad_sch]
2023-10-04 text cleanup, add license text to pcb
2023-10-04 remove old files
    [plinkyblack_base.kicad_pcb, plinkyblackfront_countersink_wip.kicad_pcb]
2023-10-04 remove more old files
    [plinkyblackfront.dsn, plinkyblackfront_bad_pad_hand_removed.kicad_pcb, plinkyblackfront_bad_pad_hand_removed.step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]
2023-10-04 add front panel bom
    [plinkyblackfront-bom.csv]
2023-10-04 add oss text to pcbs
    [plinkyblack.kicad_pcb, plinkyblackfront.kicad_pcb]
2023-10-04 remove kicad fluff
2023-10-04 bigholes version with led part numbers
    [plinkyblackfront.kicad_sch, plinkyblackfront_bigholes.kicad_pcb, plinkyblackfront_bigholes.kicad_sch]
2023-10-06 create variation with USB-C and SMD audio jacks
    [20231005_plinkyblack_hwmidi_bom.csv, 20231005_plinkyblack_hwmidi_positions.csv, TYPE-C-31-M-12--3DModel-STEP-56544.STEP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]
2023-10-07 production adjustments and convert testjig to kicad7
    [20231006_plinkyblack_hwmidi_jacks_bom.csv, 20231006_plinkyblack_hwmidi_jacks_positions.csv, designators.csv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]
2023-10-27 midi+jacks fixes
    Moved 5V pogo pin pad
    de-plated encoder jack lug for less assembly errors
    [20231006_plinkyblack_hwmidi_jacks_bom.csv, 20231006_plinkyblack_hwmidi_jacks_positions.csv, bom.csv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]
2023-12-21 Create ibom.html
    add html bom
2023-12-22 Fix 5.1k part number, verify others
    [plinkyblack_hwmidi_jacks.kicad_sch]
2024-01-08 add new test points to main board and jig
    [plinkyblack Debug.cfg, plinkyblack_hwmidi_jacks.kicad_sch]
2024-01-27 Kicad files for Plinky v3, added testpoints and fixed Testjig
    [TYPE-C-31-M-12--3DModel-STEP-56544.STEP, bom.csv, plinkyblack_hwmidi_jacks.kicad_sch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]
2024-01-27 Set UART3 baud rate to 31250 (MIDI baud rate)
2024-02-23 create opensource front/back panels
    [plinky_back_osh.kicad_pcb, plinky_front_osh.kicad_pcb, plinky_front_osh.kicad_sch]
2024-03-15 Serial MIDI Sync fix
    [plinkyblack Debug.cfg]
2024-07-04 USB MIDI Init Bug Fixed
    [config.h, main.c]
2024-07-05 Disables Merge Playback, adds Disable Autosave flag (off by default)
    Cleaned up build files to adhere to this naming convention -
    plink0A3.bin
    plink0A3.uf2
    so one can match the versions.
    Deleted some extra build files to the root -
    deleted CURRENT.uf2 (which could be any version)
    deleted plinkyblack.bin (which can't be flashed on its own)
    Plinky V0.A3.zip (different naming convention) -> took CURRENT.UF2 from the zip and renamed it plink0A3.uf2
    Disabled MERGE_PLAYBACK in touch.h
    Added a define DISABLE_AUTOSAVE.
    It's commented out by default. It enables Superbooth Demo Mode:
    changes are not written to flash, a reboot restores the device completely.
    Disables ProgramPage() in params.h.
    Adde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
    [config.h, params.h, touch.h]
2024-07-11 WIP v3.1 LPZW added
    [TYPE-C-31-M-12--3DModel-STEP-56544.STEP, plinkyblack_hwmidi_jacks.kicad_sch]
2024-07-12 no DRC errors, but not confirmed working
    [plinkyblack_hwmidi_jacks-B_Cu.gbr, plinkyblack_hwmidi_jacks-B_Mask.gbr, plinkyblack_hwmidi_jacks-B_Paste.gbr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]
2024-08-01 fixes Encoder response for headphone volume
    [config.h, edit.h, params.h]
2024-11-06 fix the plinky bootloader to work on mac
    [ghostfat.c, main.c]
2024-11-07 first baby steps at extending the webusb protocol to longer messages, processed faster, and add messages to read spi and wavetable ram
2024-11-10 sample editor; this is before backtracking on contiguous mode
2025-01-23 Hw midi input fix
    [plinky.c]
2025-01-23 bump version to A8 with RJ-Eckie's midi fixes
    [config.h]
2025-01-24 Auto revert to internal clock
    [arp.h]
2025-02-02 Maintain midi pitch through release
2025-02-03 add init for pressure
2025-02-03 fix (almost?) all warnings
    [calib.h, edit.h, leds.h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]
2025-02-04 Tweak midi pressure
2025-02-05 Midi persists after being cut off
2025-02-08 Revert "Tweak midi pressure"
    This reverts commit b654dcacbc4f932fde8008109f8a418be22971a3.
    [touch.h]
2025-02-08 rearrange the hw folder and update the readmes
    [TYPE-C-31-M-12--3DModel-STEP-56544.STEP, bom.csv, plinkyblack.kicad_pcb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]
2025-02-08 move computation of pitch inside the oscillator loop because each one can b eslightly different
    [plinky.c]
2025-02-08 fix detune loss; update B0 version; add shell script to just build a release build in one command; rename old binmaker to cubeide_ to make it clear it reads cubeide output; add bootloader checksum ch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
    [plinky.c, touch.h]
2025-02-19 tweak to DISABLE_AUTOSAVE flag
    The flag used to be in void ProgramPage().
    This caused a hangup in PumpFlashWrites(), when presets were switched. Instead I have moved the flag into the WritePattern() and WritePreset() function (the things we want to avoid writing when in demo mode), with the added bonus of still being able to record samples.
    The DISABLE_AUTOSAVE flag is only relevant for demoing Plinky at shows like Superbooth but allows for a complete recall into a preset state on power cycle.
    [params.h]
2025-05-19 Revert octave param range
    [params.h]
2025-05-21 tested pin detect on hardware, got rid of compiler flag
2025-05-26 No audio in sample edit mode fix
    [touch.h]
2025-06-03 Map microtone to midi pitch spread
2025-08-19 Adjusted calib check for Plinky+
    A good calibration would sometimes fail at calibration check, throwing a false short diagnosis.
    [calib.h, config.h]

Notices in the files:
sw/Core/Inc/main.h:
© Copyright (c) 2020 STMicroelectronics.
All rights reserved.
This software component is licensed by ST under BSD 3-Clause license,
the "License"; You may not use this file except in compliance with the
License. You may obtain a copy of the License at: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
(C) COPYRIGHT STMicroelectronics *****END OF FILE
